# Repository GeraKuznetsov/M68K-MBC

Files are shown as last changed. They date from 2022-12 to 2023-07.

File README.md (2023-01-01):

A M68k Multi-Board Computer design. The design basics is as follows:
1) A backplane PCB contains the majority of the bus, such as the address and data lines.
2) Cards slot into the backplane. Cards other then the CPU card should have bus buffers to lower the bus load. (I might give the CPU card buffers too).
3) The 68k's 16MB memory map is split into 16 1MB regions. This is because the two memory chips used, the sst39f040 flash and AS6C4008 ram are both 0.5MB. (So when you put two of them together to get 16 bits, you end up with 1MB per bank).
4) Address decoding is done by a pair of decoders on the CPU card. The CS lines from a header on the side of the CPU card to headers on the sides of the other cards, ideally with a twisted ground for each CS line. In the future these lines could be moved into the backplane. 
5) If the card is less then 10x10 cm, I make it 4-layer. 4-layer boards bigger then 10x10cm are too expensive. 
6) the connectors are DIN41612
7) Line the 16 CS lines, the 7 interrupt lines are also jumpers you plug into the side of the board. There are also 8 interrupt enable jumpers that need to go from the IO card to the CPU card if you want to use one of the parallel output ports as an interrupt enable status port. 

IO and CPU cards are currently completely untested, and the memory card is missing a chip to enable the card's data transmitters. 

/Schematic/:
The actual MBC schematics
Note: LS components are sometimes used when the library has no corresponding HC part. All parts are meant to be HC, with the exception of LVC in 5v->3v translation (output to SD card) and HCT in 3v->5v translation (input from SD card). You can use ACT (or AC if you are feeling brave) but at <16Mhz there should not be a need for fast ACT/AC buffers/gluelogic, especially due to the 68k's slow bus cycles (in comparison to say a 6502 or a z80).

Schematics/BP - design for the backplane (TESTED)
Schematics/CPU - design for CPU card. (NOT TESTED)
Schematics/IO - design for IO card with SD card, PIO, PS2, RTC. (NOT TESTED)
Schematics/MEMv2 - second version of the memory card, doesn't even have the layout done. (NOT FINISHED)
Schematics/MEMv1 - first version of the memory card, missing 74HC20 and gate to enable the card bus buffers (TESTED)
Schematics/Footpp - various footprints
Schematics/Lib - various symbols

/Code/
WIP code, just testing stuff, will eventually be OS

/sst39f040_inBB/:
Allows you to connect an arduino mega to the backplane and program the flash chips on the memory card in-circuit. 
TODO: document this better
sst39f040_inBB/avr - the arduino mega code
sst39f040_inBB/send.py - script file to send the data, requires serial lib

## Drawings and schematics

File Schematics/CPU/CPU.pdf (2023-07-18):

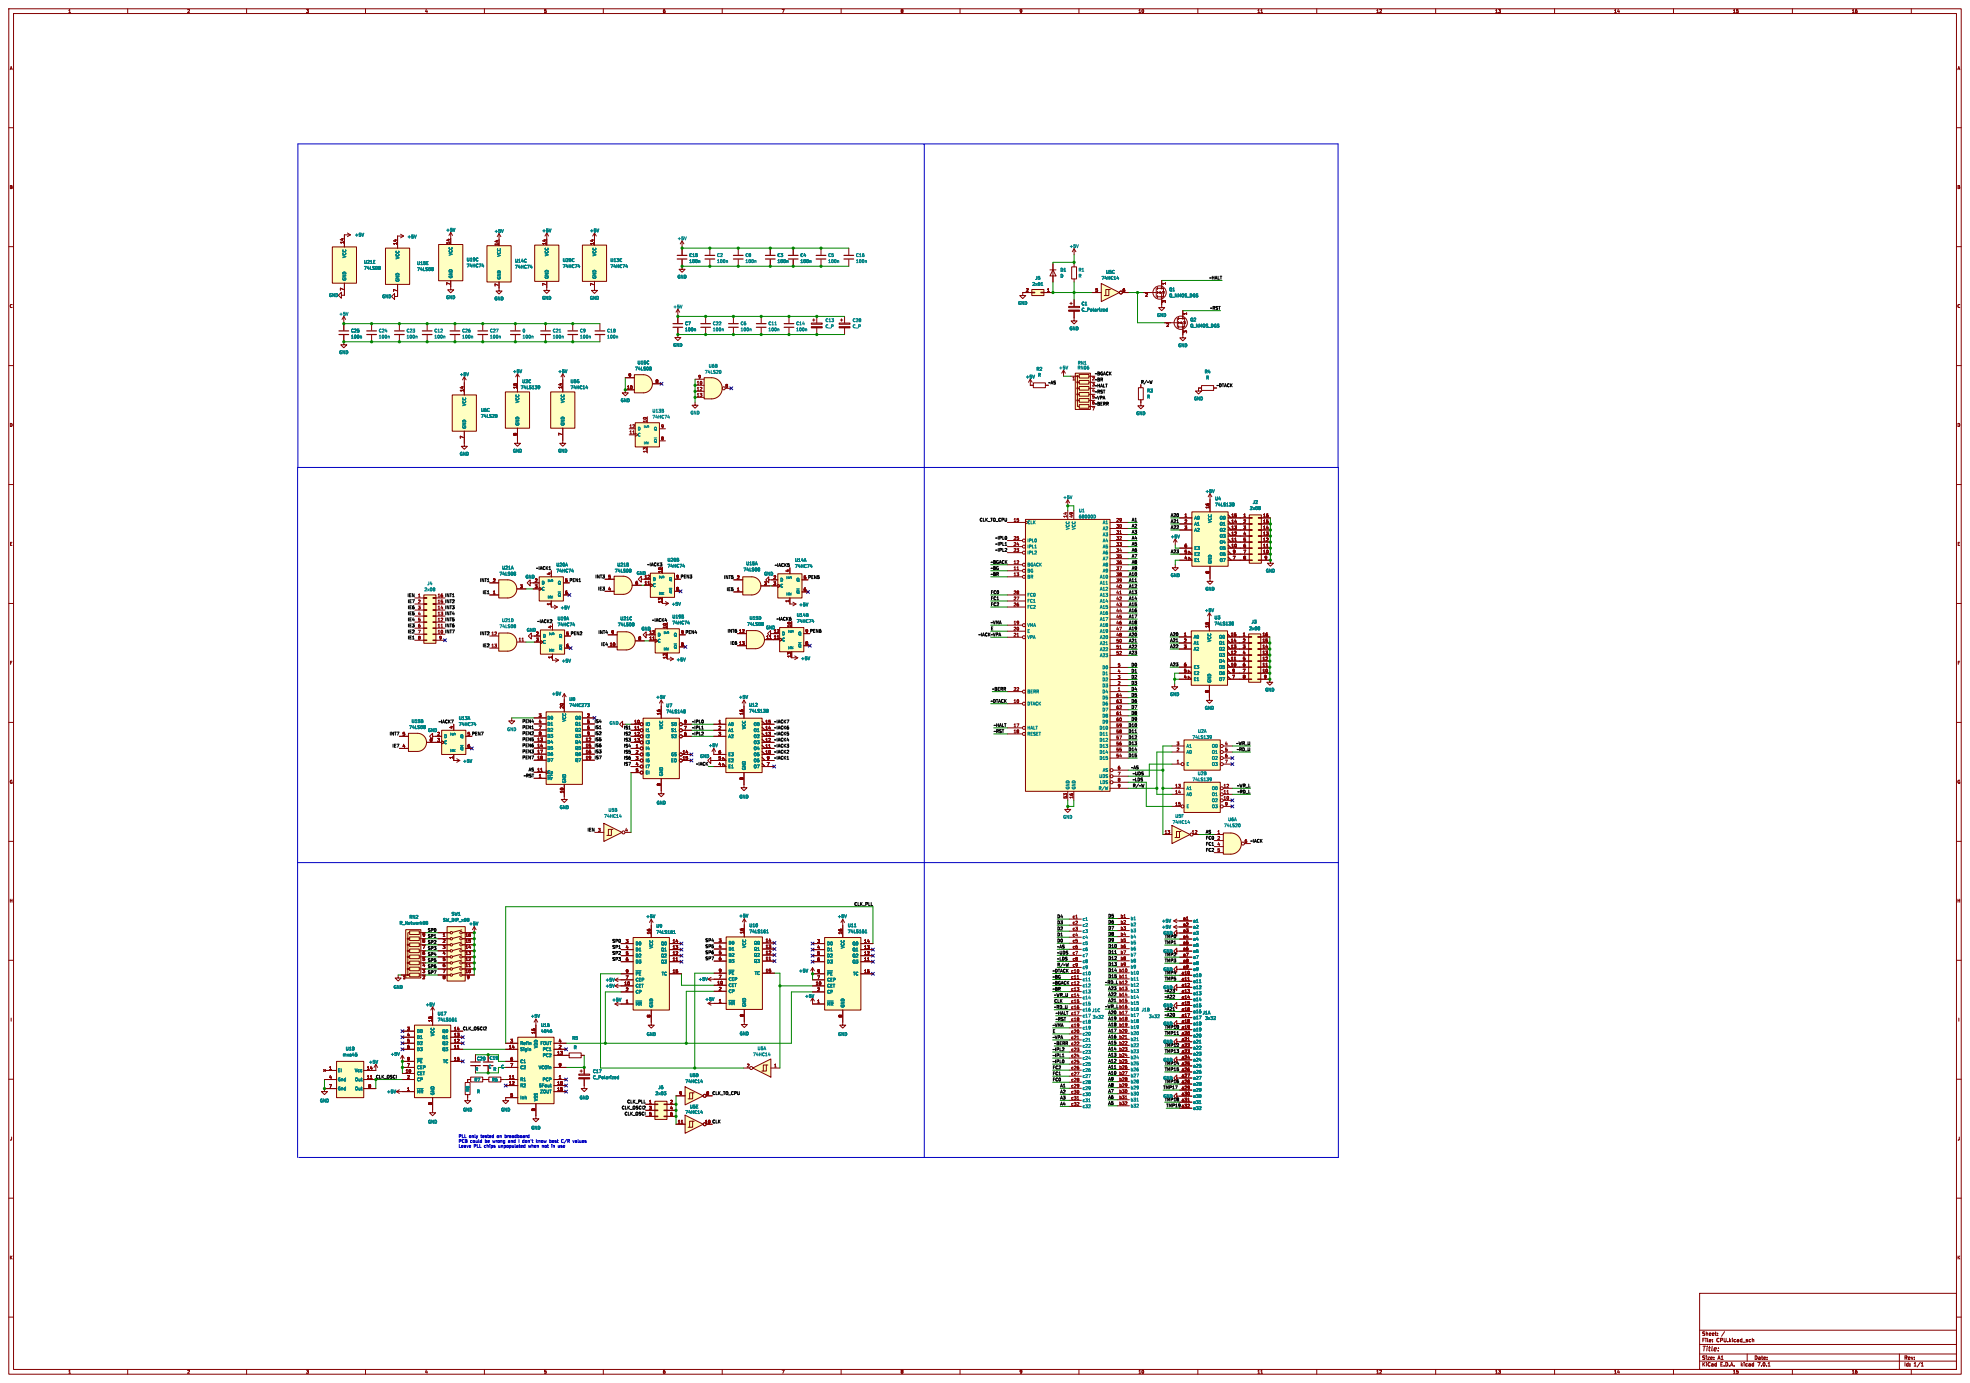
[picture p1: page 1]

Id: 1/1 Title: File: CPU.kicad_sch Sheet: /

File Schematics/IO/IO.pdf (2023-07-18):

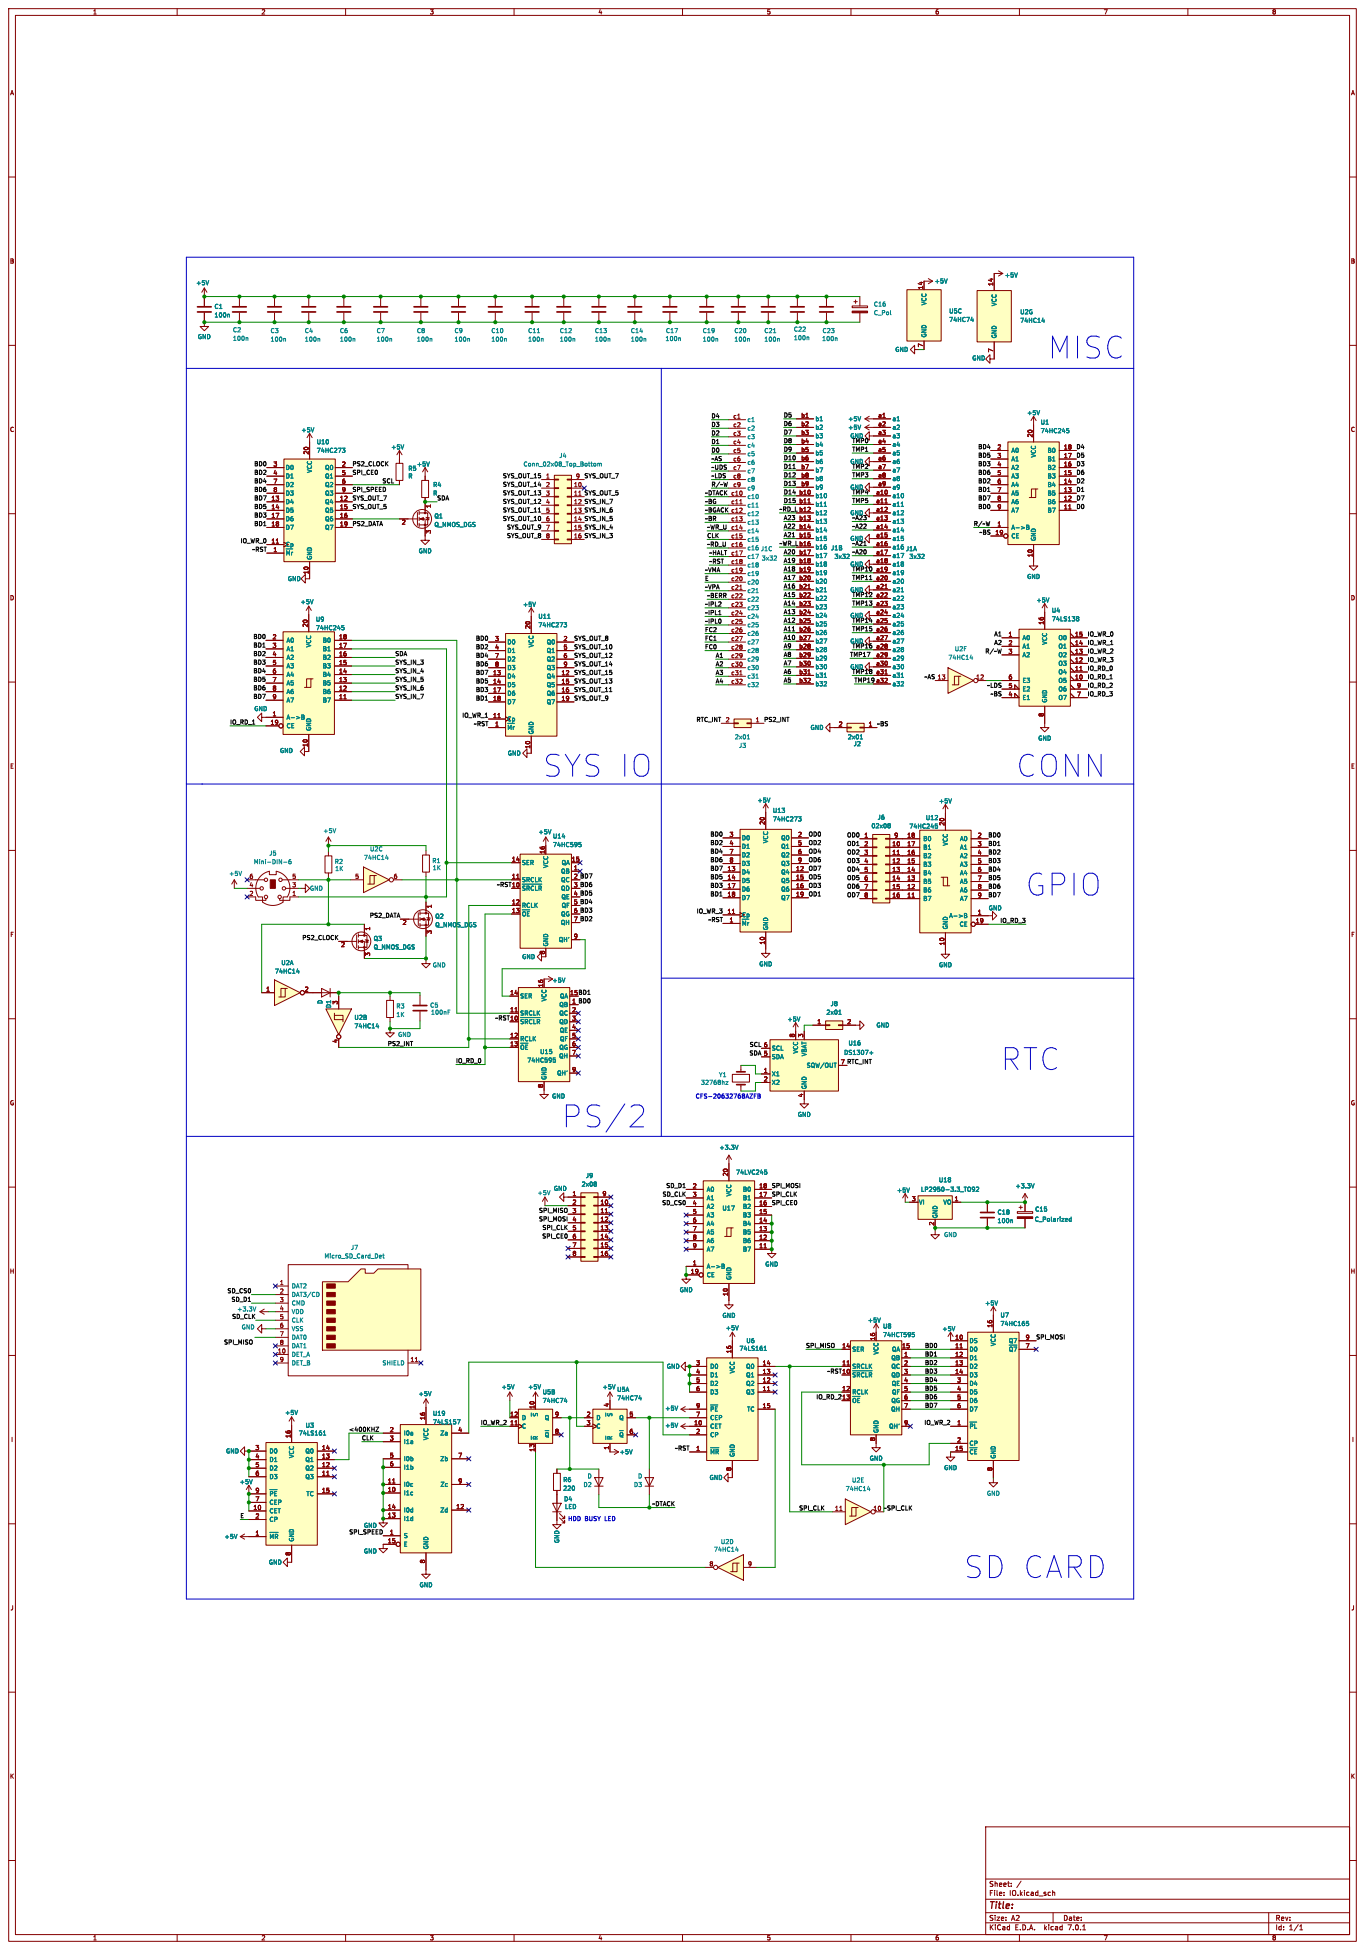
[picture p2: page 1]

7 +5V GND GND GND GND GND GND GND GND GND

HDD BUSY LED SYS IO
+5V GND

4 SDA 5 SCL 6 SQW/OUT 7 VCC

8 ~{PE} 9 +5V GND GND GND

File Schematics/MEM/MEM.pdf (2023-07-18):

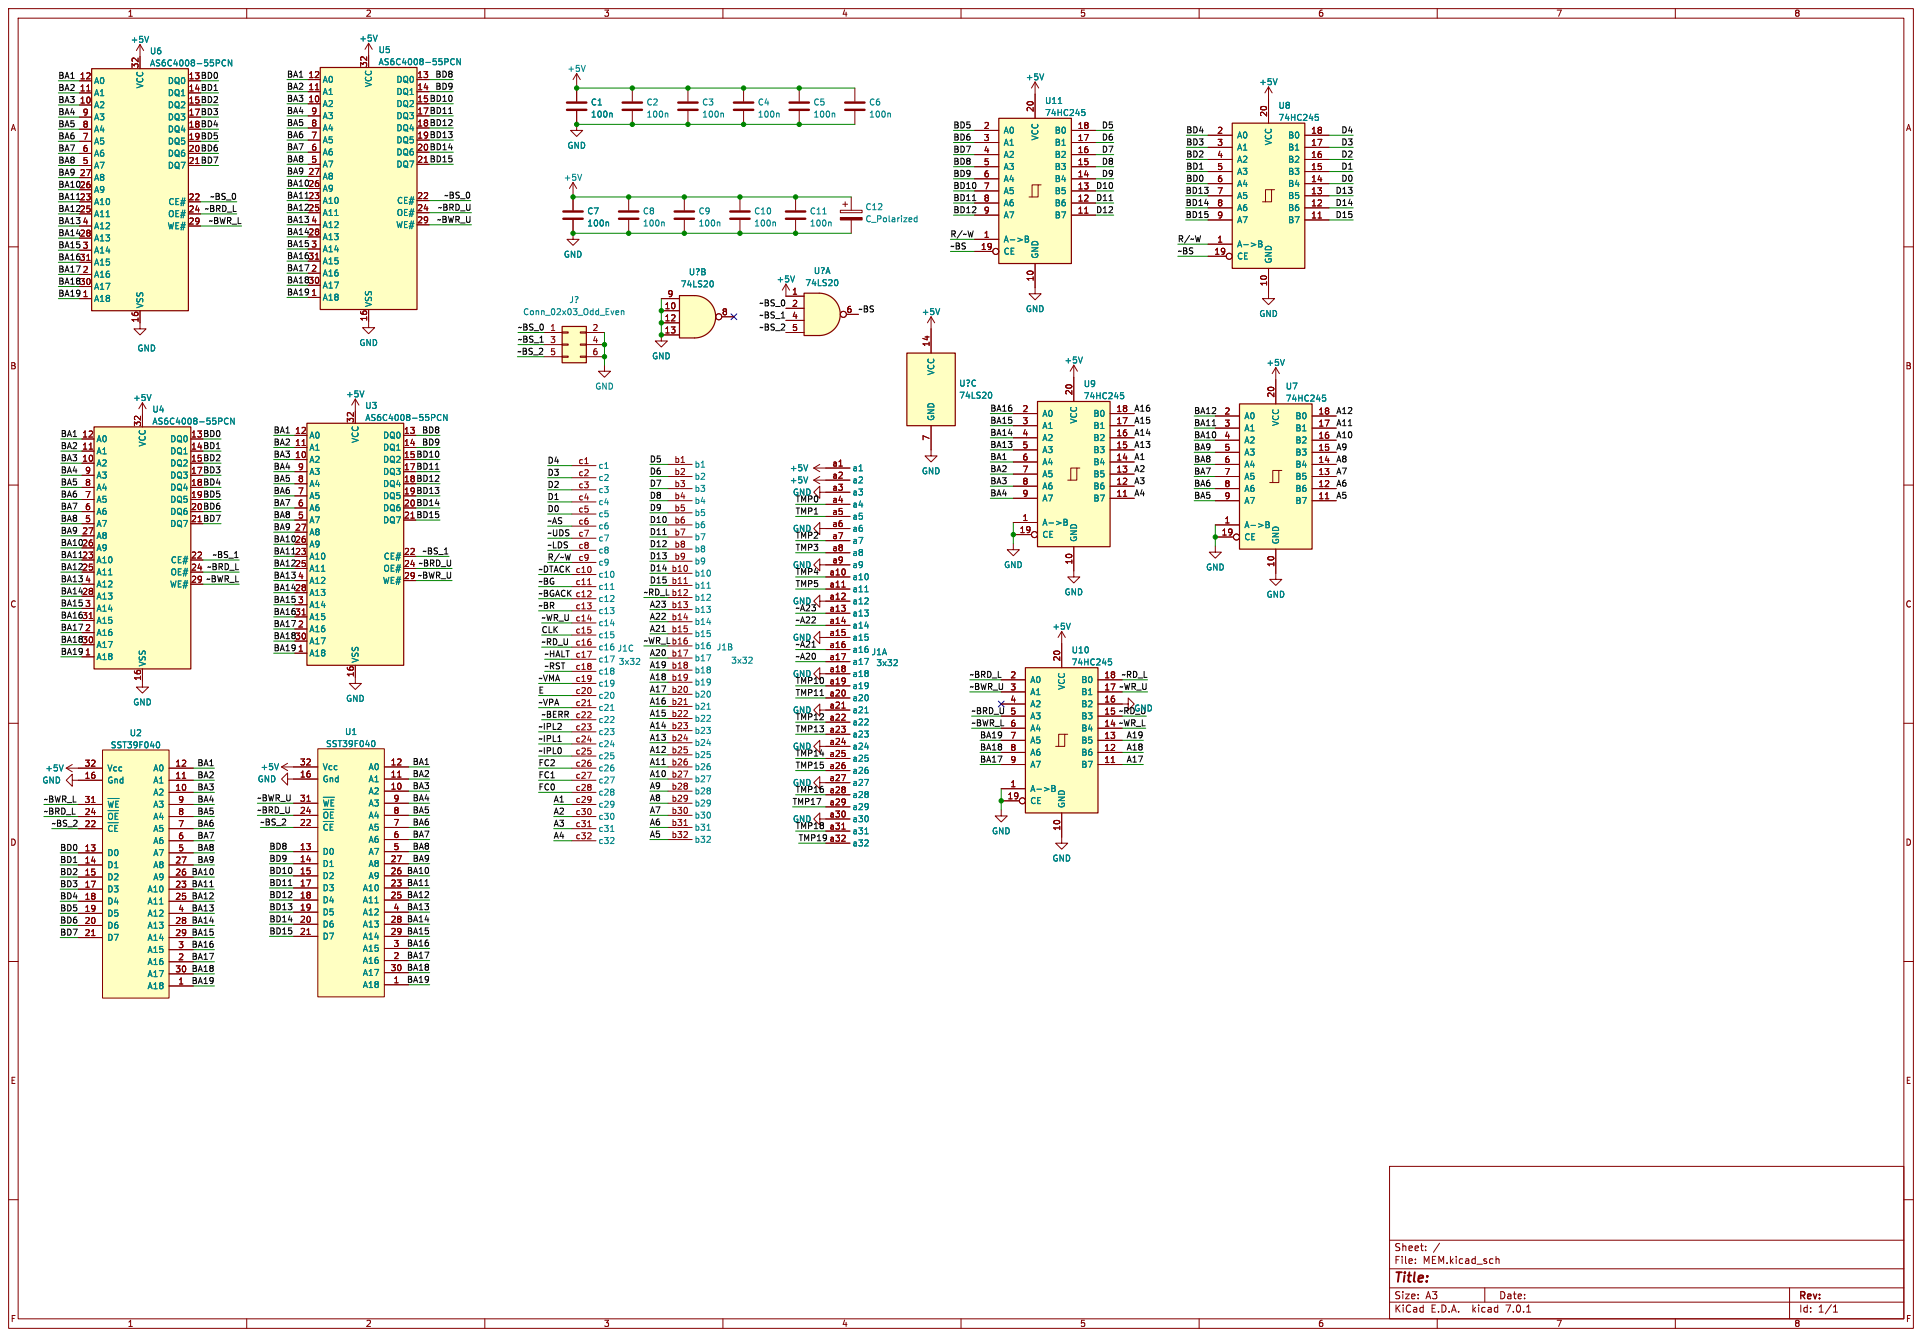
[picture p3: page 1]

+5V GND GND GND GND GND GND

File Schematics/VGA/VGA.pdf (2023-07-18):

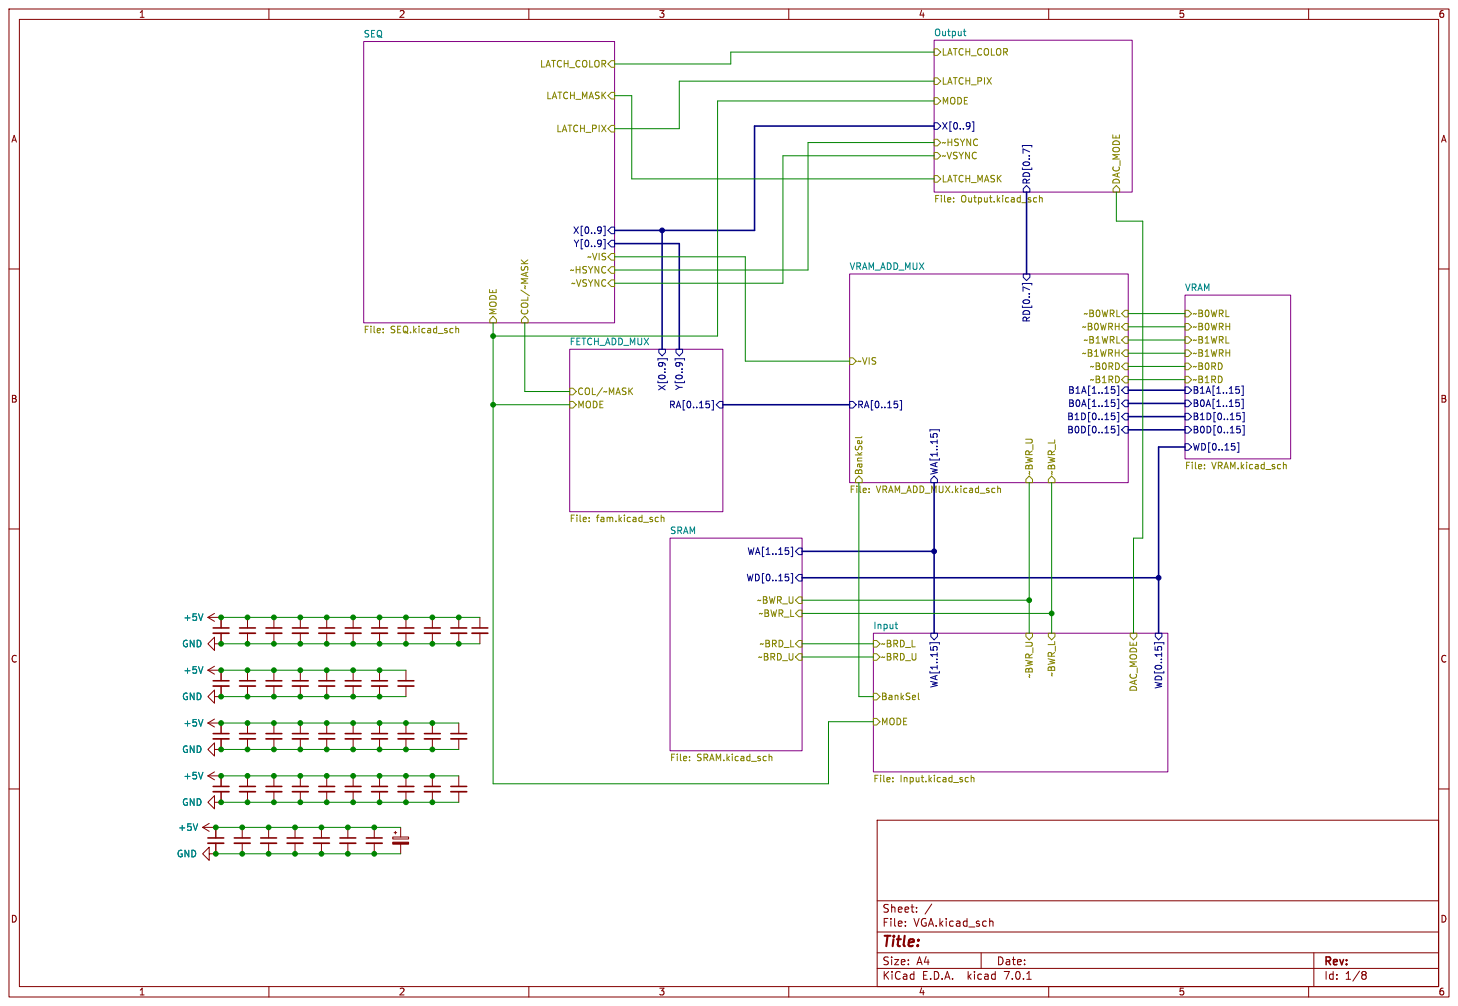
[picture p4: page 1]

Output File: Output.kicad_sch +5V GND GND
LATCH_COLOR MODE
LATCH_PIX COL/~MASK
File: fam.kicad_sch X[0..9]
Y[0..9] ~VIS

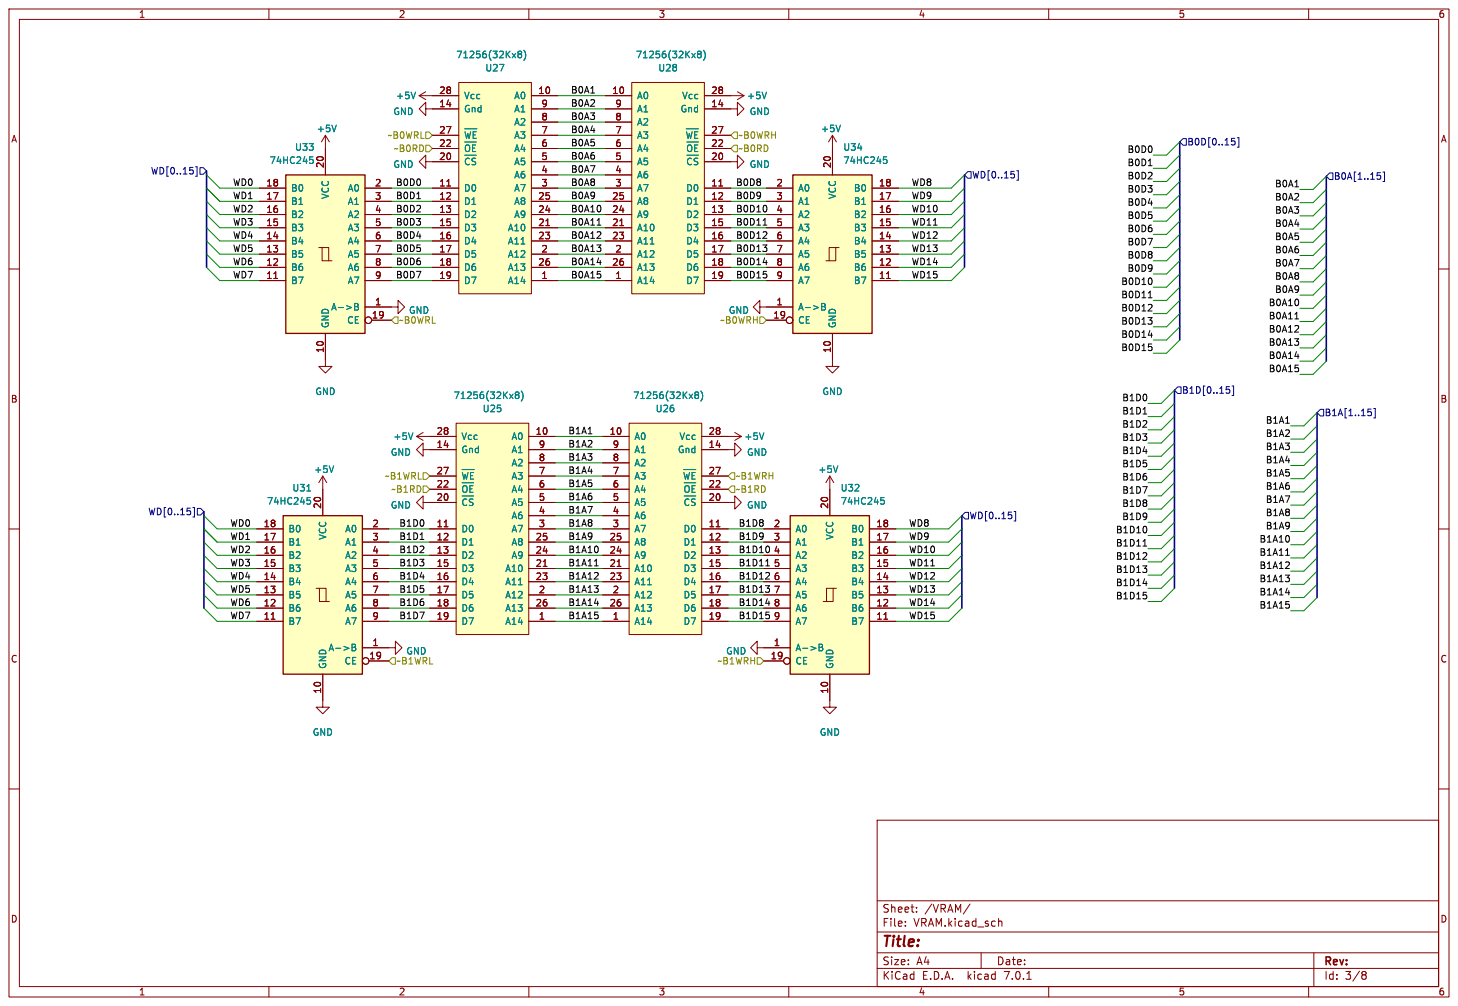
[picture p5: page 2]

Id: 3/8 Title: File: VRAM.kicad_sch Sheet: /VRAM/ GNDGND

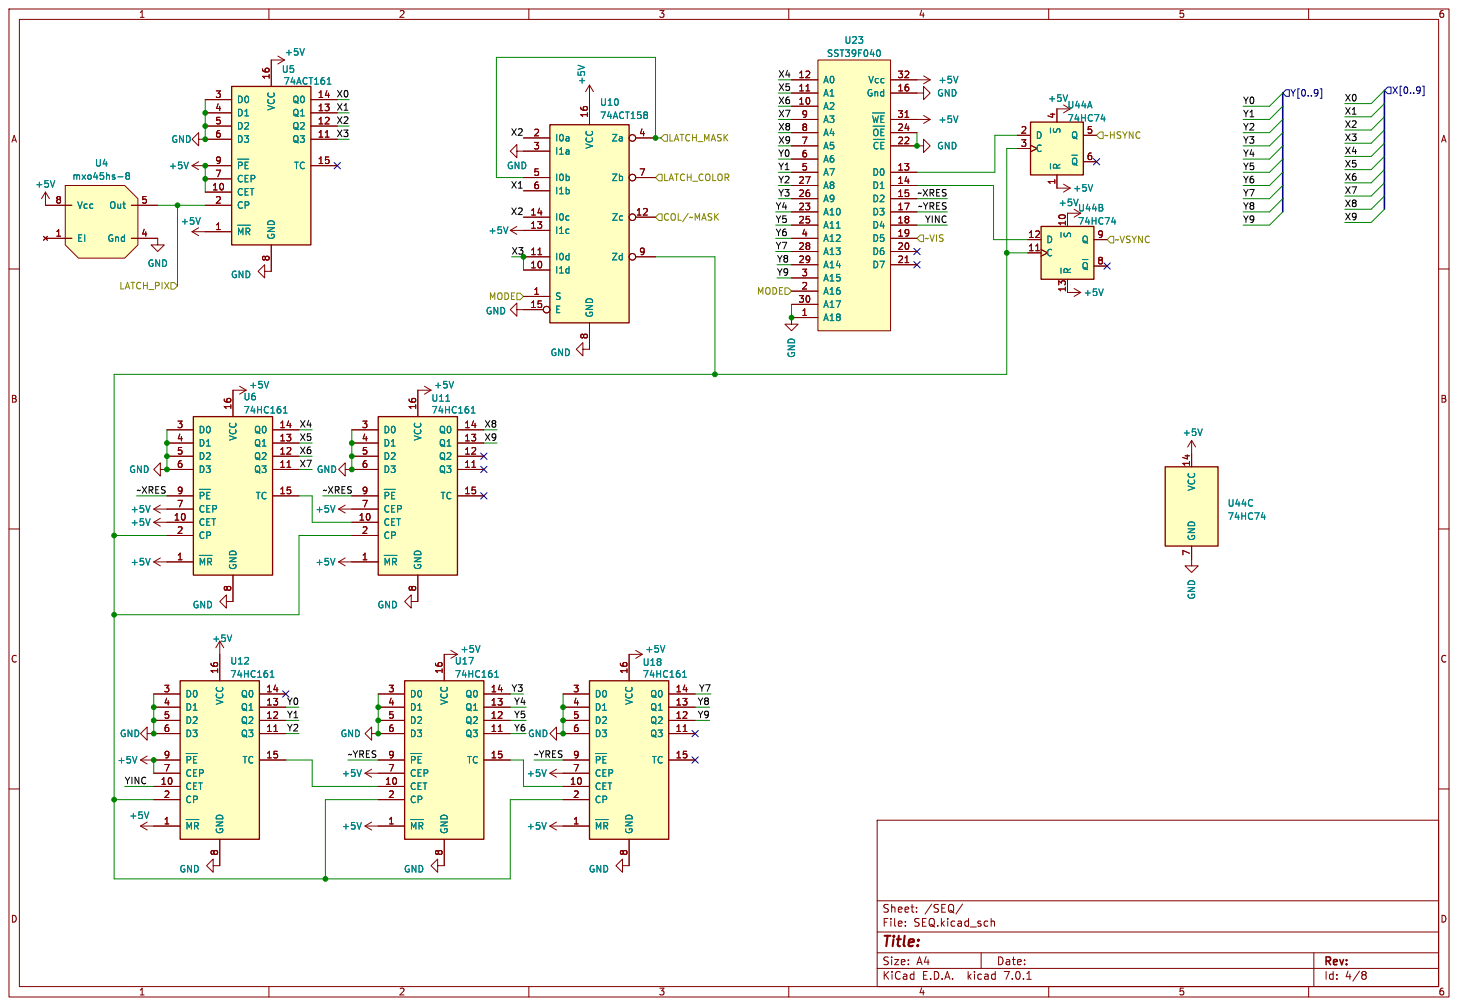
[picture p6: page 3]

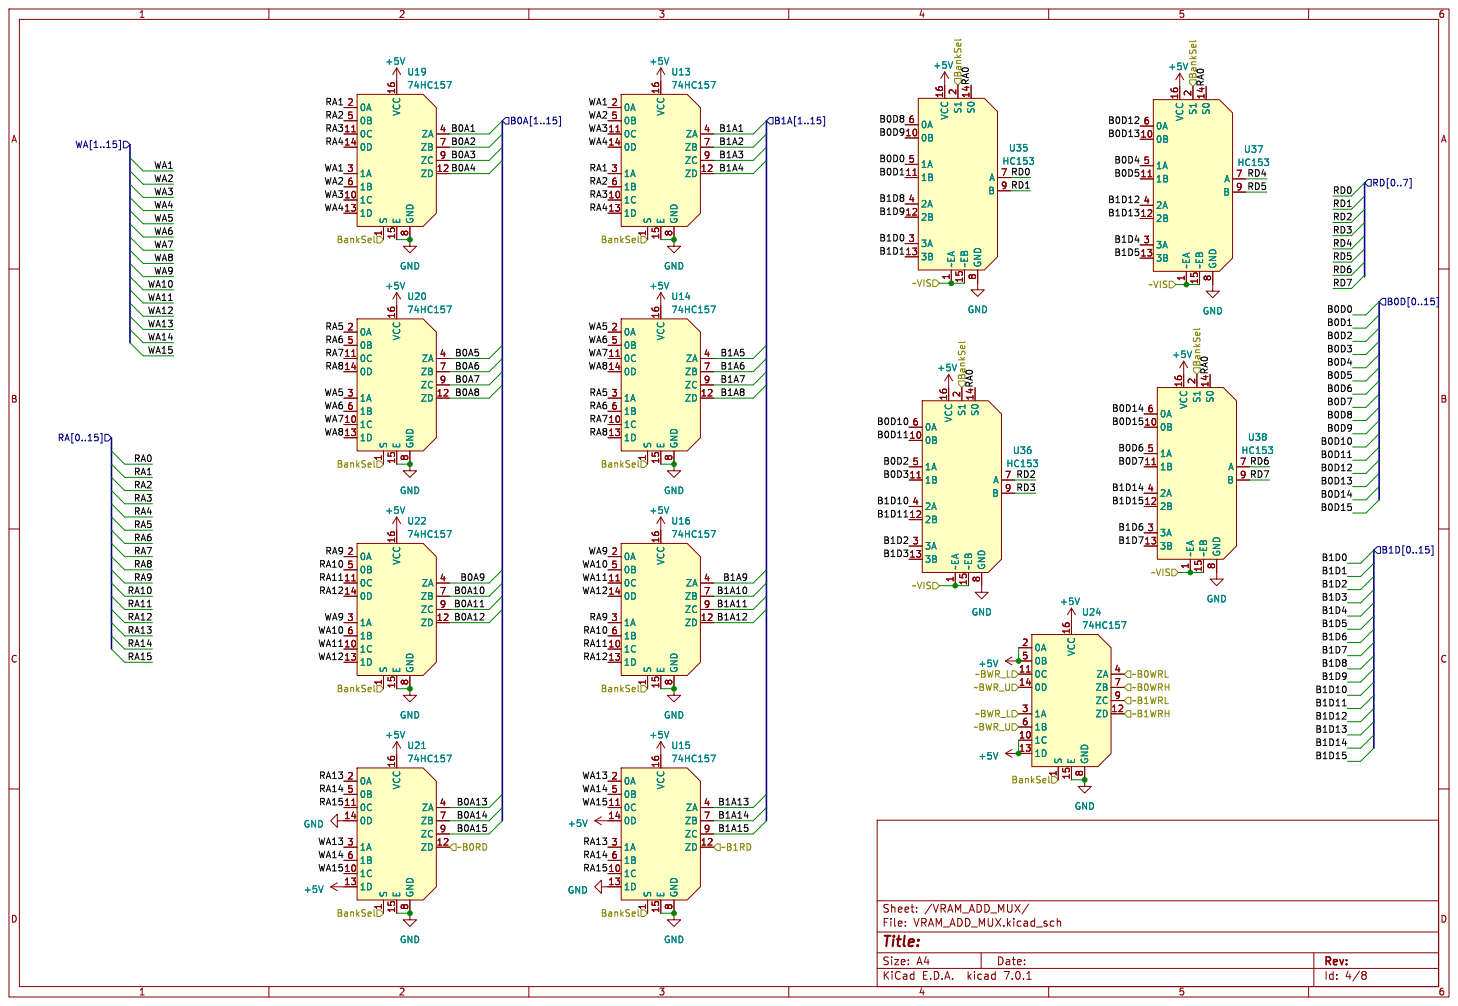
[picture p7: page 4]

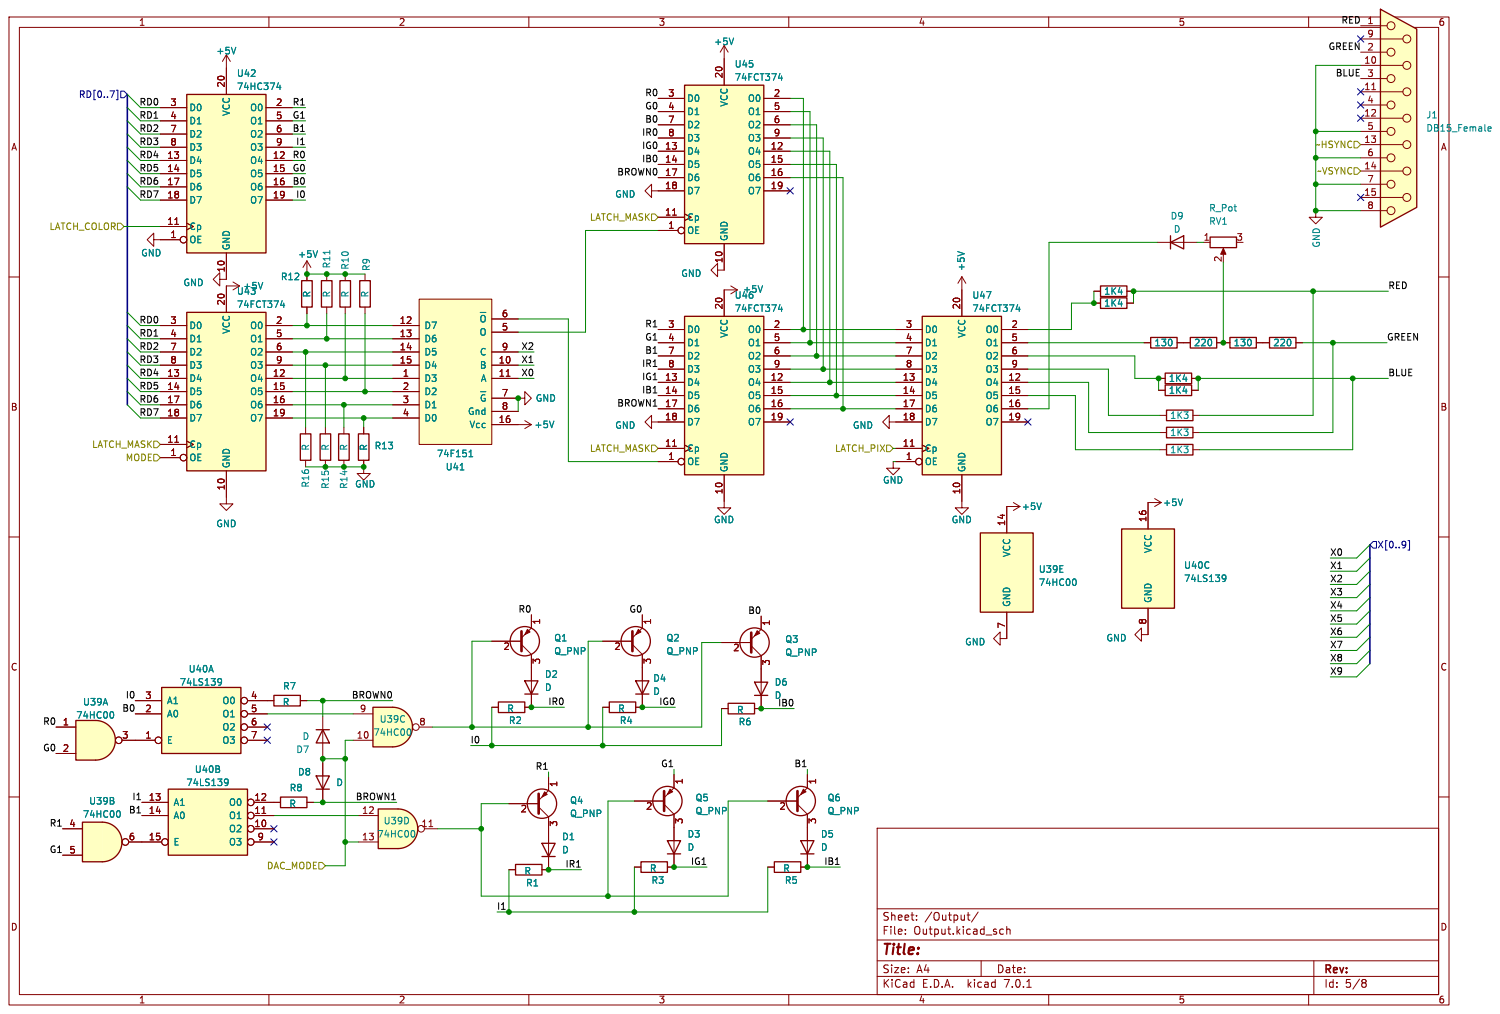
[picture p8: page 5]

Id: 5/8 Title: File: Output.kicad_sch Sheet: /Output/ 1
D3 DQ5 Q_PNP

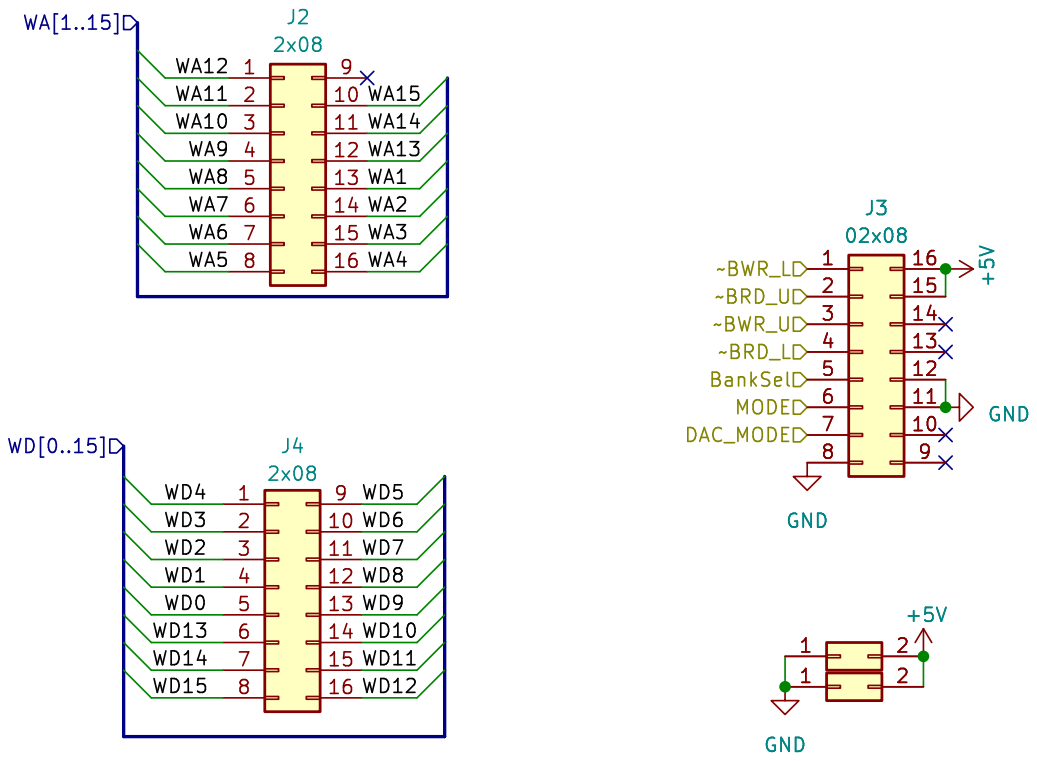
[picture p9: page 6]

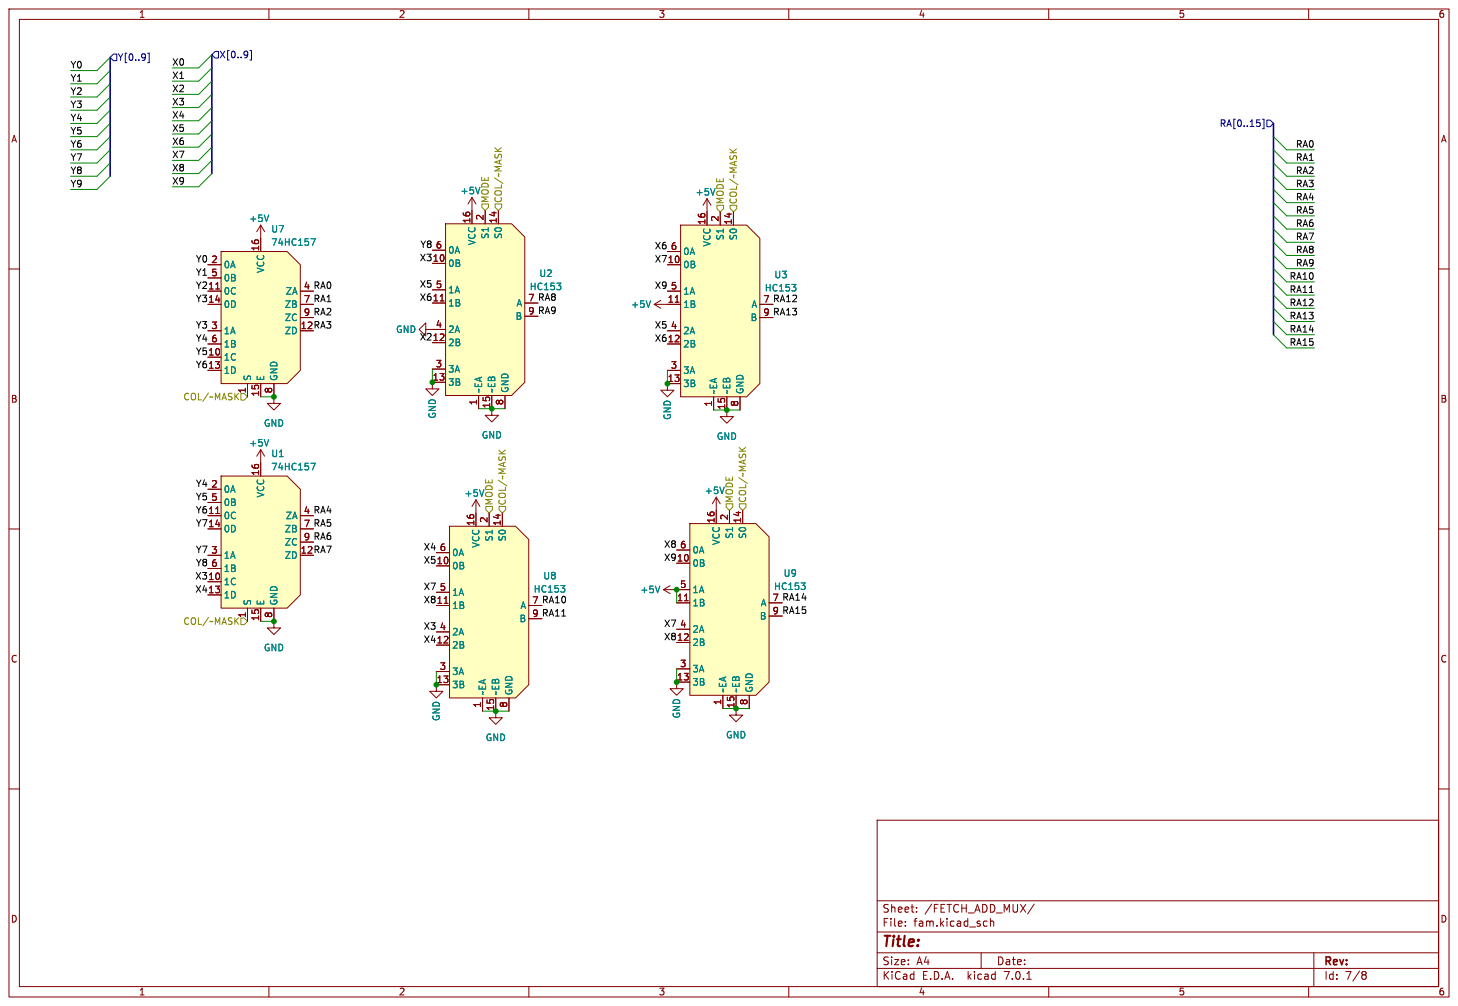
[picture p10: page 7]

Id: 7/8 Title: File: fam.kicad_sch Sheet: /FETCH_ADD_MUX/

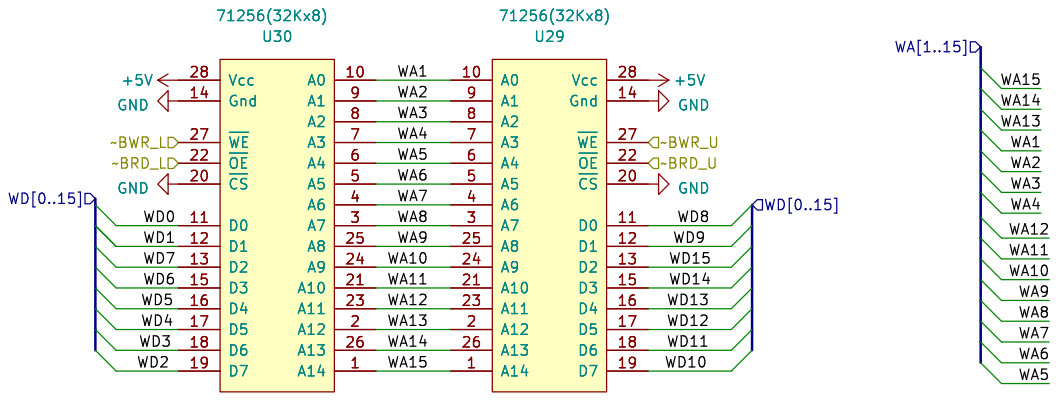
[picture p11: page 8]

Id: 8/8 Title: File: SRAM.kicad_sch Sheet: /SRAM/

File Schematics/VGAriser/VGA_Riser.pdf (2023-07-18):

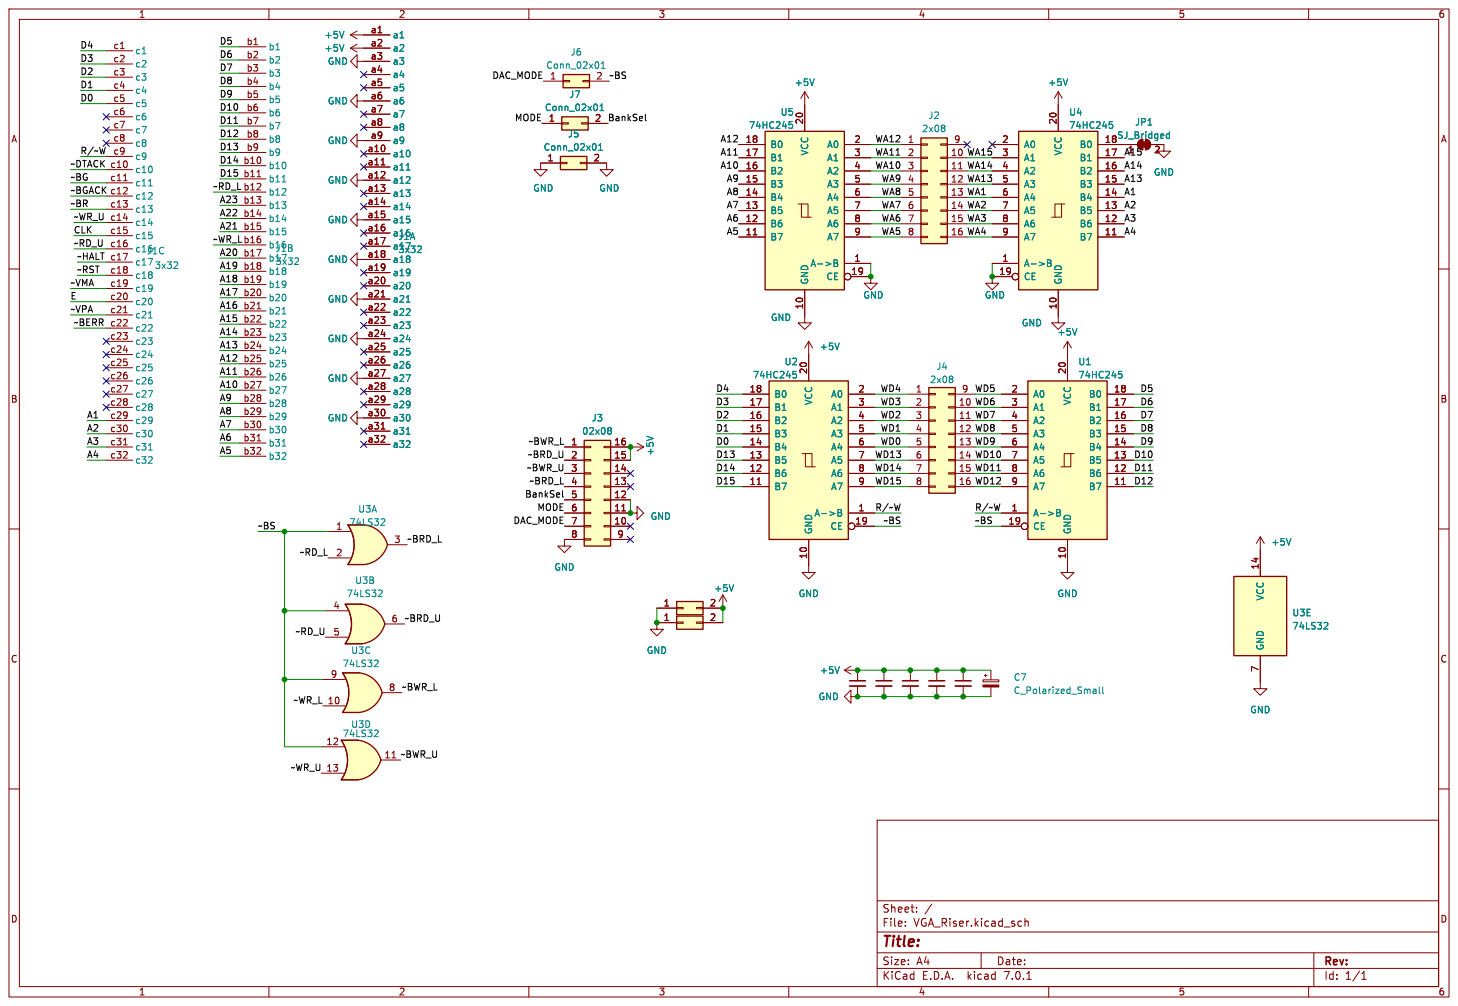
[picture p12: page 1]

Id: 1/1 Title: File: VGA_Riser.kicad_sch Sheet: /


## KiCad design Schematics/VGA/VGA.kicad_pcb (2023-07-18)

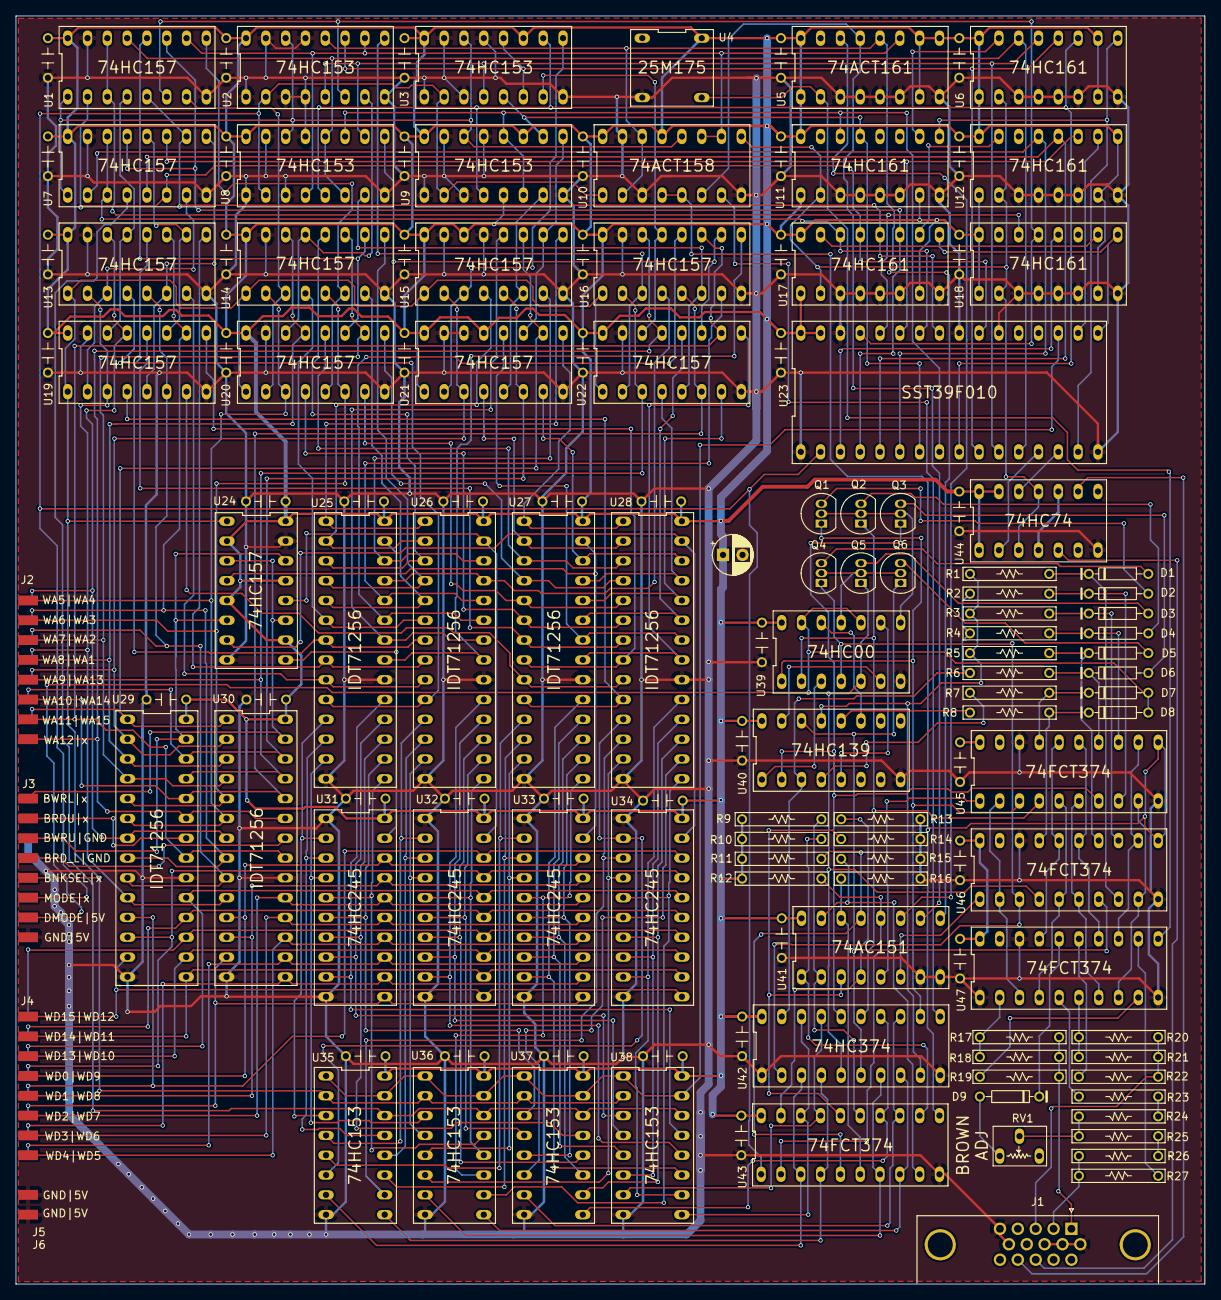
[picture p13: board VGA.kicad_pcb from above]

Board: 2 copper layers, 152.4 x 162.6 mm, 143 parts (0 on the bottom side), 229 nets.

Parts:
C1, C2, C3, C4, C5, C6, C7, C8, C9, C10, C11, C12, C13, C14, C15, C16, C17, C18, C19, C20, C21, C22, C23, C24, C25, C26, C27, C28, C29, C30, C31, C32, C33, C34, C35, C36, C37, C38, C39, C40, C41, C42, C43, C44, C45, C46: 100nF; DIP-2_200_ELL
C48: C_Polarized_Small; CP_Radial_D5.0mm_P2.50mm
D1, D2, D3, D4, D5, D6, D7, D8, D9: D
J1: DB15_Female; DSUB-15-HD_Female_Horizontal_P2.29x1.98mm_EdgePinOffset3.03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
J2, J4: 2x08; 2x08 finger
J3: 02x08; 2x08 finger
J5, J6: Conn_02x01; 2x01 finger
Q1, Q2, Q3, Q4, Q5, Q6: Q_PNP; TO-92_Inline
R1, R2, R3, R4, R5, R6, R7, R8, R9, R10, R11, R12, R13, R14, R15, R16: R; res
R17, R18, R20, R21: 1K4; res
R19, R22, R27: 1K3; res
R23, R25: 130; res
R24, R26: 220; res
RV1: R_Pot; POT
U1, U7, U13, U14, U15, U16, U19, U20, U21, U22, U24: 74HC157; DIP-16
U2, U3, U8, U9, U35, U36, U37, U38: HC153; DIP-16
U4: mxo45hs-8; DIP-2x2osci
U5: 74ACT161; DIP-16
U6, U11, U12, U17, U18: 74HC161; DIP-16
U10: 74ACT158; DIP-16
U23: SST39F040; DIP-32_600_ELL
U25, U26, U27, U28, U29, U30: 71256(32Kx8); DIP-28
U31, U32, U33, U34: 74HC245; DIP-20
U39: 74HC00; DIP-14
U40: 74LS139; DIP-16
U41: 74F151; DIP-16
U42: 74HC374; DIP-20
U43, U45, U46, U47: 74FCT374; DIP-20
U44: 74HC74; DIP-14

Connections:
+5V: C1.1, C2.1, C3.1, C4.1, C5.1, C6.1, C7.1, C8.1, C9.1, C10.1, C11.1, C12.1, C13.1, C14.1, C15.1, C16.1, C17.1, C18.1, C19.1, C20.1, C21.1, C22.1, C23.1, C24.1, C25.1, C26.1, C27.1, C28.1, C29.1, C30.1, C31.1, C32.1, C33.1, C34.1, C35.1, C36.1, C37.1, C38.1, C39.1, C40.1, C41.1, C42.1, C43.1, C44.1, C45.1, C46.1, C48.1, J3.15, J3.16, J5.2, J6.2, R9.2, R10.2, R11.2, R12.2, U1.16 (VCC), U2.16 (VCC), U3.11 (1B), U3.16 (VCC), U4.8 (Vcc), U5.1 (~MR), U5.7 (CEP), U5.9 (~PE), U5.10 (CET), U5.16 (VCC), U6.1 (~MR), U6.7 (CEP), U6.10 (CET), U6.16 (VCC), U7.16 (VCC), U8.16 (VCC), U9.5 (1A), U9.11 (1B), U9.16 (VCC), U10.13 (I1c), U10.16 (VCC), U11.1 (~MR), U11.7 (CEP), U11.16 (VCC), U12.1 (~MR), U12.7 (CEP), U12.9 (~PE), U12.16 (VCC), U13.16 (VCC), U14.16 (VCC), U15.14 (0D), U15.16 (VCC), U16.16 (VCC), U17.1 (~MR), U17.7 (CEP), U17.16 (VCC), U18.1 (~MR), U18.7 (CEP), U18.16 (VCC), U19.16 (VCC), U20.16 (VCC), U21.13 (1D), U21.16 (VCC), U22.16 (VCC), U23.31 (~WE), U23.32 (Vcc), U24.2 (0A), U24.5 (0B), U24.10 (1C), U24.13 (1D), U24.16 (VCC), U25.28 (Vcc), U26.28 (Vcc), U27.28 (Vcc), U28.28 (Vcc), U29.28 (Vcc), U30.28 (Vcc), U31.20 (VCC), U32.20 (VCC), U33.20 (VCC), U34.20 (VCC), U35.16 (VCC), U36.16 (VCC), U37.16 (VCC), U38.16 (VCC), U39.14 (VCC), U40.16 (VCC), U41.16 (Vcc), U42.20 (VCC), U43.20 (VCC), U44.1 (~R), U44.4 (~S), U44.10 (~S), U44.13 (~R), U44.14 (VCC), U45.20 (VCC), U46.20 (VCC), U47.20 (VCC)
/FETCH_ADD_MUX/COL/~MASK: U1.1 (S), U2.14 (S0), U3.14 (S0), U7.1 (S), U8.14 (S0), U9.14 (S0), U10.12 (Zc)
/FETCH_ADD_MUX/MODE: J3.6, U2.2 (S1), U3.2 (S1), U8.2 (S1), U9.2 (S1), U10.1 (S), U23.2 (A16), U43.1 (OE)
/FETCH_ADD_MUX/RA0: U7.4 (ZA), U35.14 (S0), U36.14 (S0), U37.14 (S0), U38.14 (S0)
/FETCH_ADD_MUX/RA1: U7.7 (ZB), U13.3 (1A), U19.2 (0A)
/FETCH_ADD_MUX/RA2: U7.9 (ZC), U13.6 (1B), U19.5 (0B)
/FETCH_ADD_MUX/RA3: U7.12 (ZD), U13.10 (1C), U19.11 (0C)
/FETCH_ADD_MUX/RA4: U1.4 (ZA), U13.13 (1D), U19.14 (0D)
/FETCH_ADD_MUX/RA5: U1.7 (ZB), U14.3 (1A), U20.2 (0A)
/FETCH_ADD_MUX/RA6: U1.9 (ZC), U14.6 (1B), U20.5 (0B)
/FETCH_ADD_MUX/RA7: U1.12 (ZD), U14.10 (1C), U20.11 (0C)
/FETCH_ADD_MUX/RA8: U2.7 (A), U14.13 (1D), U20.14 (0D)
/FETCH_ADD_MUX/RA9: U2.9 (B), U16.3 (1A), U22.2 (0A)
/FETCH_ADD_MUX/RA10: U8.7 (A), U16.6 (1B), U22.5 (0B)
/FETCH_ADD_MUX/RA11: U8.9 (B), U16.10 (1C), U22.11 (0C)
/FETCH_ADD_MUX/RA12: U3.7 (A), U16.13 (1D), U22.14 (0D)
/FETCH_ADD_MUX/RA13: U3.9 (B), U15.3 (1A), U21.2 (0A)
/FETCH_ADD_MUX/RA14: U9.7 (A), U15.6 (1B), U21.5 (0B)
/FETCH_ADD_MUX/RA15: U9.9 (B), U15.10 (1C), U21.11 (0C)
/FETCH_ADD_MUX/X0: U5.14 (Q0), U41.11 (A)
/FETCH_ADD_MUX/X1: U5.13 (Q1), U10.6 (I1b), U41.10 (B)
/FETCH_ADD_MUX/X2: U2.12 (2B), U5.12 (Q2), U10.2 (I0a), U10.14 (I0c), U41.9 (C)
/FETCH_ADD_MUX/X3: U1.10 (1C), U2.10 (0B), U5.11 (Q3), U8.4 (2A), U10.10 (I1d), U10.11 (I0d)
/FETCH_ADD_MUX/X4: U1.13 (1D), U6.14 (Q0), U8.6 (0A), U8.12 (2B), U23.12 (A0)
/FETCH_ADD_MUX/X5: U2.5 (1A), U3.4 (2A), U6.13 (Q1), U8.10 (0B), U23.11 (A1)
/FETCH_ADD_MUX/X6: U2.11 (1B), U3.6 (0A), U3.12 (2B), U6.12 (Q2), U23.10 (A2)
/FETCH_ADD_MUX/X7: U3.10 (0B), U6.11 (Q3), U8.5 (1A), U9.4 (2A), U23.9 (A3)
/FETCH_ADD_MUX/X8: U8.11 (1B), U9.6 (0A), U9.12 (2B), U11.14 (Q0), U23.8 (A4)
/FETCH_ADD_MUX/X9: U3.5 (1A), U9.10 (0B), U11.13 (Q1), U23.7 (A5)
/FETCH_ADD_MUX/Y0: U7.2 (0A), U12.13 (Q1), U23.6 (A6)
/FETCH_ADD_MUX/Y1: U7.5 (0B), U12.12 (Q2), U23.5 (A7)
/FETCH_ADD_MUX/Y2: U7.11 (0C), U12.11 (Q3), U23.27 (A8)
/FETCH_ADD_MUX/Y3: U7.3 (1A), U7.14 (0D), U17.14 (Q0), U23.26 (A9)
/FETCH_ADD_MUX/Y4: U1.2 (0A), U7.6 (1B), U17.13 (Q1), U23.23 (A10)
/FETCH_ADD_MUX/Y5: U1.5 (0B), U7.10 (1C), U17.12 (Q2), U23.25 (A11)
/FETCH_ADD_MUX/Y6: U1.11 (0C), U7.13 (1D), U17.11 (Q3), U23.4 (A12)
/FETCH_ADD_MUX/Y7: U1.3 (1A), U1.14 (0D), U18.14 (Q0), U23.28 (A13)
/FETCH_ADD_MUX/Y8: U1.6 (1B), U2.6 (0A), U18.13 (Q1), U23.29 (A14)
/FETCH_ADD_MUX/Y9: U18.12 (Q2), U23.3 (A15)
/Input/BankSel: J3.5, U13.1 (S), U14.1 (S), U15.1 (S), U16.1 (S), U19.1 (S), U20.1 (S), U21.1 (S), U22.1 (S), U24.1 (S), U35.2 (S1), U36.2 (S1), U37.2 (S1), U38.2 (S1)
/Input/DAC_MODE: D7.2 (A), D8.2 (A), J3.7, U39.10, U39.13
/Input/WA1: J2.13, U13.2 (0A), U19.3 (1A), U29.10 (A0), U30.10 (A0)
/Input/WA2: J2.14, U13.5 (0B), U19.6 (1B), U29.9 (A1), U30.9 (A1)
/Input/WA3: J2.15, U13.11 (0C), U19.10 (1C), U29.8 (A2), U30.8 (A2)
/Input/WA4: J2.16, U13.14 (0D), U19.13 (1D), U29.7 (A3), U30.7 (A3)
/Input/WA5: J2.8, U14.2 (0A), U20.3 (1A), U29.6 (A4), U30.6 (A4)
/Input/WA6: J2.7, U14.5 (0B), U20.6 (1B), U29.5 (A5), U30.5 (A5)
/Input/WA7: J2.6, U14.11 (0C), U20.10 (1C), U29.4 (A6), U30.4 (A6)
/Input/WA8: J2.5, U14.14 (0D), U20.13 (1D), U29.3 (A7), U30.3 (A7)
/Input/WA9: J2.4, U16.2 (0A), U22.3 (1A), U29.25 (A8), U30.25 (A8)
/Input/WA10: J2.3, U16.5 (0B), U22.6 (1B), U29.24 (A9), U30.24 (A9)
/Input/WA11: J2.2, U16.11 (0C), U22.10 (1C), U29.21 (A10), U30.21 (A10)
/Input/WA12: J2.1, U16.14 (0D), U22.13 (1D), U29.23 (A11), U30.23 (A11)
/Input/WA13: J2.12, U15.2 (0A), U21.3 (1A), U29.2 (A12), U30.2 (A12)
/Input/WA14: J2.11, U15.5 (0B), U21.6 (1B), U29.26 (A13), U30.26 (A13)
/Input/WA15: J2.10, U15.11 (0C), U21.10 (1C), U29.1 (A14), U30.1 (A14)
/Input/WD0: J4.5, U30.11 (D0), U31.18 (B0), U33.18 (B0)
/Input/WD1: J4.4, U30.12 (D1), U31.17 (B1), U33.17 (B1)
/Input/WD2: J4.3, U30.19 (D7), U31.16 (B2), U33.16 (B2)
/Input/WD3: J4.2, U30.18 (D6), U31.15 (B3), U33.15 (B3)
/Input/WD4: J4.1, U30.17 (D5), U31.14 (B4), U33.14 (B4)
/Input/WD5: J4.9, U30.16 (D4), U31.13 (B5), U33.13 (B5)
/Input/WD6: J4.10, U30.15 (D3), U31.12 (B6), U33.12 (B6)
/Input/WD7: J4.11, U30.13 (D2), U31.11 (B7), U33.11 (B7)
/Input/WD8: J4.12, U29.11 (D0), U32.18 (B0), U34.18 (B0)
/Input/WD9: J4.13, U29.12 (D1), U32.17 (B1), U34.17 (B1)
/Input/WD10: J4.14, U29.19 (D7), U32.16 (B2), U34.16 (B2)
/Input/WD11: J4.15, U29.18 (D6), U32.15 (B3), U34.15 (B3)
/Input/WD12: J4.16, U29.17 (D5), U32.14 (B4), U34.14 (B4)
/Input/WD13: J4.6, U29.16 (D4), U32.13 (B5), U34.13 (B5)
/Input/WD14: J4.7, U29.15 (D3), U32.12 (B6), U34.12 (B6)
/Input/WD15: J4.8, U29.13 (D2), U32.11 (B7), U34.11 (B7)
/Input/~BRD_L: J3.4, U30.22 (~OE)
/Input/~BRD_U: J3.2, U29.22 (~OE)
/Input/~BWR_L: J3.1, U24.3 (1A), U24.11 (0C), U30.27 (~WE)
/Input/~BWR_U: J3.3, U24.6 (1B), U24.14 (0D), U29.27 (~WE)
/Output/B0: Q3.1 (E), U40.2 (A0), U42.16 (O6), U45.7 (D2)
/Output/B1: Q6.1 (E), U40.14 (A0), U42.6 (O2), U46.7 (D2)
/Output/BLUE: J1.3, R20.2, R21.2, R22.2
/Output/BROWN0: D7.1 (K), R7.1, U45.17 (D6)
/Output/BROWN1: D8.1 (K), R8.1, U46.17 (D6)
/Output/G0: Q2.1 (E), U39.2, U42.15 (O5), U45.4 (D1)
/Output/G1: Q5.1 (E), U39.5, U42.5 (O1), U46.4 (D1)
/Output/GREEN: J1.2, R26.1, R27.2
/Output/I0: R2.2, R4.2, R6.2, U40.3 (A1), U42.19 (O7)
/Output/I1: R1.2, R3.2, R5.2, U40.13 (A1), U42.9 (O3)
/Output/IB0: D6.1 (K), R6.1, U45.14 (D5)
/Output/IB1: D5.1 (K), R5.1, U46.14 (D5)
/Output/IG0: D4.1 (K), R4.1, U45.13 (D4)
/Output/IG1: D3.1 (K), R3.1, U46.13 (D4)
/Output/IR0: D2.1 (K), R2.1, U45.8 (D3)
/Output/IR1: D1.1 (K), R1.1, U46.8 (D3)
/Output/LATCH_COLOR: U10.7 (Zb), U42.11 (Cp)
/Output/LATCH_MASK: U10.4 (Za), U10.5 (I0b), U43.11 (Cp), U45.11 (Cp), U46.11 (Cp)
/Output/LATCH_PIX: U4.5 (Out), U5.2 (CP), U47.11 (Cp)
/Output/R0: Q1.1 (E), U39.1, U42.12 (O4), U45.3 (D0)
/Output/R1: Q4.1 (E), U39.4, U42.2 (O0), U46.3 (D0)
/Output/RD0: U35.7 (A), U42.3 (D0), U43.3 (D0)
/Output/RD1: U35.9 (B), U42.4 (D1), U43.4 (D1)
/Output/RD2: U36.7 (A), U42.7 (D2), U43.7 (D2)
/Output/RD3: U36.9 (B), U42.8 (D3), U43.8 (D3)
/Output/RD4: U37.7 (A), U42.13 (D4), U43.13 (D4)
/Output/RD5: U37.9 (B), U42.14 (D5), U43.14 (D5)
/Output/RD6: U38.7 (A), U42.17 (D6), U43.17 (D6)
/Output/RD7: U38.9 (B), U42.18 (D7), U43.18 (D7)
/Output/RED: J1.1, R17.2, R18.2, R19.2
/Output/~HSYNC: J1.13, U44.5 (Q)
/Output/~VSYNC: J1.14, U44.9 (Q)
/SEQ/YINC: U12.10 (CET), U23.18 (D4)
/SEQ/~VIS: U23.19 (D5), U35.1 (~EA), U35.15 (~EB), U36.1 (~EA), U36.15 (~EB), U37.1 (~EA), U37.15 (~EB), U38.1 (~EA), U38.15 (~EB)
/SEQ/~XRES: U6.9 (~PE), U11.9 (~PE), U23.15 (D2)
/SEQ/~YRES: U17.9 (~PE), U18.9 (~PE), U23.17 (D3)
/VRAM/B0A1: U19.4 (ZA), U27.10 (A0), U28.10 (A0)
/VRAM/B0A2: U19.7 (ZB), U27.9 (A1), U28.9 (A1)
/VRAM/B0A3: U19.9 (ZC), U27.8 (A2), U28.8 (A2)
/VRAM/B0A4: U19.12 (ZD), U27.7 (A3), U28.7 (A3)
/VRAM/B0A5: U20.4 (ZA), U27.6 (A4), U28.6 (A4)
/VRAM/B0A6: U20.7 (ZB), U27.5 (A5), U28.5 (A5)
/VRAM/B0A7: U20.9 (ZC), U27.4 (A6), U28.4 (A6)
/VRAM/B0A8: U20.12 (ZD), U27.3 (A7), U28.3 (A7)
/VRAM/B0A9: U22.4 (ZA), U27.25 (A8), U28.25 (A8)
/VRAM/B0A10: U22.7 (ZB), U27.24 (A9), U28.24 (A9)
/VRAM/B0A11: U22.9 (ZC), U27.21 (A10), U28.21 (A10)
/VRAM/B0A12: U22.12 (ZD), U27.23 (A11), U28.23 (A11)
/VRAM/B0A13: U21.4 (ZA), U27.2 (A12), U28.2 (A12)
/VRAM/B0A14: U21.7 (ZB), U27.26 (A13), U28.26 (A13)
/VRAM/B0A15: U21.9 (ZC), U27.1 (A14), U28.1 (A14)
/VRAM/B0D0: U27.11 (D0), U33.2 (A0), U35.5 (1A)
/VRAM/B0D1: U27.12 (D1), U33.3 (A1), U35.11 (1B)
/VRAM/B0D2: U27.13 (D2), U33.4 (A2), U36.5 (1A)
/VRAM/B0D3: U27.15 (D3), U33.5 (A3), U36.11 (1B)
/VRAM/B0D4: U27.16 (D4), U33.6 (A4), U37.5 (1A)
/VRAM/B0D5: U27.17 (D5), U33.7 (A5), U37.11 (1B)
/VRAM/B0D6: U27.18 (D6), U33.8 (A6), U38.5 (1A)
/VRAM/B0D7: U27.19 (D7), U33.9 (A7), U38.11 (1B)
/VRAM/B0D8: U28.11 (D0), U34.2 (A0), U35.6 (0A)
/VRAM/B0D9: U28.12 (D1), U34.3 (A1), U35.10 (0B)
/VRAM/B0D10: U28.13 (D2), U34.4 (A2), U36.6 (0A)
/VRAM/B0D11: U28.15 (D3), U34.5 (A3), U36.10 (0B)
/VRAM/B0D12: U28.16 (D4), U34.6 (A4), U37.6 (0A)
/VRAM/B0D13: U28.17 (D5), U34.7 (A5), U37.10 (0B)
/VRAM/B0D14: U28.18 (D6), U34.8 (A6), U38.6 (0A)
/VRAM/B0D15: U28.19 (D7), U34.9 (A7), U38.10 (0B)
/VRAM/B1A1: U13.4 (ZA), U25.10 (A0), U26.10 (A0)
/VRAM/B1A2: U13.7 (ZB), U25.9 (A1), U26.9 (A1)
/VRAM/B1A3: U13.9 (ZC), U25.8 (A2), U26.8 (A2)
/VRAM/B1A4: U13.12 (ZD), U25.7 (A3), U26.7 (A3)
/VRAM/B1A5: U14.4 (ZA), U25.6 (A4), U26.6 (A4)
/VRAM/B1A6: U14.7 (ZB), U25.5 (A5), U26.5 (A5)
/VRAM/B1A7: U14.9 (ZC), U25.4 (A6), U26.4 (A6)
/VRAM/B1A8: U14.12 (ZD), U25.3 (A7), U26.3 (A7)
/VRAM/B1A9: U16.4 (ZA), U25.25 (A8), U26.25 (A8)
/VRAM/B1A10: U16.7 (ZB), U25.24 (A9), U26.24 (A9)
/VRAM/B1A11: U16.9 (ZC), U25.21 (A10), U26.21 (A10)
/VRAM/B1A12: U16.12 (ZD), U25.23 (A11), U26.23 (A11)
/VRAM/B1A13: U15.4 (ZA), U25.2 (A12), U26.2 (A12)
/VRAM/B1A14: U15.7 (ZB), U25.26 (A13), U26.26 (A13)
/VRAM/B1A15: U15.9 (ZC), U25.1 (A14), U26.1 (A14)
/VRAM/B1D0: U25.11 (D0), U31.2 (A0), U35.3 (3A)
/VRAM/B1D1: U25.12 (D1), U31.3 (A1), U35.13 (3B)
/VRAM/B1D2: U25.13 (D2), U31.4 (A2), U36.3 (3A)
/VRAM/B1D3: U25.15 (D3), U31.5 (A3), U36.13 (3B)
/VRAM/B1D4: U25.16 (D4), U31.6 (A4), U37.3 (3A)
/VRAM/B1D5: U25.17 (D5), U31.7 (A5), U37.13 (3B)
/VRAM/B1D6: U25.18 (D6), U31.8 (A6), U38.3 (3A)
/VRAM/B1D7: U25.19 (D7), U31.9 (A7), U38.13 (3B)
/VRAM/B1D8: U26.11 (D0), U32.2 (A0), U35.4 (2A)
/VRAM/B1D9: U26.12 (D1), U32.3 (A1), U35.12 (2B)
/VRAM/B1D10: U26.13 (D2), U32.4 (A2), U36.4 (2A)
/VRAM/B1D11: U26.15 (D3), U32.5 (A3), U36.12 (2B)
/VRAM/B1D12: U26.16 (D4), U32.6 (A4), U37.4 (2A)
/VRAM/B1D13: U26.17 (D5), U32.7 (A5), U37.12 (2B)
/VRAM/B1D14: U26.18 (D6), U32.8 (A6), U38.4 (2A)
/VRAM/B1D15: U26.19 (D7), U32.9 (A7), U38.12 (2B)
/VRAM/~B0RD: U21.12 (ZD), U27.22 (~OE), U28.22 (~OE)
/VRAM/~B0WRH: U24.7 (ZB), U28.27 (~WE), U34.19 (CE)
/VRAM/~B0WRL: U24.4 (ZA), U27.27 (~WE), U33.19 (CE)
/VRAM/~B1RD: U15.12 (ZD), U25.22 (~OE), U26.22 (~OE)
/VRAM/~B1WRH: U24.12 (ZD), U26.27 (~WE), U32.19 (CE)
/VRAM/~B1WRL: U24.9 (ZC), U25.27 (~WE), U31.19 (CE)
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

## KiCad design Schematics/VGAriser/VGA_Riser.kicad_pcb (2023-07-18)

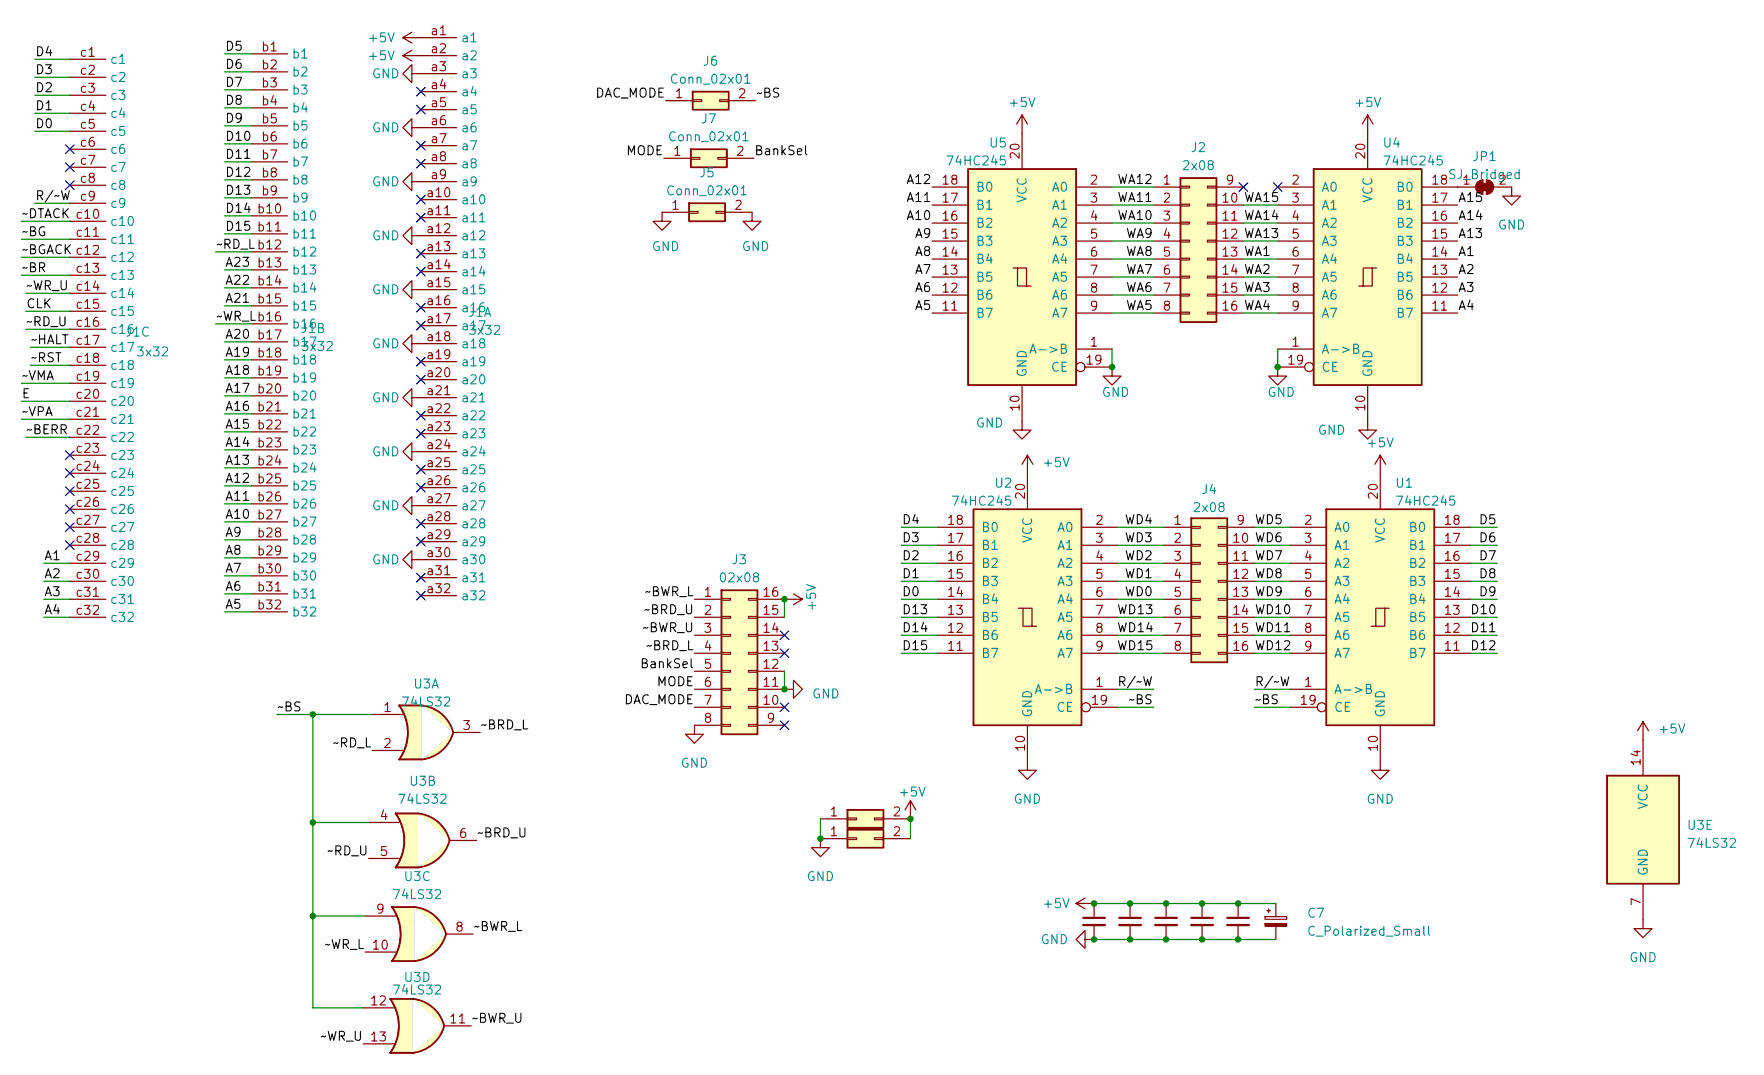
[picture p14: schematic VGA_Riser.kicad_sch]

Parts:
C1, C2, C3, C4, C5: 100nF; DIP-2_200_ELL
C7: C_Polarized_Small; CP_Radial_D5.0mm_P2.50mm
J1: 3x32; DIN41612_R_3x32_Male_Horizontal_THT
J2, J4: 2x08; 2x08 finger
J3: 02x08; 2x08 finger
J5, J6, J7: Conn_02x01; 2x01 finger
JP1: SJ_Bridged; SolderJumper-2_P1.3mm_Bridged_Pad1.0x1.5mm
U1, U2, U4, U5: 74HC245; DIP-20
U3: 74LS32; DIP-14

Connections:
/A1: J1.c29, U4.14 (B4)
/A2: J1.c30, U4.13 (B5)
/A3: J1.c31, U4.12 (B6)
/A4: J1.c32, U4.11 (B7)
/A5: J1.b32, U5.11 (B7)
/A6: J1.b31, U5.12 (B6)
/A7: J1.b30, U5.13 (B5)
/A8: J1.b29, U5.14 (B4)
/A9: J1.b28, U5.15 (B3)
/A10: J1.b27, U5.16 (B2)
/A11: J1.b26, U5.17 (B1)
/A12: J1.b25, U5.18 (B0)
/A13: J1.b24, U4.15 (B3)
/A14: J1.b23, U4.16 (B2)
/A15: J1.b22, U4.17 (B1)
/A16: J1.b21
/A17: J1.b20
/A18: J1.b19
/A19: J1.b18
/A20: J1.b17
/A21: J1.b15
/A22: J1.b14
/A23: J1.b13
/BankSel: J3.5, J7.2
/CLK: J1.c15
/D0: J1.c5, U2.14 (B4)
/D1: J1.c4, U2.15 (B3)
/D2: J1.c3, U2.16 (B2)
/D3: J1.c2, U2.17 (B1)
/D4: J1.c1, U2.18 (B0)
/D5: J1.b1, U1.18 (B0)
/D6: J1.b2, U1.17 (B1)
/D7: J1.b3, U1.16 (B2)
/D8: J1.b4, U1.15 (B3)
/D9: J1.b5, U1.14 (B4)
/D10: J1.b6, U1.13 (B5)
/D11: J1.b7, U1.12 (B6)
/D12: J1.b8, U1.11 (B7)
/D13: J1.b9, U2.13 (B5)
/D14: J1.b10, U2.12 (B6)
/D15: J1.b11, U2.11 (B7)
/E: J1.c20
/MODE: J3.6, J7.1
/R/~W: J1.c9, U1.1 (A->B), U2.1 (A->B)
/WA1: J2.13, U4.6 (A4)
/WA2: J2.14, U4.7 (A5)
/WA3: J2.15, U4.8 (A6)
/WA4: J2.16, U4.9 (A7)
/WA5: J2.8, U5.9 (A7)
/WA6: J2.7, U5.8 (A6)
/WA7: J2.6, U5.7 (A5)
/WA8: J2.5, U5.6 (A4)
/WA9: J2.4, U5.5 (A3)
/WA10: J2.3, U5.4 (A2)
/WA11: J2.2, U5.3 (A1)
/WA12: J2.1, U5.2 (A0)
/WA13: J2.12, U4.5 (A3)
/WA14: J2.11, U4.4 (A2)
/WA15: J2.10, U4.3 (A1)
/WD0: J4.5, U2.6 (A4)
/WD1: J4.4, U2.5 (A3)
/WD2: J4.3, U2.4 (A2)
/WD3: J4.2, U2.3 (A1)
/WD4: J4.1, U2.2 (A0)
/WD5: J4.9, U1.2 (A0)
/WD6: J4.10, U1.3 (A1)
/WD7: J4.11, U1.4 (A2)
/WD8: J4.12, U1.5 (A3)
/WD9: J4.13, U1.6 (A4)
/WD10: J4.14, U1.7 (A5)
/WD11: J4.15, U1.8 (A6)
/WD12: J4.16, U1.9 (A7)
/WD13: J4.6, U2.7 (A5)
/WD14: J4.7, U2.8 (A6)
/WD15: J4.8, U2.9 (A7)
/~BERR: J1.c22
/~BG: J1.c11
/~BGACK: J1.c12
/~BR: J1.c13
/~BRD_L: J3.4, U3.3
/~BRD_U: J3.2, U3.6
/~BWR_L: J3.1, U3.8
/~BWR_U: J3.3, U3.11
/~DTACK: J1.c10
/~HALT: J1.c17
/~RD_L: J1.b12, U3.2
/~RD_U: J1.c16, U3.5
/~RST: J1.c18
/~VMA: J1.c19
/~VPA: J1.c21
/~WR_L: J1.b16, U3.10
/~WR_U: J1.c14, U3.13
unnamed: JP1.1 (A), U4.18 (B0)

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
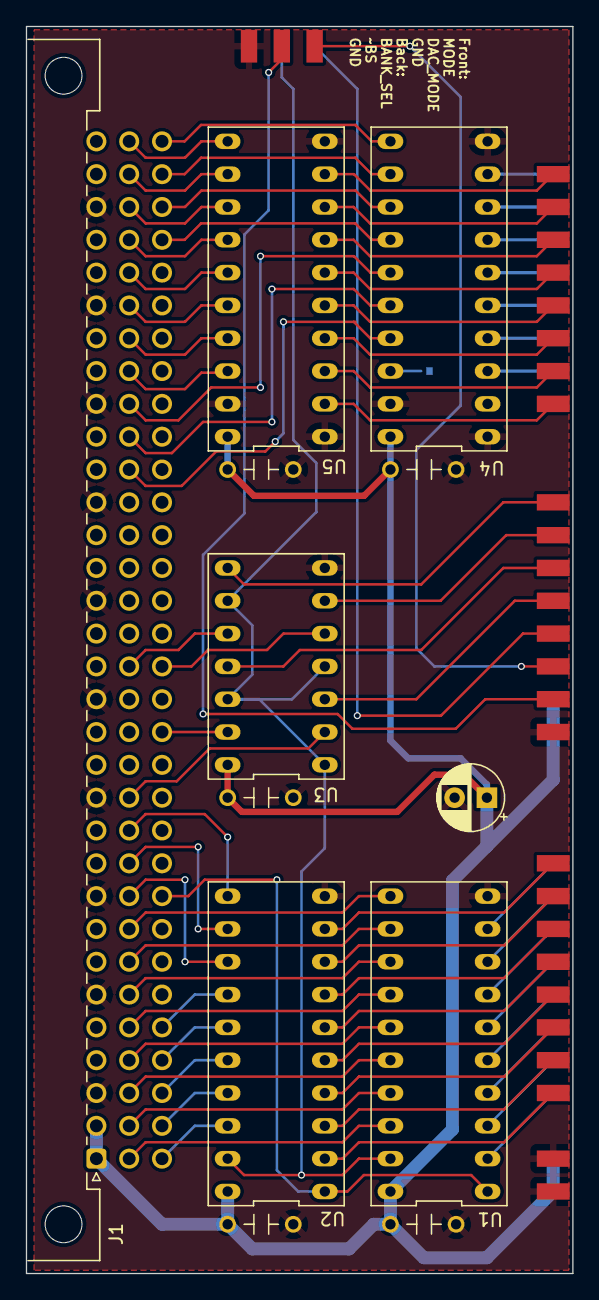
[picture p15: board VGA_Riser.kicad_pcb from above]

Board: 2 copper layers, 42.3 x 96.5 mm, 21 parts (1 on the bottom side), 78 nets.

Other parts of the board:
J8, J9: Conn_02x01; 2x01 finger

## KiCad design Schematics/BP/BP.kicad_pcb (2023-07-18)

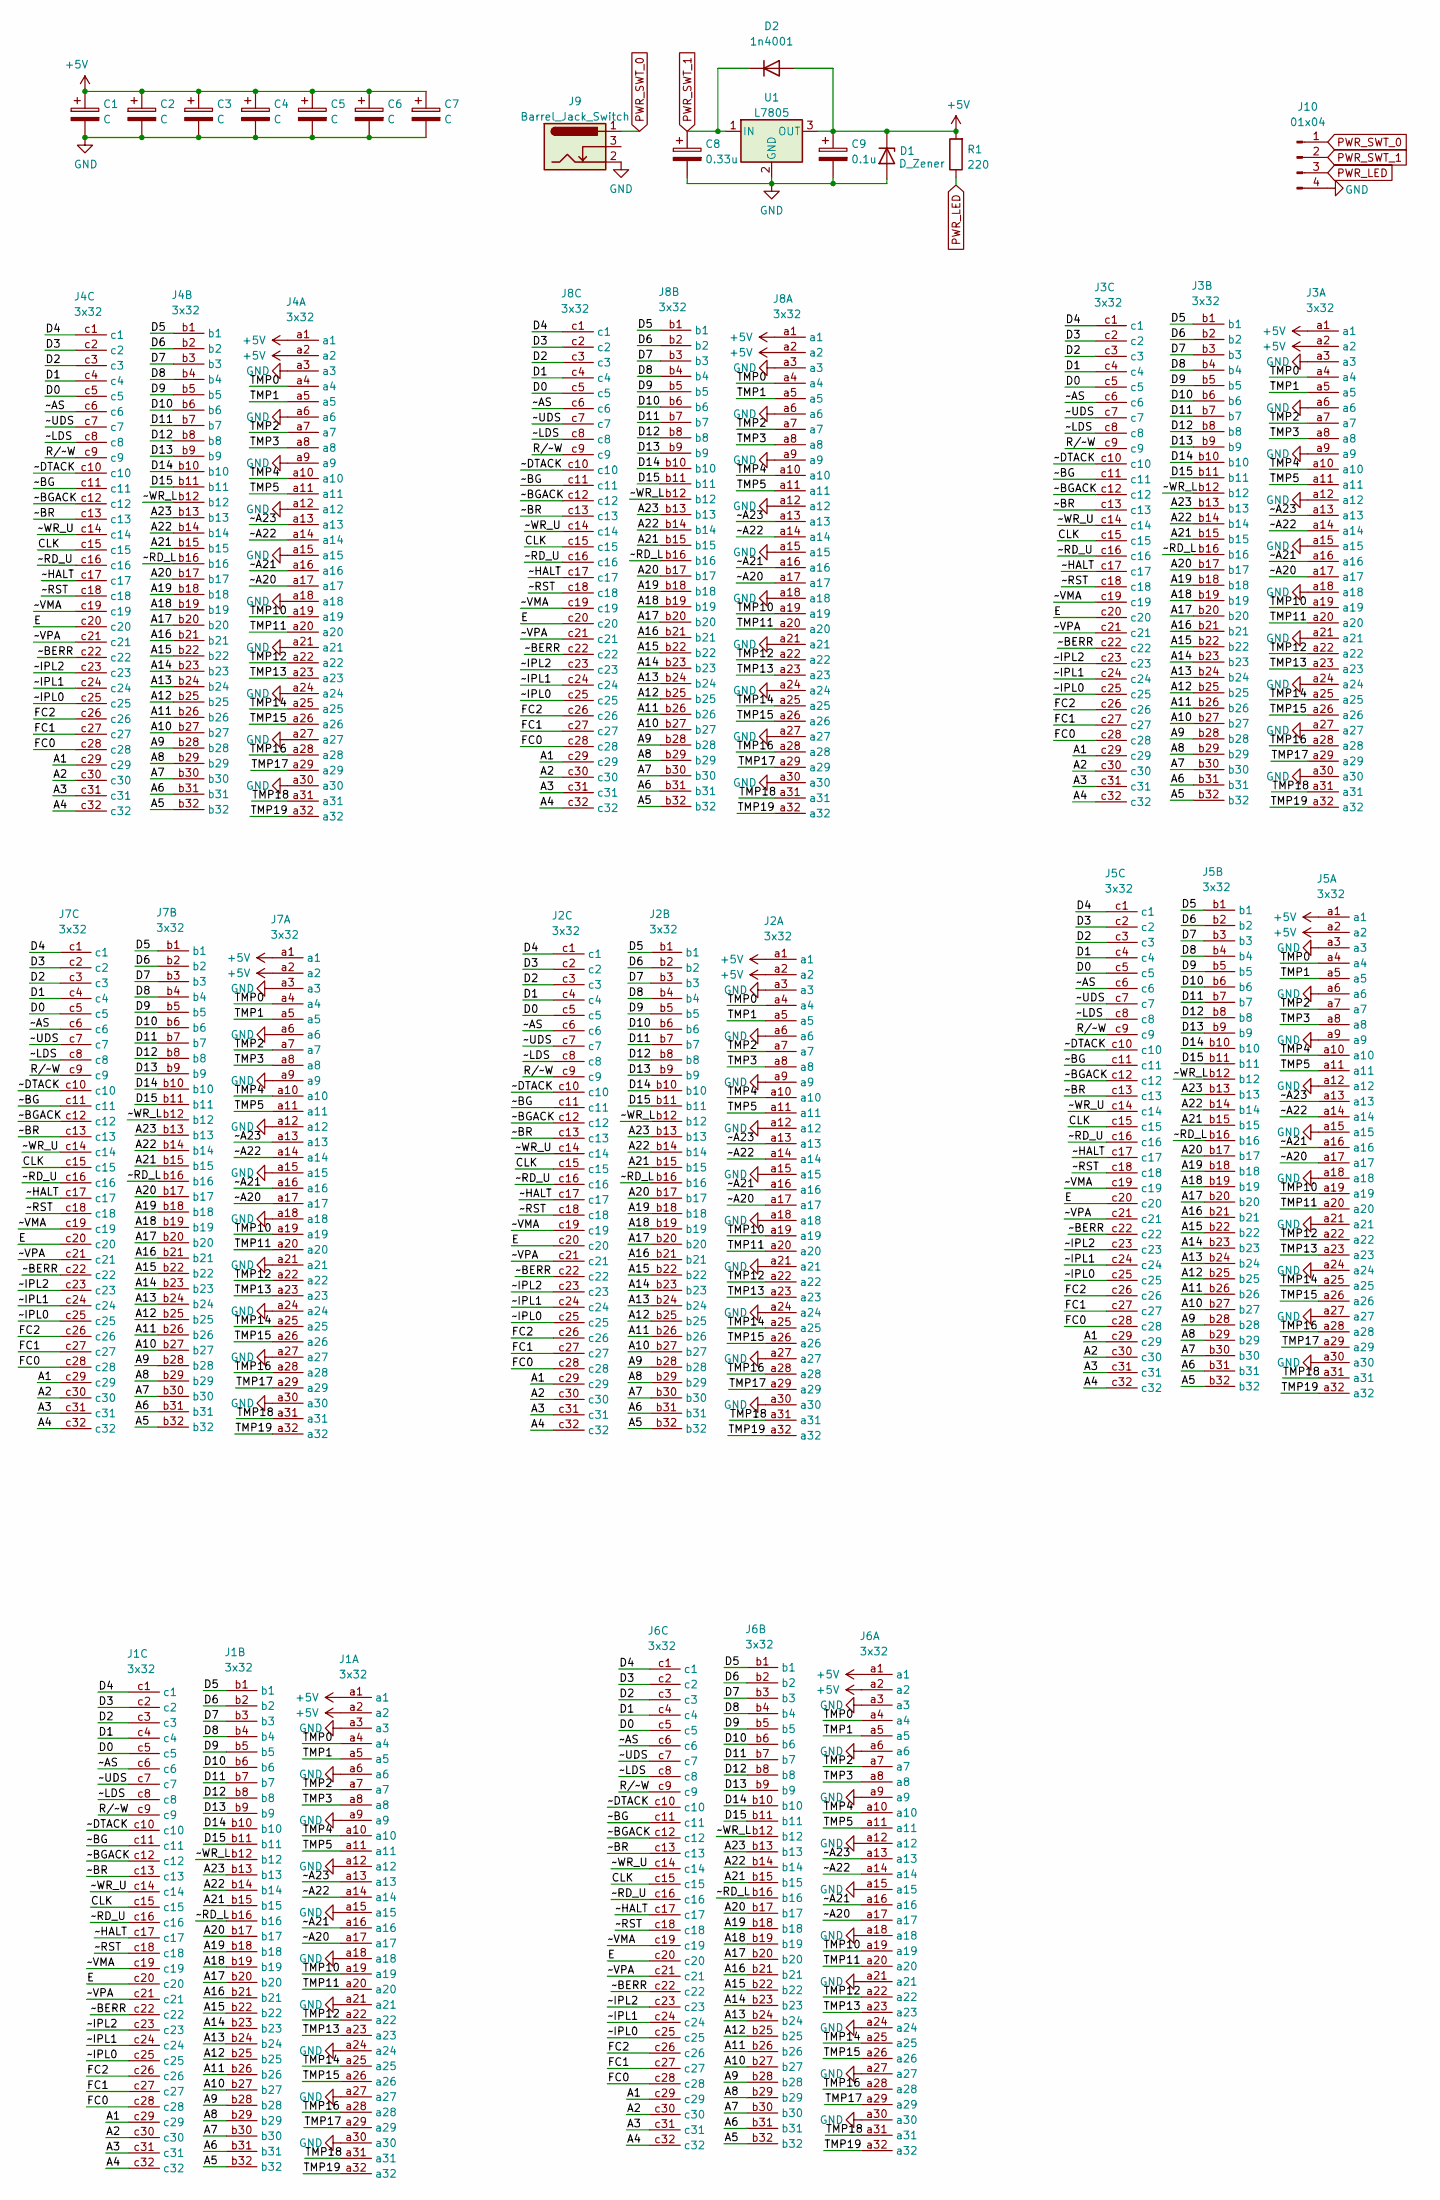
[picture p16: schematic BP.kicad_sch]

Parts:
C1, C2, C3, C4, C5, C6, C7: C; CP_Radial_D5.0mm_P2.50mm
C8: 0.33u; CP_Radial_D5.0mm_P2.50mm
C9: 0.1u; CP_Radial_D5.0mm_P2.50mm
D1: D_Zener; D_T-1_P5.08mm_Horizontal
D2: 1n4001; D_T-1_P5.08mm_Horizontal
J1, J2, J3, J4, J5, J6, J7, J8: 3x32; DIN41612_C_3x32_Female_Vertical_THT
J9: Barrel_Jack_Switch; BarrelJack_Horizontal
J10: 01x04
R1: 220; R_Axial_DIN0411_L9.9mm_D3.6mm_P5.08mm_Vertical
U1: L7805; TO-220-3_Horizontal_TabDown

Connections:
+5V: C1.1, C2.1, C3.1, C4.1, C5.1, C6.1, C7.1, C9.1, D1.1 (K), D2.2 (A), J1.a1, J1.a2, J2.a1, J2.a2, J3.a1, J3.a2, J4.a1, J4.a2, J5.a1, J5.a2, J6.a1, J6.a2, J7.a1, J7.a2, J8.a1, J8.a2, R1.2, U1.3 (OUT)
/A1: J1.c29, J2.c29, J3.c29, J4.c29, J5.c29, J6.c29, J7.c29, J8.c29
/A2: J1.c30, J2.c30, J3.c30, J4.c30, J5.c30, J6.c30, J7.c30, J8.c30
/A3: J1.c31, J2.c31, J3.c31, J4.c31, J5.c31, J6.c31, J7.c31, J8.c31
/A4: J1.c32, J2.c32, J3.c32, J4.c32, J5.c32, J6.c32, J7.c32, J8.c32
/A5: J1.b32, J2.b32, J3.b32, J4.b32, J5.b32, J6.b32, J7.b32, J8.b32
/A6: J1.b31, J2.b31, J3.b31, J4.b31, J5.b31, J6.b31, J7.b31, J8.b31
/A7: J1.b30, J2.b30, J3.b30, J4.b30, J5.b30, J6.b30, J7.b30, J8.b30
/A8: J1.b29, J2.b29, J3.b29, J4.b29, J5.b29, J6.b29, J7.b29, J8.b29
/A9: J1.b28, J2.b28, J3.b28, J4.b28, J5.b28, J6.b28, J7.b28, J8.b28
/A10: J1.b27, J2.b27, J3.b27, J4.b27, J5.b27, J6.b27, J7.b27, J8.b27
/A11: J1.b26, J2.b26, J3.b26, J4.b26, J5.b26, J6.b26, J7.b26, J8.b26
/A12: J1.b25, J2.b25, J3.b25, J4.b25, J5.b25, J6.b25, J7.b25, J8.b25
/A13: J1.b24, J2.b24, J3.b24, J4.b24, J5.b24, J6.b24, J7.b24, J8.b24
/A14: J1.b23, J2.b23, J3.b23, J4.b23, J5.b23, J6.b23, J7.b23, J8.b23
/A15: J1.b22, J2.b22, J3.b22, J4.b22, J5.b22, J6.b22, J7.b22, J8.b22
/A16: J1.b21, J2.b21, J3.b21, J4.b21, J5.b21, J6.b21, J7.b21, J8.b21
/A17: J1.b20, J2.b20, J3.b20, J4.b20, J5.b20, J6.b20, J7.b20, J8.b20
/A18: J1.b19, J2.b19, J3.b19, J4.b19, J5.b19, J6.b19, J7.b19, J8.b19
/A19: J1.b18, J2.b18, J3.b18, J4.b18, J5.b18, J6.b18, J7.b18, J8.b18
/A20: J1.b17, J2.b17, J3.b17, J4.b17, J5.b17, J6.b17, J7.b17, J8.b17
/A21: J1.b15, J2.b15, J3.b15, J4.b15, J5.b15, J6.b15, J7.b15, J8.b15
/A22: J1.b14, J2.b14, J3.b14, J4.b14, J5.b14, J6.b14, J7.b14, J8.b14
/A23: J1.b13, J2.b13, J3.b13, J4.b13, J5.b13, J6.b13, J7.b13, J8.b13
/CLK: J1.c15, J2.c15, J3.c15, J4.c15, J5.c15, J6.c15, J7.c15, J8.c15
/D0: J1.c5, J2.c5, J3.c5, J4.c5, J5.c5, J6.c5, J7.c5, J8.c5
/D1: J1.c4, J2.c4, J3.c4, J4.c4, J5.c4, J6.c4, J7.c4, J8.c4
/D2: J1.c3, J2.c3, J3.c3, J4.c3, J5.c3, J6.c3, J7.c3, J8.c3
/D3: J1.c2, J2.c2, J3.c2, J4.c2, J5.c2, J6.c2, J7.c2, J8.c2
/D4: J1.c1, J2.c1, J3.c1, J4.c1, J5.c1, J6.c1, J7.c1, J8.c1
/D5: J1.b1, J2.b1, J3.b1, J4.b1, J5.b1, J6.b1, J7.b1, J8.b1
/D6: J1.b2, J2.b2, J3.b2, J4.b2, J5.b2, J6.b2, J7.b2, J8.b2
/D7: J1.b3, J2.b3, J3.b3, J4.b3, J5.b3, J6.b3, J7.b3, J8.b3
/D8: J1.b4, J2.b4, J3.b4, J4.b4, J5.b4, J6.b4, J7.b4, J8.b4
/D9: J1.b5, J2.b5, J3.b5, J4.b5, J5.b5, J6.b5, J7.b5, J8.b5
/D10: J1.b6, J2.b6, J3.b6, J4.b6, J5.b6, J6.b6, J7.b6, J8.b6
/D11: J1.b7, J2.b7, J3.b7, J4.b7, J5.b7, J6.b7, J7.b7, J8.b7
/D12: J1.b8, J2.b8, J3.b8, J4.b8, J5.b8, J6.b8, J7.b8, J8.b8
/D13: J1.b9, J2.b9, J3.b9, J4.b9, J5.b9, J6.b9, J7.b9, J8.b9
/D14: J1.b10, J2.b10, J3.b10, J4.b10, J5.b10, J6.b10, J7.b10, J8.b10
/D15: J1.b11, J2.b11, J3.b11, J4.b11, J5.b11, J6.b11, J7.b11, J8.b11
/E: J1.c20, J2.c20, J3.c20, J4.c20, J5.c20, J6.c20, J7.c20, J8.c20
/FC0: J1.c28, J2.c28, J3.c28, J4.c28, J5.c28, J6.c28, J7.c28, J8.c28
/FC1: J1.c27, J2.c27, J3.c27, J4.c27, J5.c27, J6.c27, J7.c27, J8.c27
/FC2: J1.c26, J2.c26, J3.c26, J4.c26, J5.c26, J6.c26, J7.c26, J8.c26
/R/~W: J1.c9, J2.c9, J3.c9, J4.c9, J5.c9, J6.c9, J7.c9, J8.c9
/TMP0: J1.a4, J2.a4, J3.a4, J4.a4, J5.a4, J6.a4, J7.a4, J8.a4
/TMP1: J1.a5, J2.a5, J3.a5, J4.a5, J5.a5, J6.a5, J7.a5, J8.a5
/TMP2: J1.a7, J2.a7, J3.a7, J4.a7, J5.a7, J6.a7, J7.a7, J8.a7
/TMP3: J1.a8, J2.a8, J3.a8, J4.a8, J5.a8, J6.a8, J7.a8, J8.a8
/TMP4: J1.a10, J2.a10, J3.a10, J4.a10, J5.a10, J6.a10, J7.a10, J8.a10
/TMP5: J1.a11, J2.a11, J3.a11, J4.a11, J5.a11, J6.a11, J7.a11, J8.a11
/TMP10: J1.a19, J2.a19, J3.a19, J4.a19, J5.a19, J6.a19, J7.a19, J8.a19
/TMP11: J1.a20, J2.a20, J3.a20, J4.a20, J5.a20, J6.a20, J7.a20, J8.a20
/TMP12: J1.a22, J2.a22, J3.a22, J4.a22, J5.a22, J6.a22, J7.a22, J8.a22
/TMP13: J1.a23, J2.a23, J3.a23, J4.a23, J5.a23, J6.a23, J7.a23, J8.a23
/TMP14: J1.a25, J2.a25, J3.a25, J4.a25, J5.a25, J6.a25, J7.a25, J8.a25
/TMP15: J1.a26, J2.a26, J3.a26, J4.a26, J5.a26, J6.a26, J7.a26, J8.a26
/TMP16: J1.a28, J2.a28, J3.a28, J4.a28, J5.a28, J6.a28, J7.a28, J8.a28
/TMP17: J1.a29, J2.a29, J3.a29, J4.a29, J5.a29, J6.a29, J7.a29, J8.a29
/TMP18: J1.a31, J2.a31, J3.a31, J4.a31, J5.a31, J6.a31, J7.a31, J8.a31
/TMP19: J1.a32, J2.a32, J3.a32, J4.a32, J5.a32, J6.a32, J7.a32, J8.a32
/~A20: J1.a17, J2.a17, J3.a17, J4.a17, J5.a17, J6.a17, J7.a17, J8.a17
/~A21: J1.a16, J2.a16, J3.a16, J4.a16, J5.a16, J6.a16, J7.a16, J8.a16
/~A22: J1.a14, J2.a14, J3.a14, J4.a14, J5.a14, J6.a14, J7.a14, J8.a14
/~A23: J1.a13, J2.a13, J3.a13, J4.a13, J5.a13, J6.a13, J7.a13, J8.a13
/~AS: J1.c6, J2.c6, J3.c6, J4.c6, J5.c6, J6.c6, J7.c6, J8.c6
/~BERR: J1.c22, J2.c22, J3.c22, J4.c22, J5.c22, J6.c22, J7.c22, J8.c22
/~BG: J1.c11, J2.c11, J3.c11, J4.c11, J5.c11, J6.c11, J7.c11, J8.c11
/~BGACK: J1.c12, J2.c12, J3.c12, J4.c12, J5.c12, J6.c12, J7.c12, J8.c12
/~BR: J1.c13, J2.c13, J3.c13, J4.c13, J5.c13, J6.c13, J7.c13, J8.c13
/~DTACK: J1.c10, J2.c10, J3.c10, J4.c10, J5.c10, J6.c10, J7.c10, J8.c10
/~HALT: J1.c17, J2.c17, J3.c17, J4.c17, J5.c17, J6.c17, J7.c17, J8.c17
/~IPL0: J1.c25, J2.c25, J3.c25, J4.c25, J5.c25, J6.c25, J7.c25, J8.c25
/~IPL1: J1.c24, J2.c24, J3.c24, J4.c24, J5.c24, J6.c24, J7.c24, J8.c24
/~IPL2: J1.c23, J2.c23, J3.c23, J4.c23, J5.c23, J6.c23, J7.c23, J8.c23
/~LDS: J1.c8, J2.c8, J3.c8, J4.c8, J5.c8, J6.c8, J7.c8, J8.c8
/~RD_L: J1.b16, J2.b16, J3.b16, J4.b16, J5.b16, J6.b16, J7.b16, J8.b16
/~RD_U: J1.c16, J2.c16, J3.c16, J4.c16, J5.c16, J6.c16, J7.c16, J8.c16
/~RST: J1.c18, J2.c18, J3.c18, J4.c18, J5.c18, J6.c18, J7.c18, J8.c18, J10.5
/~UDS: J1.c7, J2.c7, J3.c7, J4.c7, J5.c7, J6.c7, J7.c7, J8.c7
/~VMA: J1.c19, J2.c19, J3.c19, J4.c19, J5.c19, J6.c19, J7.c19, J8.c19
/~VPA: J1.c21, J2.c21, J3.c21, J4.c21, J5.c21, J6.c21, J7.c21, J8.c21
/~WR_L: J1.b12, J2.b12, J3.b12, J4.b12, J5.b12, J6.b12, J7.b12, J8.b12
/~WR_U: J1.c14, J2.c14, J3.c14, J4.c14, J5.c14, J6.c14, J7.c14, J8.c14
GND: C1.2, C2.2, C3.2, C4.2, C5.2, C6.2, C7.2, C8.2, C9.2, D1.2 (A), J1.a3, J1.a6, J1.a9, J1.a12, J1.a15, J1.a18, J1.a21, J1.a24, J1.a27, J1.a30, J2.a3, J2.a6, J2.a9, J2.a12, J2.a15, J2.a18, J2.a21, J2.a24, J2.a27, J2.a30, J3.a3, J3.a6, J3.a9, J3.a12, J3.a15, J3.a18, J3.a21, J3.a24, J3.a27, J3.a30, J4.a3, J4.a6, J4.a9, J4.a12, J4.a15, J4.a18, J4.a21, J4.a24, J4.a27, J4.a30, J5.a3, J5.a6, J5.a9, J5.a12, J5.a15, J5.a18, J5.a21, J5.a24, J5.a27, J5.a30, J6.a3, J6.a6, J6.a9, J6.a12, J6.a15, J6.a18, J6.a21, J6.a24, J6.a27, J6.a30, J7.a3, J7.a6, J7.a9, J7.a12, J7.a15, J7.a18, J7.a21, J7.a24, J7.a27, J7.a30, J8.a3, J8.a6, J8.a9, J8.a12, J8.a15, J8.a18, J8.a21, J8.a24, J8.a27, J8.a30, J9.2, J10.4, U1.2 (GND)
PWR_LED: J10.3, R1.1
PWR_SWT_0: J9.1, J10.1
PWR_SWT_1: C8.1, D2.1 (K), J10.2, U1.1 (IN)

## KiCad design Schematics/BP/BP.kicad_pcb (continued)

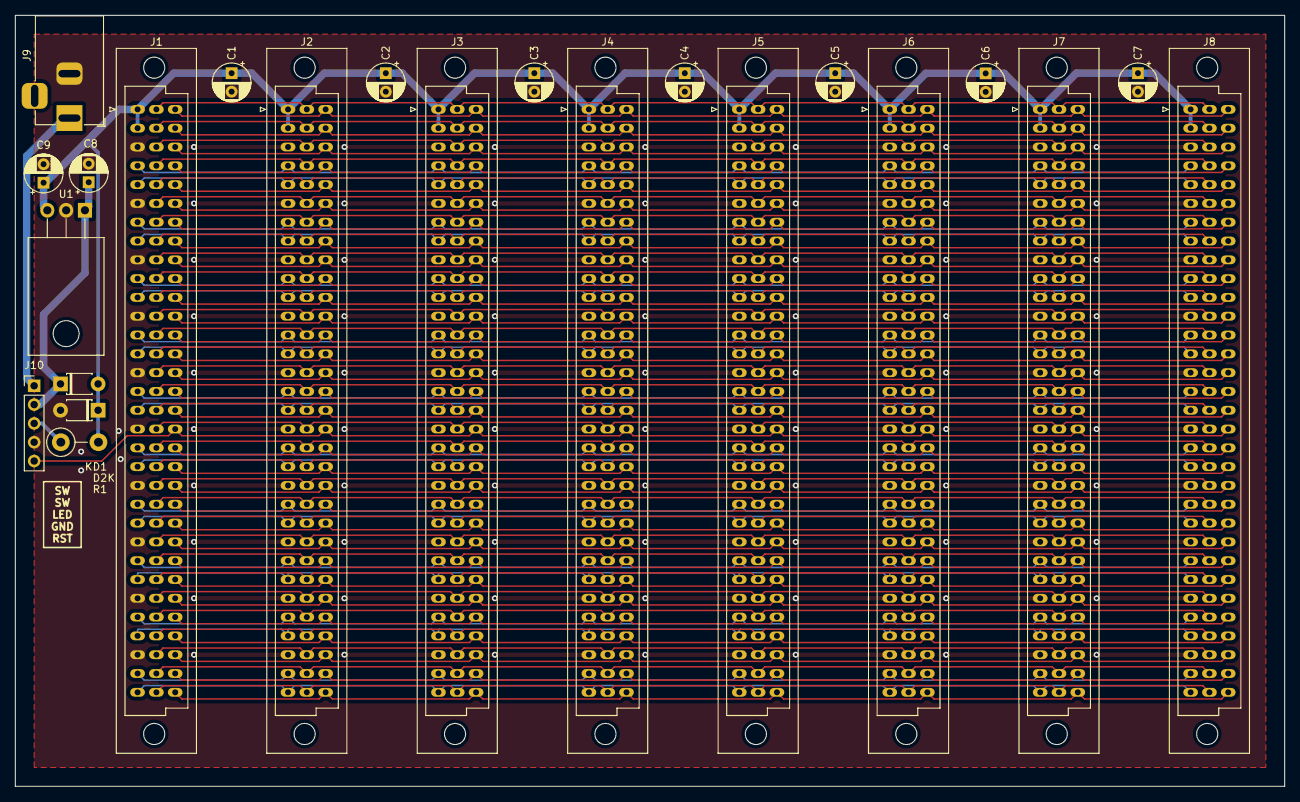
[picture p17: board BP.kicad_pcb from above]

Board: 2 copper layers, 171.4 x 104.1 mm, 23 parts (0 on the bottom side), 89 nets.

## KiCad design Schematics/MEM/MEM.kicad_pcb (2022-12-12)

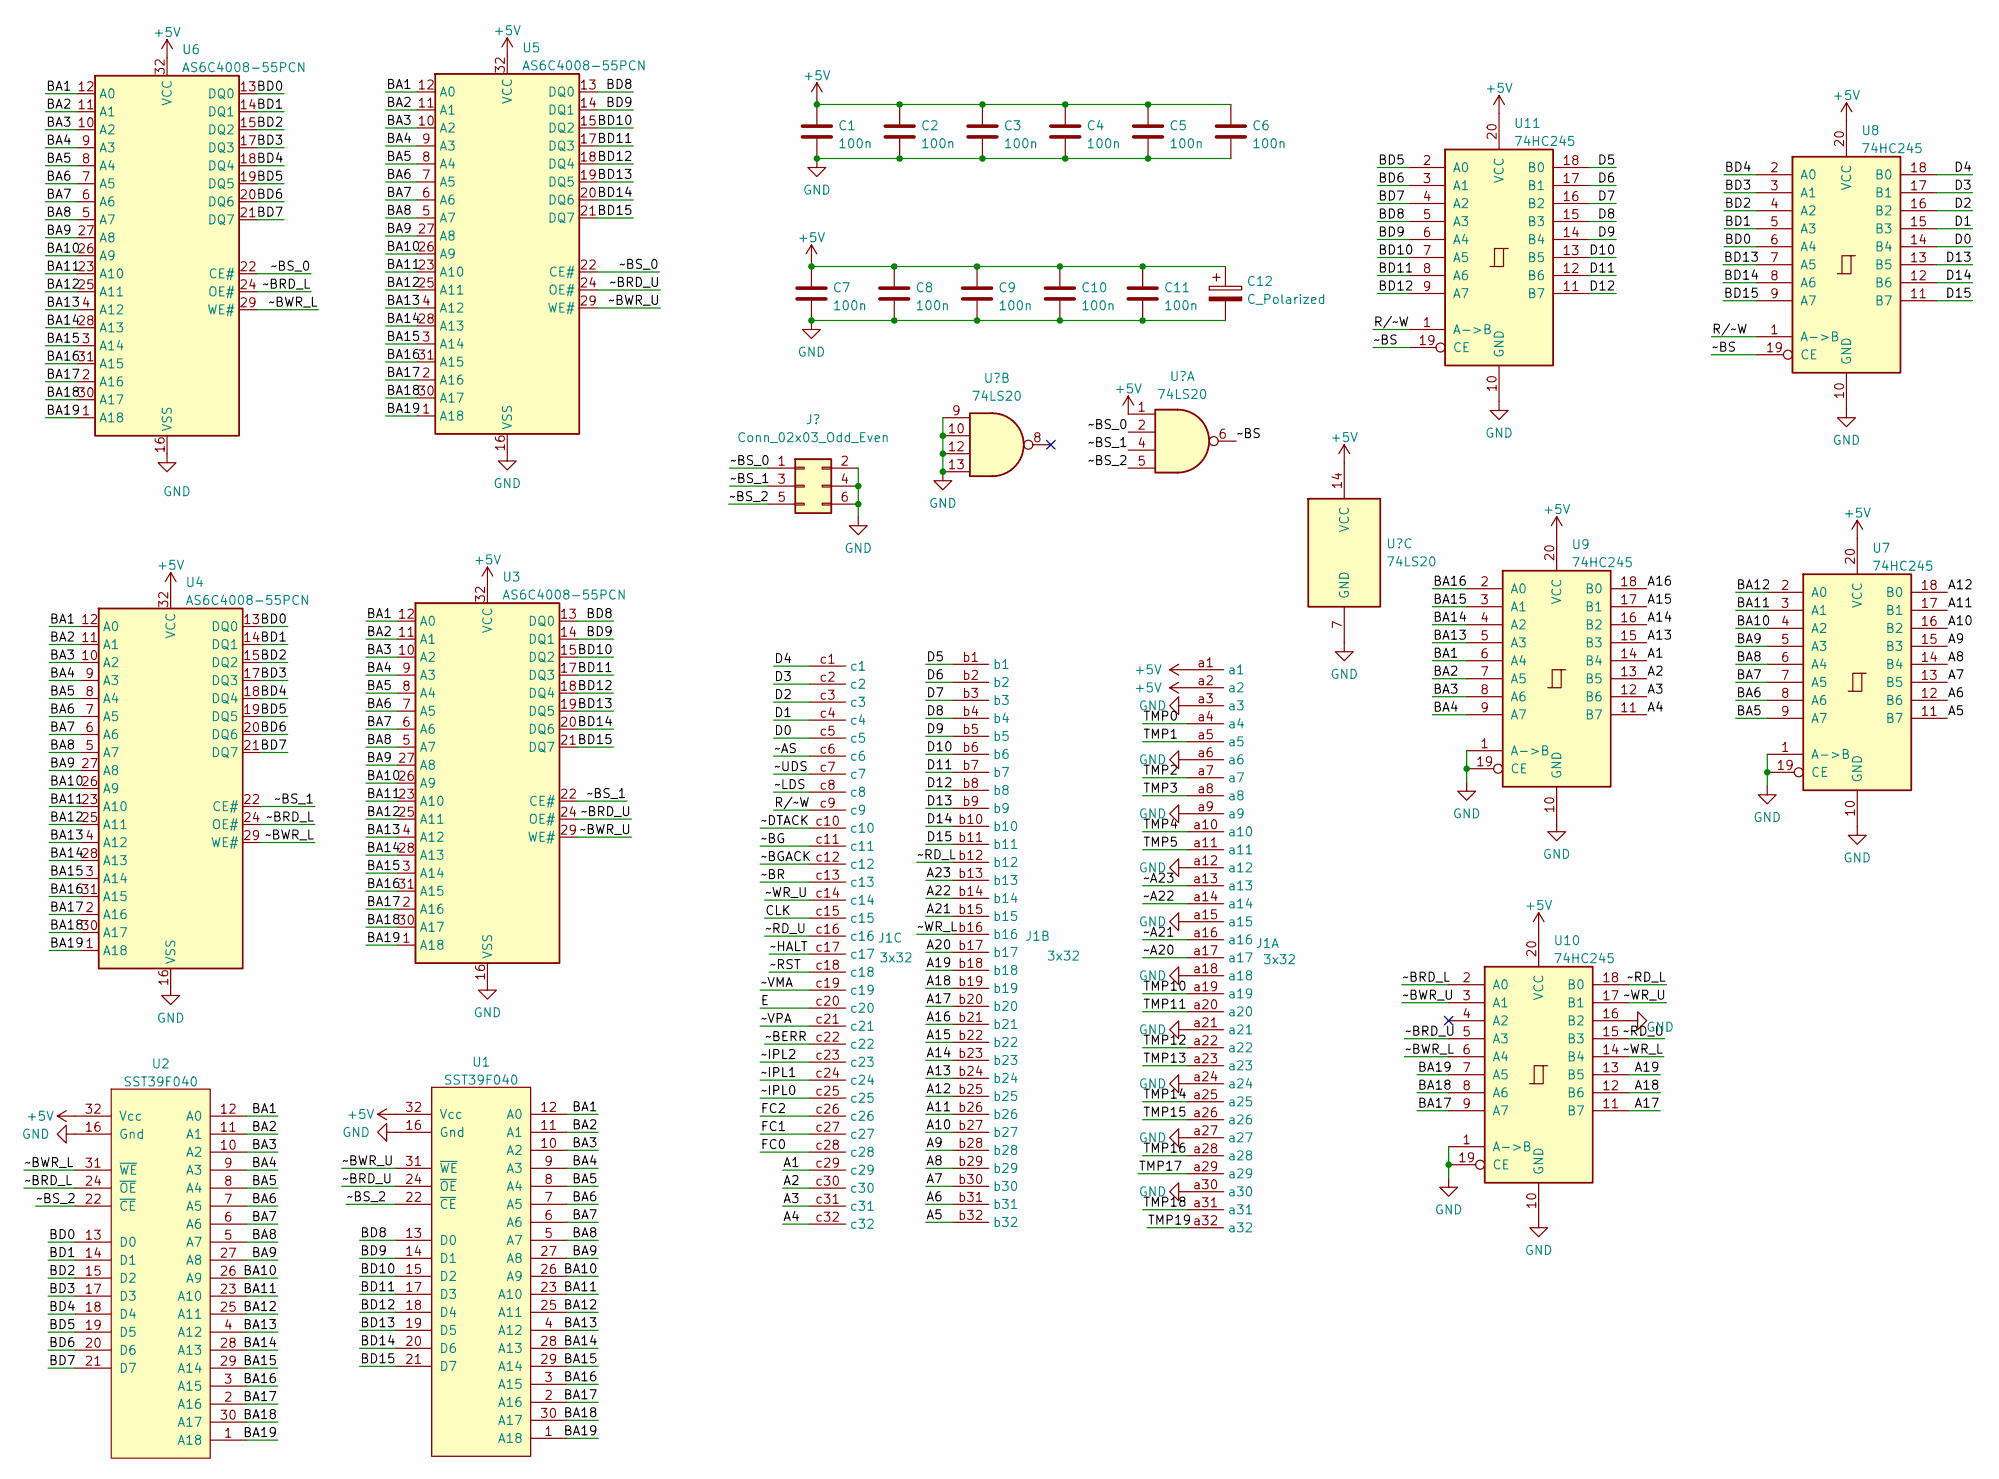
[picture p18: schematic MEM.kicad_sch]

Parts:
C1, C2, C3, C4, C5, C6, C7, C8, C9, C10, C11: 100n; DIP-2_200_ELL
C12: C_Polarized; CP_Radial_D4.0mm_P1.50mm
J1: 3x32; DIN41612_R_3x32_Male_Horizontal_THT
U1, U2: SST39F040; DIP-32_600_ELL
U3, U4, U5, U6: AS6C4008-55PCN; DIP-32_600_ELL
U7, U8, U9, U10, U11: 74HC245; DIP-20

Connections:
+5V: C1.1, C2.1, C3.1, C4.1, C5.1, C6.1, C7.1, C8.1, C9.1, C10.1, C11.1, C12.1, J1.a1, J1.a2, U1.32 (Vcc), U2.32 (Vcc), U3.32 (VCC), U4.32 (VCC), U5.32 (VCC), U6.32 (VCC), U7.20 (VCC), U8.20 (VCC), U9.20 (VCC), U10.20 (VCC), U11.20 (VCC)
/A1: J1.c29, U9.14 (B4)
/A2: J1.c30, U9.13 (B5)
/A3: J1.c31, U9.12 (B6)
/A4: J1.c32, U9.11 (B7)
/A5: J1.b32, U7.11 (B7)
/A6: J1.b31, U7.12 (B6)
/A7: J1.b30, U7.13 (B5)
/A8: J1.b29, U7.14 (B4)
/A9: J1.b28, U7.15 (B3)
/A10: J1.b27, U7.16 (B2)
/A11: J1.b26, U7.17 (B1)
/A12: J1.b25, U7.18 (B0)
/A13: J1.b24, U9.15 (B3)
/A14: J1.b23, U9.16 (B2)
/A15: J1.b22, U9.17 (B1)
/A16: J1.b21, U9.18 (B0)
/A17: J1.b20, U10.11 (B7)
/A18: J1.b19, U10.12 (B6)
/A19: J1.b18, U10.13 (B5)
/A20: J1.b17
/A21: J1.b15
/A22: J1.b14
/A23: J1.b13
/BA1: U1.12 (A0), U2.12 (A0), U3.12 (A0), U4.12 (A0), U5.12 (A0), U6.12 (A0), U9.6 (A4)
/BA2: U1.11 (A1), U2.11 (A1), U3.11 (A1), U4.11 (A1), U5.11 (A1), U6.11 (A1), U9.7 (A5)
/BA3: U1.10 (A2), U2.10 (A2), U3.10 (A2), U4.10 (A2), U5.10 (A2), U6.10 (A2), U9.8 (A6)
/BA4: U1.9 (A3), U2.9 (A3), U3.9 (A3), U4.9 (A3), U5.9 (A3), U6.9 (A3), U9.9 (A7)
/BA5: U1.8 (A4), U2.8 (A4), U3.8 (A4), U4.8 (A4), U5.8 (A4), U6.8 (A4), U7.9 (A7)
/BA6: U1.7 (A5), U2.7 (A5), U3.7 (A5), U4.7 (A5), U5.7 (A5), U6.7 (A5), U7.8 (A6)
/BA7: U1.6 (A6), U2.6 (A6), U3.6 (A6), U4.6 (A6), U5.6 (A6), U6.6 (A6), U7.7 (A5)
/BA8: U1.5 (A7), U2.5 (A7), U3.5 (A7), U4.5 (A7), U5.5 (A7), U6.5 (A7), U7.6 (A4)
/BA9: U1.27 (A8), U2.27 (A8), U3.27 (A8), U4.27 (A8), U5.27 (A8), U6.27 (A8), U7.5 (A3)
/BA10: U1.26 (A9), U2.26 (A9), U3.26 (A9), U4.26 (A9), U5.26 (A9), U6.26 (A9), U7.4 (A2)
/BA11: U1.23 (A10), U2.23 (A10), U3.23 (A10), U4.23 (A10), U5.23 (A10), U6.23 (A10), U7.3 (A1)
/BA12: U1.25 (A11), U2.25 (A11), U3.25 (A11), U4.25 (A11), U5.25 (A11), U6.25 (A11), U7.2 (A0)
/BA13: U1.4 (A12), U2.4 (A12), U3.4 (A12), U4.4 (A12), U5.4 (A12), U6.4 (A12), U9.5 (A3)
/BA14: U1.28 (A13), U2.28 (A13), U3.28 (A13), U4.28 (A13), U5.28 (A13), U6.28 (A13), U9.4 (A2)
/BA15: U1.29 (A14), U2.29 (A14), U3.3 (A14), U4.3 (A14), U5.3 (A14), U6.3 (A14), U9.3 (A1)
/BA16: U1.3 (A15), U2.3 (A15), U3.31 (A15), U4.31 (A15), U5.31 (A15), U6.31 (A15), U9.2 (A0)
/BA17: U1.2 (A16), U2.2 (A16), U3.2 (A16), U4.2 (A16), U5.2 (A16), U6.2 (A16), U10.9 (A7)
/BA18: U1.30 (A17), U2.30 (A17), U3.30 (A17), U4.30 (A17), U5.30 (A17), U6.30 (A17), U10.8 (A6)
/BA19: U1.1 (A18), U2.1 (A18), U3.1 (A18), U4.1 (A18), U5.1 (A18), U6.1 (A18), U10.7 (A5)
/BD0: U2.13 (D0), U4.13 (DQ0), U6.13 (DQ0), U8.6 (A4)
/BD1: U2.14 (D1), U4.14 (DQ1), U6.14 (DQ1), U8.5 (A3)
/BD2: U2.15 (D2), U4.15 (DQ2), U6.15 (DQ2), U8.4 (A2)
/BD3: U2.17 (D3), U4.17 (DQ3), U6.17 (DQ3), U8.3 (A1)
/BD4: U2.18 (D4), U4.18 (DQ4), U6.18 (DQ4), U8.2 (A0)
/BD5: U2.19 (D5), U4.19 (DQ5), U6.19 (DQ5), U11.2 (A0)
/BD6: U2.20 (D6), U4.20 (DQ6), U6.20 (DQ6), U11.3 (A1)
/BD7: U2.21 (D7), U4.21 (DQ7), U6.21 (DQ7), U11.4 (A2)
/BD8: U1.13 (D0), U3.13 (DQ0), U5.13 (DQ0), U11.5 (A3)
/BD9: U1.14 (D1), U3.14 (DQ1), U5.14 (DQ1), U11.6 (A4)
/BD10: U1.15 (D2), U3.15 (DQ2), U5.15 (DQ2), U11.7 (A5)
/BD11: U1.17 (D3), U3.17 (DQ3), U5.17 (DQ3), U11.8 (A6)
/BD12: U1.18 (D4), U3.18 (DQ4), U5.18 (DQ4), U11.9 (A7)
/BD13: U1.19 (D5), U3.19 (DQ5), U5.19 (DQ5), U8.7 (A5)
/BD14: U1.20 (D6), U3.20 (DQ6), U5.20 (DQ6), U8.8 (A6)
/BD15: U1.21 (D7), U3.21 (DQ7), U5.21 (DQ7), U8.9 (A7)
/CLK: J1.c15
/D0: J1.c5, U8.14 (B4)
/D1: J1.c4, U8.15 (B3)
/D2: J1.c3, U8.16 (B2)
/D3: J1.c2, U8.17 (B1)
/D4: J1.c1, U8.18 (B0)
/D5: J1.b1, U11.18 (B0)
/D6: J1.b2, U11.17 (B1)
/D7: J1.b3, U11.16 (B2)
/D8: J1.b4, U11.15 (B3)
/D9: J1.b5, U11.14 (B4)
/D10: J1.b6, U11.13 (B5)
/D11: J1.b7, U11.12 (B6)
/D12: J1.b8, U11.11 (B7)
/D13: J1.b9, U8.13 (B5)
/D14: J1.b10, U8.12 (B6)
/D15: J1.b11, U8.11 (B7)
/E: J1.c20
/FC0: J1.c28
/FC1: J1.c27
/FC2: J1.c26
/R/~W: J1.c9, U8.1 (A->B), U11.1 (A->B)
/TMP0: J1.a4
/TMP1: J1.a5
/TMP2: J1.a7
/TMP3: J1.a8
/TMP4: J1.a10
/TMP5: J1.a11
/TMP10: J1.a19
/TMP11: J1.a20
/TMP12: J1.a22
/TMP13: J1.a23
/TMP14: J1.a25
/TMP15: J1.a26
/TMP16: J1.a28
/TMP17: J1.a29
/TMP18: J1.a31
/TMP19: J1.a32
/~A20: J1.a17
/~A21: J1.a16
/~A22: J1.a14
/~A23: J1.a13
/~AS: J1.c6
/~BERR: J1.c22
/~BG: J1.c11
/~BGACK: J1.c12
/~BR: J1.c13
/~BRD_L: U2.24 (~OE), U4.24 (OE#), U6.24 (OE#), U10.2 (A0)
/~BRD_U: U1.24 (~OE), U3.24 (OE#), U5.24 (OE#), U10.5 (A3)
/~BS: U8.19 (CE), U11.19 (CE)
/~BS_0: U5.22 (CE#), U6.22 (CE#)
/~BS_1: U3.22 (CE#), U4.22 (CE#)
/~BS_2: U1.22 (~CE), U2.22 (~CE)
/~BWR_L: U2.31 (~WE), U4.29 (WE#), U6.29 (WE#), U10.6 (A4)
/~BWR_U: U1.31 (~WE), U3.29 (WE#), U5.29 (WE#), U10.3 (A1)
/~DTACK: J1.c10
/~HALT: J1.c17
/~IPL0: J1.c25
/~IPL1: J1.c24
/~IPL2: J1.c23
/~LDS: J1.c8
/~RD_L: J1.b12, U10.18 (B0)
/~RD_U: J1.c16, U10.15 (B3)
/~RST: J1.c18
/~UDS: J1.c7
/~VMA: J1.c19
/~VPA: J1.c21
/~WR_L: J1.b16, U10.14 (B4)
/~WR_U: J1.c14, U10.17 (B1)
GND: C1.2, C2.2, C3.2, C4.2, C5.2, C6.2, C7.2, C8.2, C9.2, C10.2, C11.2, C12.2, J1.a3, J1.a6, J1.a9, J1.a12, J1.a15, J1.a18, J1.a21, J1.a24, J1.a27, J1.a30, U1.16 (Gnd), U2.16 (Gnd), U3.16 (VSS), U4.16 (VSS), U5.16 (VSS), U6.16 (VSS), U7.1 (A->B), U7.10 (GND), U7.19 (CE), U8.10 (GND), U9.1 (A->B), U9.10 (GND), U9.19 (CE), U10.1 (A->B), U10.10 (GND), U10.16 (B2), U10.19 (CE), U11.10 (GND)

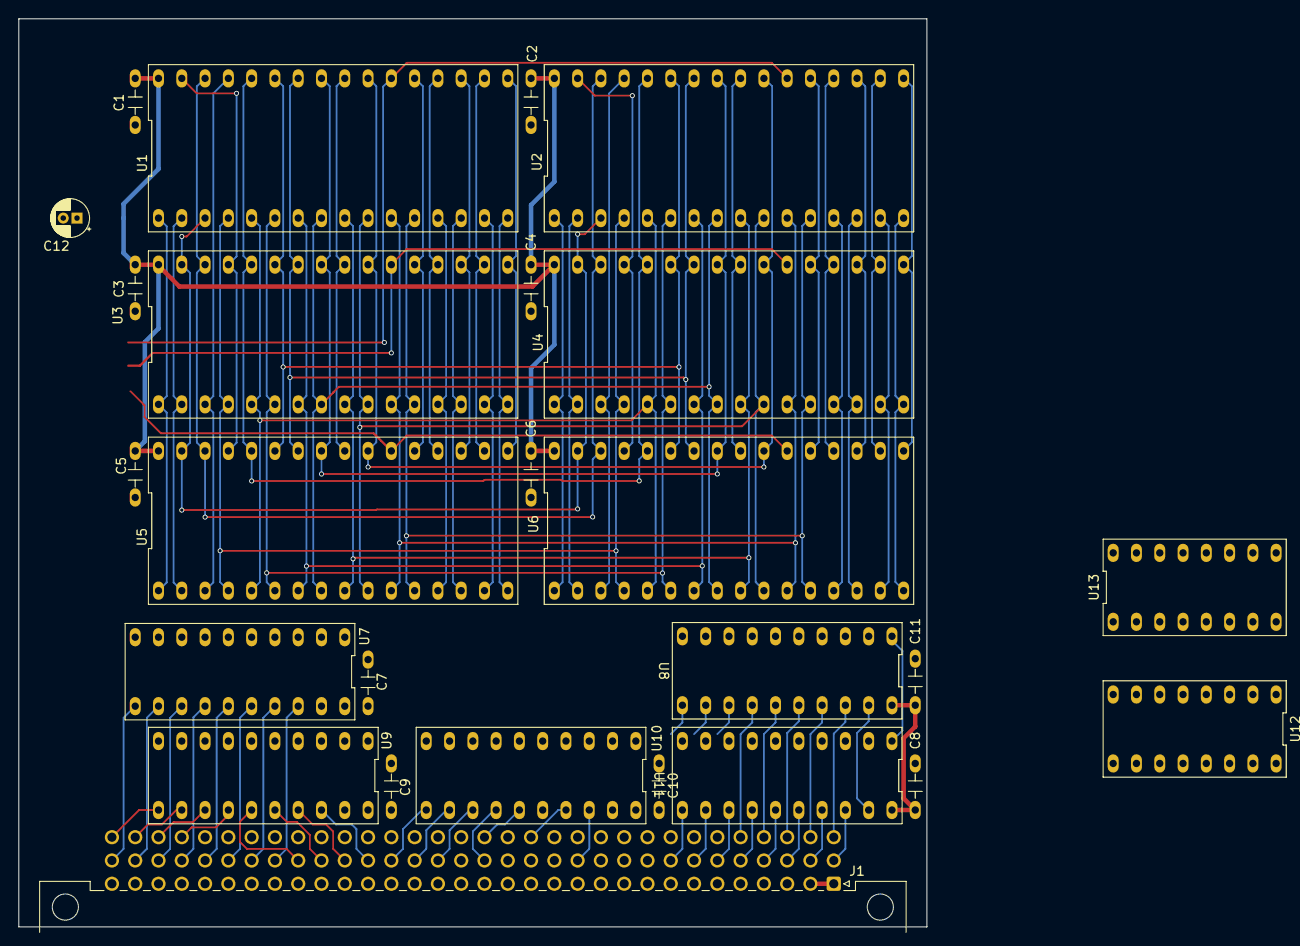
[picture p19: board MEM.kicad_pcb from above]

Board: 4 copper layers, 99.1 x 99.1 mm, 26 parts (0 on the bottom side), 85 nets.

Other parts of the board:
U12: 74LS85; DIP-16
U13: 74LS138; DIP-16

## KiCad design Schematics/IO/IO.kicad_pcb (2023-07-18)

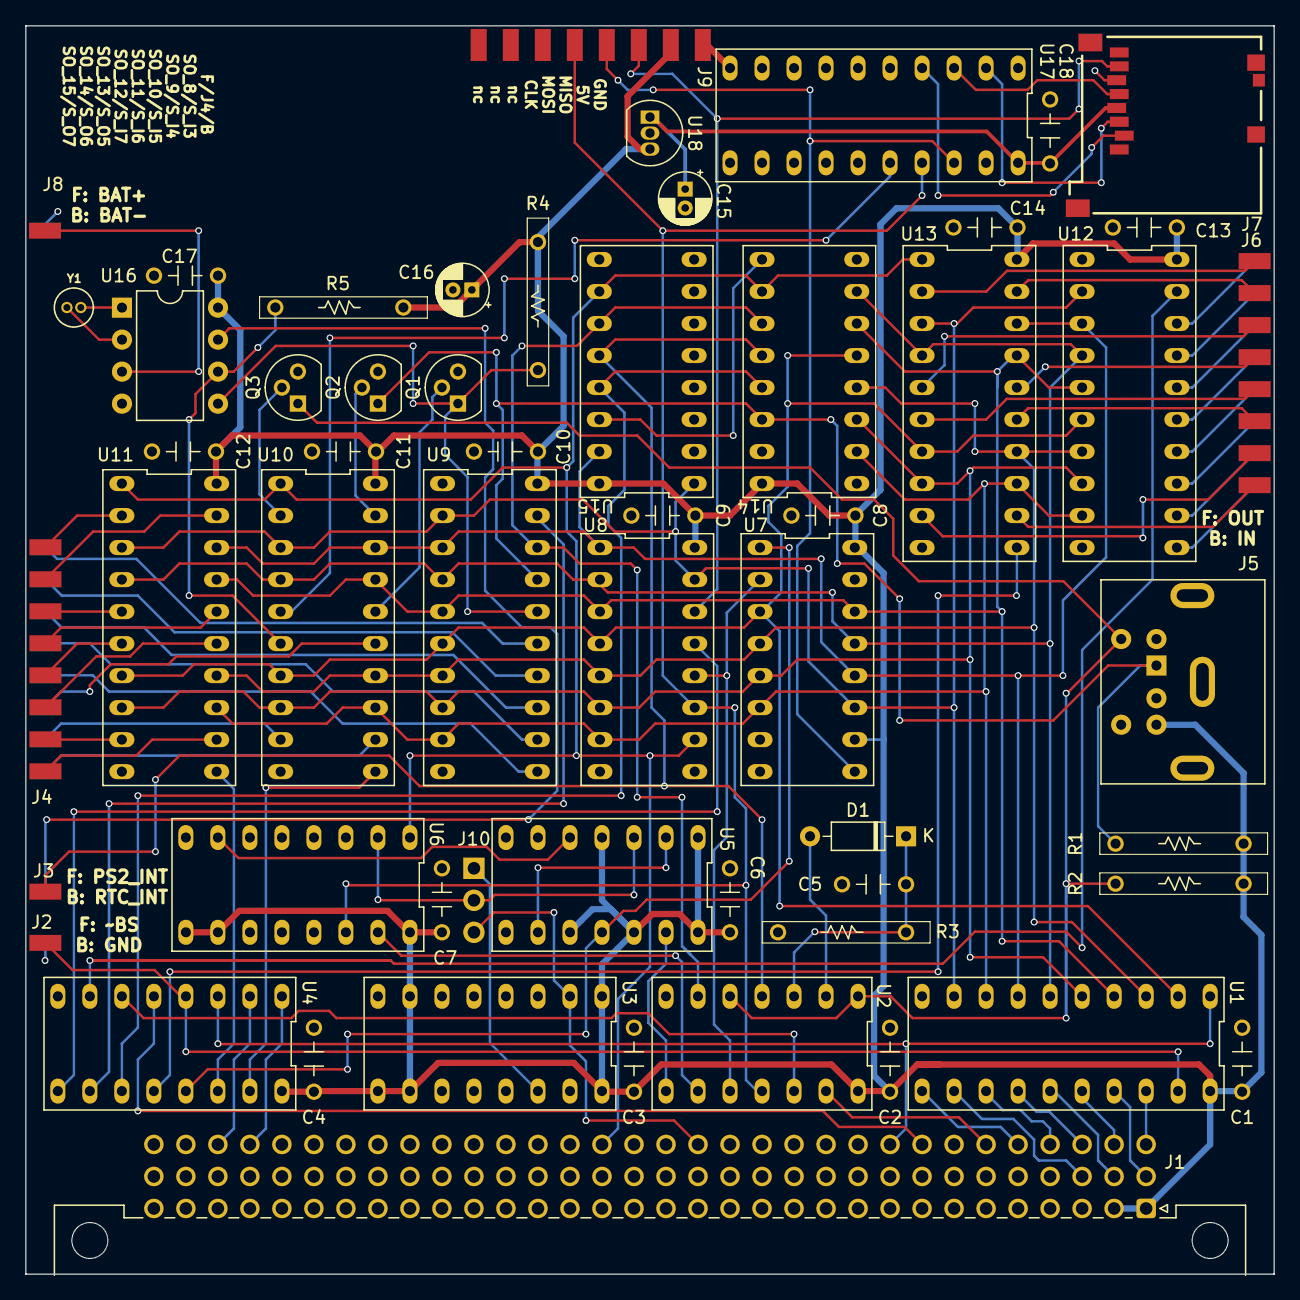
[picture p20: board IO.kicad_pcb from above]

Board: 4 copper layers, 99.1 x 99.1 mm, 56 parts (0 on the bottom side), 98 nets.

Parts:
C1, C2, C3, C4, C6, C7, C8, C9, C10, C11, C12, C13, C14, C17, C18: 100n; DIP-2_200_ELL
C5: 100nF; DIP-2_200_ELL
C15, C16: C_Polarized; CP_Radial_D4.0mm_P1.50mm
D1: D; D_DO-35_SOD27_P7.62mm_Horizontal
J1: 3x32; DIN41612_R_3x32_Male_Horizontal_THT
J2, J3, J8: 2x01; 2x01 finger
J4: Conn_02x08_Top_Bottom; 2x08 finger
J5: Mini-DIN-6; din
J6: 02x08; 2x08 finger
J7: Micro_SD_Card_Det; sd
J9: 2x08; 2x08 finger
J10: 1x03; PinHeader_1x03_P2.54mm_Vertical
Q1, Q2, Q3: Q_NMOS_DGS; TO-92
R1, R2, R3: 1K; res
R4, R5: R; res
U1, U9, U12: 74HC245; DIP-20
U2: 74HC14; DIP-14
U3, U6: 74LS161; DIP-16
U4: 74LS138; DIP-16
U5: 74HC74; DIP-14
U7: 74HC165; DIP-16
U8, U14, U15: 74HC595; DIP-16
U10, U11, U13: 74HC273; DIP-20
U16: DS1307+; DIP-8_W7.62mm
U17: 74LVC245; DIP-20
U18: LP2950-3.3_TO92; TO-92_Inline
Y1: 32768hz; XTAL_ECS-.327-12.5-8X-C

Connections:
+3V3: C15.1, C18.1, J7.4 (VDD), U17.20 (VCC), U18.1 (VO)
+5V: C1.1, C2.1, C3.1, C4.1, C6.1, C7.1, C8.1, C9.1, C10.1, C11.1, C12.1, C13.1, C14.1, C16.1, C17.1, J1.a1, J1.a2, J5.4, J9.2, R1.1, R2.1, R4.1, R5.1, U1.20 (VCC), U2.14 (VCC), U3.1 (~MR), U3.7 (CEP), U3.9 (~PE), U3.10 (CET), U3.16 (VCC), U4.16 (VCC), U5.1 (~R), U5.4 (~S), U5.10 (~S), U5.12 (D), U5.14 (VCC), U6.9 (~PE), U6.10 (CET), U6.16 (VCC), U7.10 (DS), U7.16 (VCC), U8.16 (VCC), U9.20 (VCC), U10.20 (VCC), U11.20 (VCC), U12.20 (VCC), U13.20 (VCC), U14.16 (VCC), U15.16 (VCC), U16.8 (VCC), U18.3 (VI)
/A1: J1.c29, U4.1 (A0)
/A2: J1.c30, U4.2 (A1)
/BD0: U1.9 (A7), U7.11 (D0), U8.15 (QA), U9.2 (A0), U10.3 (D0), U11.3 (D0), U12.2 (A0), U13.3 (D0), U15.1 (QB)
/BD1: U1.7 (A5), U7.12 (D1), U8.1 (QB), U9.3 (A1), U10.18 (D7), U11.18 (D7), U12.3 (A1), U13.18 (D7), U15.15 (QA)
/BD2: U1.6 (A4), U7.13 (D2), U8.2 (QC), U9.4 (A2), U10.4 (D1), U11.4 (D1), U12.4 (A2), U13.4 (D1), U14.7 (QH)
/BD3: U1.4 (A2), U7.14 (D3), U8.3 (QD), U9.5 (A3), U10.17 (D6), U11.17 (D6), U12.5 (A3), U13.17 (D6), U14.6 (QG)
/BD4: U1.2 (A0), U7.3 (D4), U8.4 (QE), U9.6 (A4), U10.7 (D2), U11.7 (D2), U12.6 (A4), U13.7 (D2), U14.5 (QF)
/BD5: U1.3 (A1), U7.4 (D5), U8.5 (QF), U9.7 (A5), U10.14 (D5), U11.14 (D5), U12.7 (A5), U13.14 (D5), U14.4 (QE)
/BD6: U1.5 (A3), U7.5 (D6), U8.6 (QG), U9.8 (A6), U10.8 (D3), U11.8 (D3), U12.8 (A6), U13.8 (D3), U14.3 (QD)
/BD7: U1.8 (A6), U7.6 (D7), U8.7 (QH), U9.9 (A7), U10.13 (D4), U11.13 (D4), U12.9 (A7), U13.13 (D4), U14.2 (QC)
/CLK: J1.c15, J10.3, U3.2 (CP)
/CLK2: J10.1, U3.14 (Q0)
/D0: J1.c5, U1.11 (B7)
/D1: J1.c4, U1.13 (B5)
/D2: J1.c3, U1.14 (B4)
/D3: J1.c2, U1.16 (B2)
/D4: J1.c1, U1.18 (B0)
/D5: J1.b1, U1.17 (B1)
/D6: J1.b2, U1.15 (B3)
/D7: J1.b3, U1.12 (B6)
/IO_RD_0: U4.11 (O4), U14.13 (~OE), U15.13 (~OE)
/IO_RD_1: U4.10 (O5), U9.19 (CE)
/IO_RD_2: U4.9 (O6), U8.13 (~OE)
/IO_RD_3: U4.7 (O7), U12.19 (CE)
/IO_WR_0: U4.15 (O0), U10.11 (Cp)
/IO_WR_1: U4.14 (O1), U11.11 (Cp)
/IO_WR_2: U4.13 (O2), U5.11 (C), U7.1 (~PL)
/IO_WR_3: U4.12 (O3), U13.11 (Cp)
/OD0: J6.1, U13.2 (Q0)
/OD1: J6.2, U13.19 (Q7)
/OD2: J6.3, U13.5 (Q1)
/OD3: J6.4, U13.16 (Q6)
/OD4: J6.5, U13.6 (Q2)
/OD5: J6.6, U13.15 (Q5)
/OD6: J6.7, U13.9 (Q3)
/OD7: J6.8, U13.12 (Q4)
/PS2_CLOCK: Q3.2 (G), U10.2 (Q0)
/PS2_DATA: Q2.2 (G), U10.19 (Q7)
/PS2_INT: J3.1, U2.4, U14.12 (RCLK), U15.12 (RCLK)
/RTC_INT: J3.2, U16.7 (SQW/OUT)
/R/~W: J1.c9, U1.1 (A->B), U4.3 (A2)
/SCL: R5.2, U10.6 (Q2), U16.6 (SCL)
/SDA: Q1.1 (D), R4.2, U9.16 (B2), U16.5 (SDA)
/SD_CLK: J7.5 (CLK), U17.3 (A1)
/SD_CS0: J7.2 (DAT3/CD), U17.4 (A2)
/SD_D1: J7.3 (CMD), U17.2 (A0)
/SD_DO: J7.7 (DAT0), J9.3, U8.14 (SER)
/SPI_CE0: U10.5 (Q1), U17.16 (B2)
/SPI_CLK: J9.5, U2.11, U6.14 (Q0), U8.11 (SRCLK), U17.17 (B1)
/SPI_MOSI: J9.4, U7.9 (Q7), U17.18 (B0)
/SYS_IN_3: J4.16, U9.15 (B3)
/SYS_IN_4: J4.15, U9.14 (B4)
/SYS_IN_5: J4.14, U9.13 (B5)
/SYS_IN_6: J4.13, U9.12 (B6)
/SYS_IN_7: J4.12, U9.11 (B7)
/SYS_OUT_5: J4.11, U10.15 (Q5)
/SYS_OUT_6: J4.10, U10.9 (Q3)
/SYS_OUT_7: J4.9, U10.12 (Q4)
/SYS_OUT_8: J4.8, U11.2 (Q0)
/SYS_OUT_9: J4.7, U11.19 (Q7)
/SYS_OUT_10: J4.6, U11.5 (Q1)
/SYS_OUT_11: J4.5, U11.16 (Q6)
/SYS_OUT_12: J4.4, U11.6 (Q2)
/SYS_OUT_13: J4.3, U11.15 (Q5)
/SYS_OUT_14: J4.2, U11.9 (Q3)
/SYS_OUT_15: J4.1, U11.12 (Q4)
/~AS: J1.c6, U2.13
/~BS: J2.1, U1.19 (CE), U4.4 (E1)
/~LDS: J1.c8, U4.5 (E2)
/~RST: J1.c18, U6.1 (~MR), U8.10 (~SRCLR), U10.1 (~Mr), U11.1 (~Mr), U13.1 (~Mr), U14.10 (~SRCLR), U15.10 (~SRCLR)
/~SPI_CLK: U2.10, U7.2 (CP), U8.12 (RCLK)
GND: C1.2, C2.2, C3.2, C4.2, C5.2, C6.2, C7.2, C8.2, C9.2, C10.2, C11.2, C12.2, C13.2, C14.2, C15.2, C16.2, C17.2, C18.2, J1.a3, J1.a6, J1.a9, J1.a12, J1.a15, J1.a18, J1.a21, J1.a24, J1.a27, J1.a30, J2.2, J5.3, J7.6 (VSS), J8.2, J9.1, Q1.3 (S), Q2.3 (S), Q3.3 (S), R3.2, U1.10 (GND), U2.7 (GND), U3.3 (D0), U3.4 (D1), U3.5 (D2), U3.6 (D3), U3.8 (GND), U4.8 (GND), U5.7 (GND), U6.3 (D0), U6.4 (D1), U6.5 (D2), U6.6 (D3), U6.8 (GND), U7.8 (GND), U7.15 (~CE), U8.8 (GND), U9.1 (A->B), U9.10 (GND), U10.10 (GND), U11.10 (GND), U12.1 (A->B), U12.10 (GND), U13.10 (GND), U14.8 (GND), U15.8 (GND), U16.4 (GND), U17.1 (A->B), U17.10 (GND), U17.19 (CE), U18.2 (GND)
unnamed: C5.1, D1.1 (K), R3.1, U2.3
unnamed: D1.2 (A), U2.2
unnamed: J5.1, Q2.1 (D), R1.2, U9.17 (B1), U14.14 (SER)
unnamed: J5.5, Q3.1 (D), R2.2, U2.1, U2.5
unnamed: J6.9, U12.18 (B0)
unnamed: J6.10, U12.17 (B1)
unnamed: J6.11, U12.16 (B2)
unnamed: J6.12, U12.15 (B3)
unnamed: J6.13, U12.14 (B4)
unnamed: J6.14, U12.13 (B5)
unnamed: J6.15, U12.12 (B6)
unnamed: J6.16, U12.11 (B7)
unnamed: J8.1, U16.3 (VBAT)
unnamed: J10.2, U5.3 (C), U6.2 (CP)
unnamed: Q1.2 (G), U10.16 (Q6)
unnamed: U2.8, U5.13 (~R)
unnamed: U2.9, U6.15 (TC)
unnamed: U2.12, U4.6 (E3)
unnamed: U5.2 (D), U5.9 (Q)
unnamed: U5.5 (Q), U6.7 (CEP)
unnamed: U14.9 (QH'), U15.14 (SER)
unnamed: U2.6, U9.18 (B0), U14.11 (SRCLK), U15.11 (SRCLK)
unnamed: U16.1 (X1), Y1.2
unnamed: U16.2 (X2), Y1.1

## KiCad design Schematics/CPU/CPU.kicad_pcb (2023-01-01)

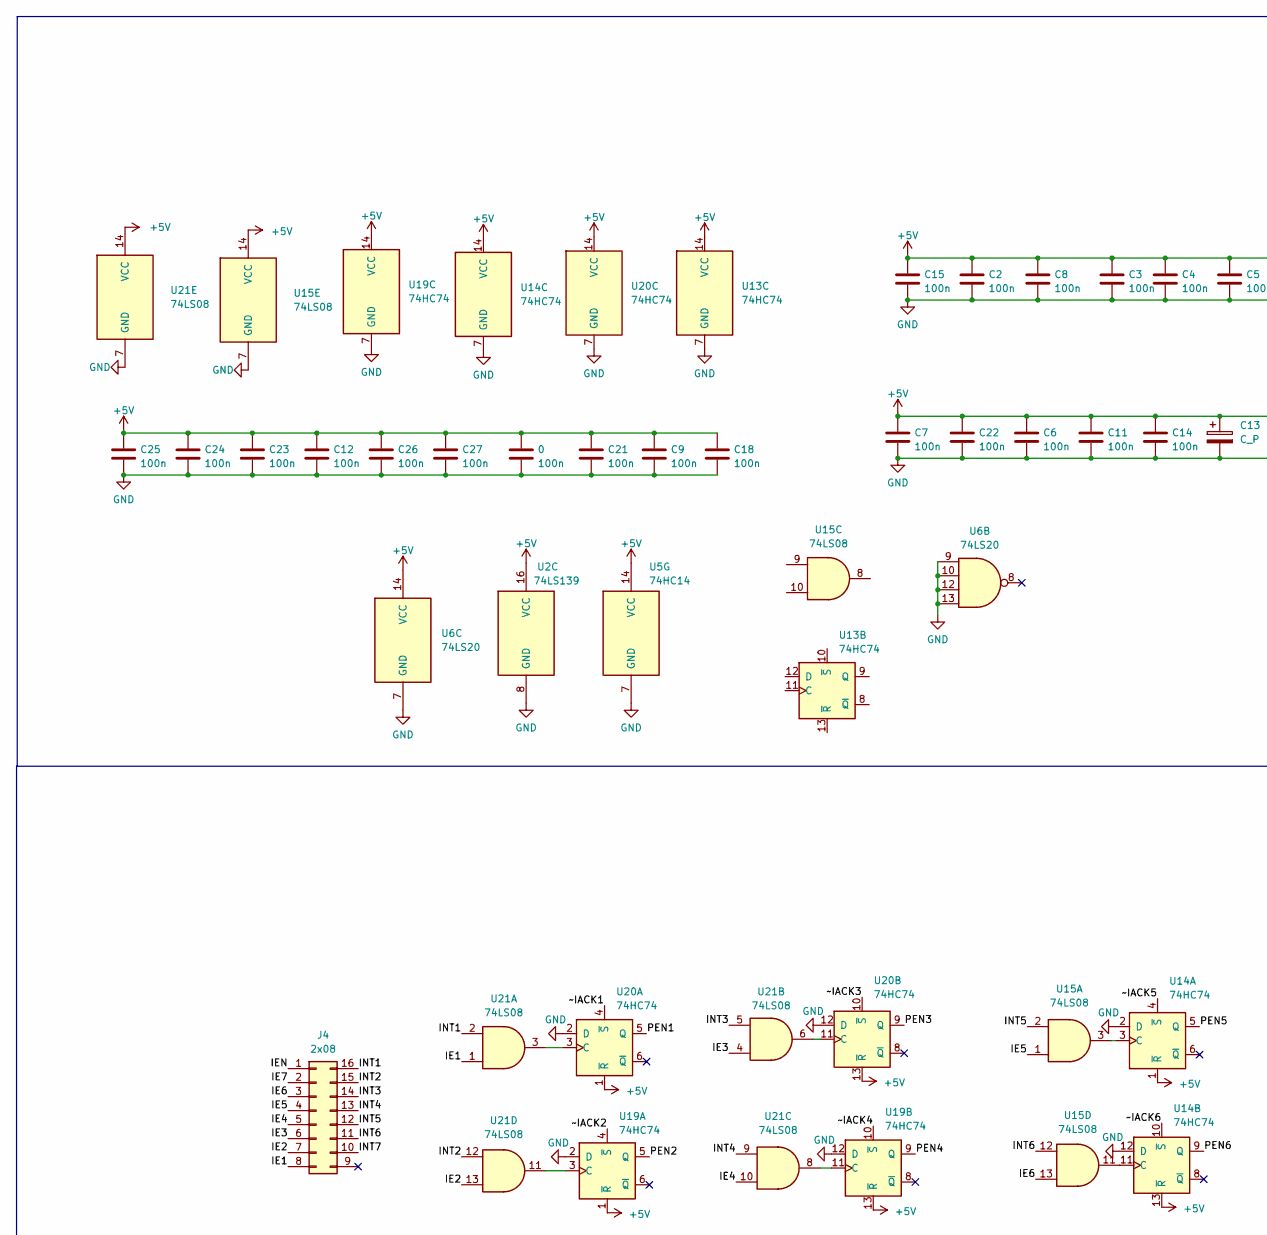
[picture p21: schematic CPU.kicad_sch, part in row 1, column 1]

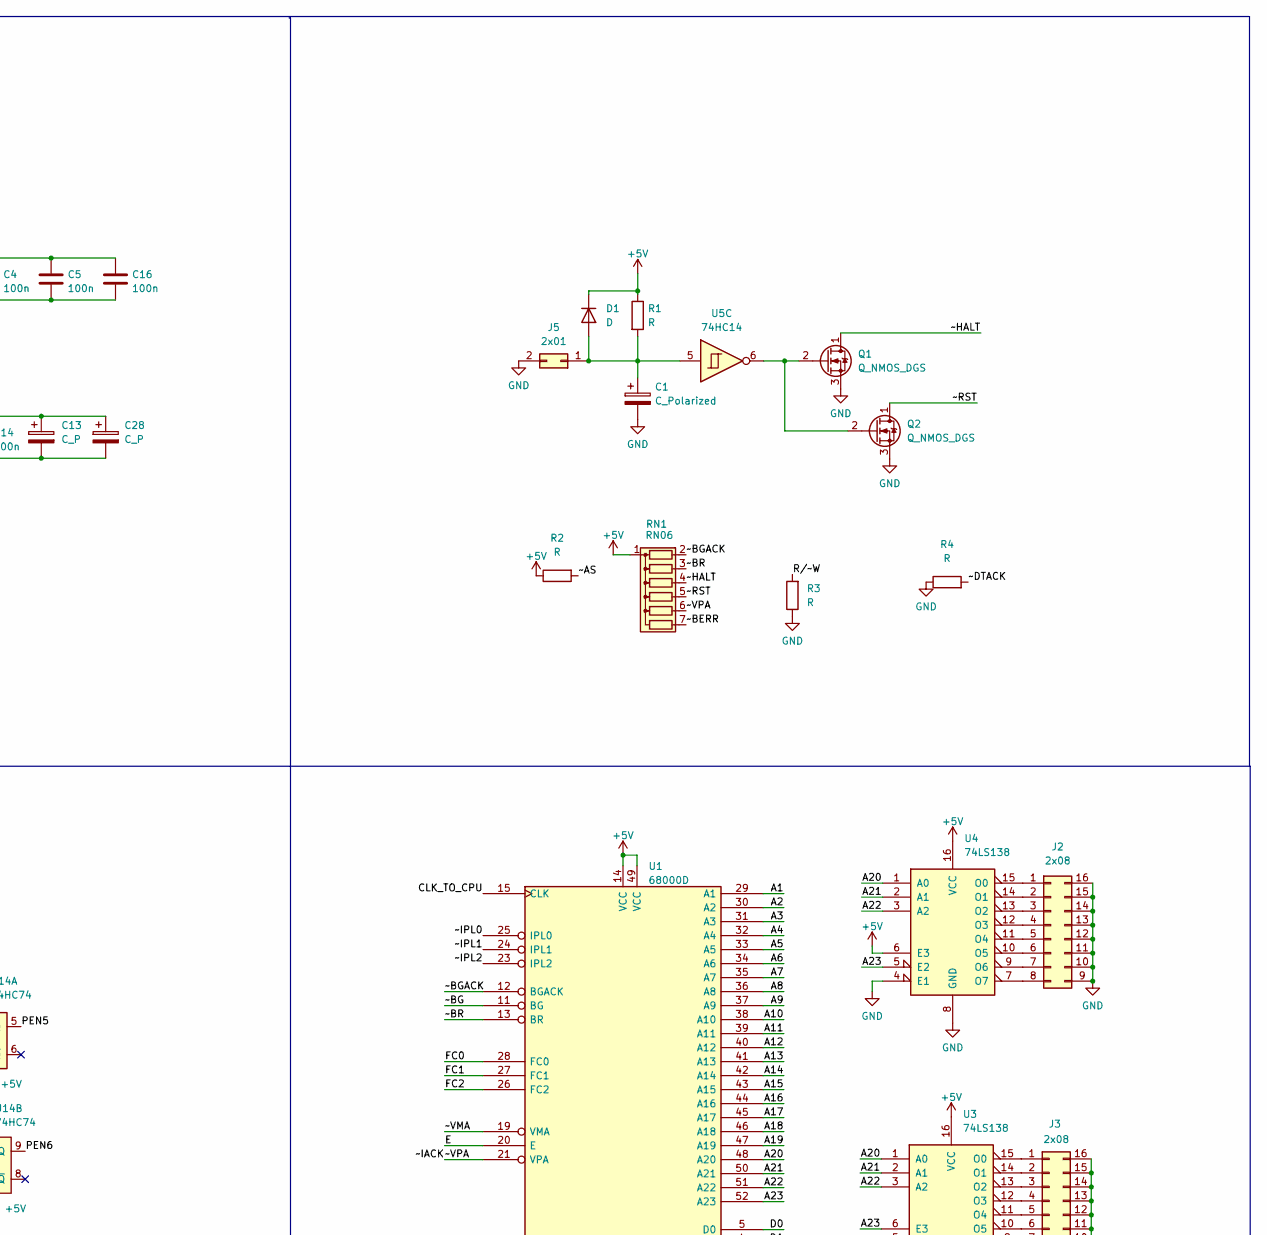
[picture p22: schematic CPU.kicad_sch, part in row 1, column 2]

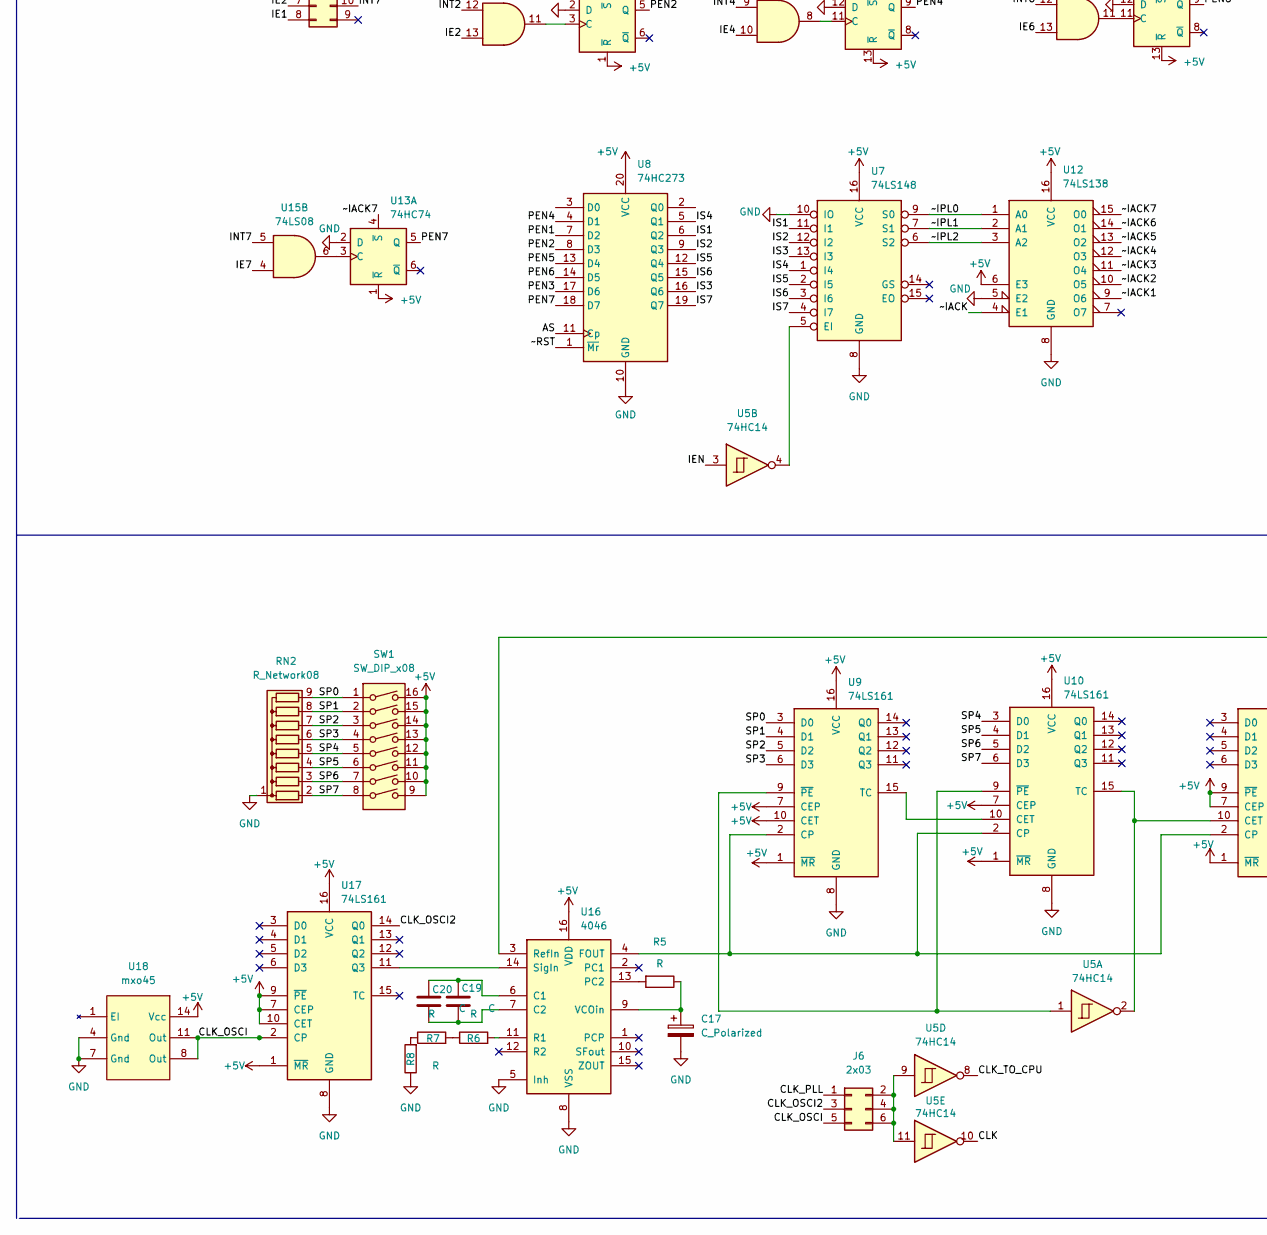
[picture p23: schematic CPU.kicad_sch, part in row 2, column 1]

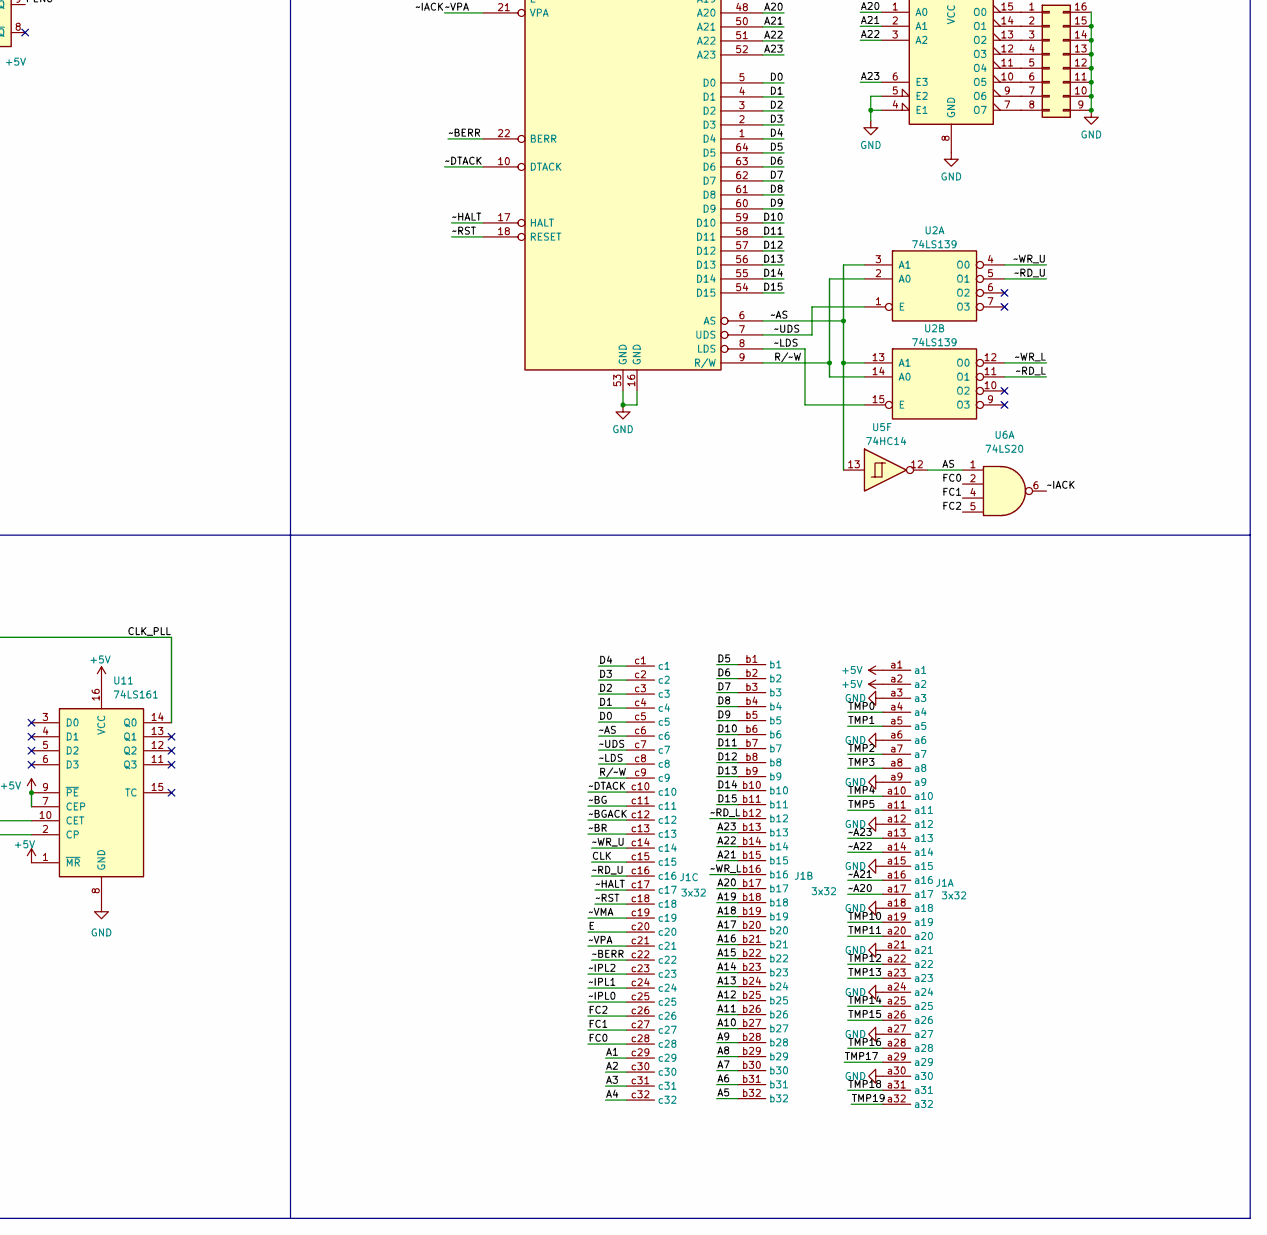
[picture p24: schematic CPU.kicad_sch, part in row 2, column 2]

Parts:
0: 100n; DIP-2_200_ELL
C1, C17: C_Polarized; CP_Radial_D4.0mm_P1.50mm
C2, C3, C4, C5, C6, C7, C8, C9, C11, C12, C14, C15, C16, C18, C21, C22, C23, C24, C25, C26, C27: 100n; DIP-2_200_ELL
C13, C28: C_P; CP_Radial_D4.0mm_P1.50mm
C19, C20: C; DIP-2_200_ELL
D1: D; D_DO-35_SOD27_P7.62mm_Horizontal
J1: 3x32; DIN41612_R_3x32_Male_Horizontal_THT
J2, J3, J4: 2x08; 2x08 finger
J5: 2x01; 2x01 finger
J6: 2x03; PinHeader_2x03_P2.54mm_Vertical
Q1, Q2: Q_NMOS_DGS; TO-92
R1, R2, R3, R4: R; res
R5, R6, R7, R8: R; R_Axial_DIN0411_L9.9mm_D3.6mm_P5.08mm_Vertical
RN1: RN06; R_Array_SIP7
RN2: R_Network08; R_Array_SIP9
SW1: SW_DIP_x08; DIP-16
U1: 68000D; DIP-64_875_ELL
U2: 74LS139; DIP-16
U3, U4, U12: 74LS138; DIP-16
U5: 74HC14; DIP-14
U6: 74LS20; DIP-14
U7: 74LS148; DIP-16
U8: 74HC273; DIP-20
U9, U10, U11, U17: 74LS161; DIP-16
U13, U14, U19, U20: 74HC74; DIP-14
U15, U21: 74LS08; DIP-14
U16: 4046; DIP-16
U18: mxo45

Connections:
+5V: 0.1, C2.1, C3.1, C4.1, C5.1, C6.1, C7.1, C8.1, C9.1, C11.1, C12.1, C13.1, C14.1, C15.1, C16.1, C18.1, C21.1, C22.1, C23.1, C24.1, C25.1, C26.1, C27.1, C28.1, D1.1 (K), J1.a1, J1.a2, R1.1, R2.1, RN1.1 (common), SW1.9, SW1.10, SW1.11, SW1.12, SW1.13, SW1.14, SW1.15, SW1.16, U1.14 (VCC), U1.49 (VCC), U2.16 (VCC), U3.16 (VCC), U4.6 (E3), U4.16 (VCC), U5.14 (VCC), U6.14 (VCC), U7.16 (VCC), U8.20 (VCC), U9.1 (~MR), U9.7 (CEP), U9.10 (CET), U9.16 (VCC), U10.1 (~MR), U10.7 (CEP), U10.16 (VCC), U11.1 (~MR), U11.7 (CEP), U11.9 (~PE), U11.16 (VCC), U12.6 (E3), U12.16 (VCC), U13.1 (~R), U13.14 (VCC), U14.1 (~R), U14.13 (~R), U14.14 (VCC), U15.14 (VCC), U16.16 (VDD), U17.1 (~MR), U17.7 (CEP), U17.9 (~PE), U17.10 (CET), U17.16 (VCC), U18.14 (Vcc), U19.1 (~R), U19.13 (~R), U19.14 (VCC), U20.1 (~R), U20.13 (~R), U20.14 (VCC), U21.14 (VCC)
/A1: J1.c29, U1.29 (A1)
/A2: J1.c30, U1.30 (A2)
/A3: J1.c31, U1.31 (A3)
/A4: J1.c32, U1.32 (A4)
/A5: J1.b32, U1.33 (A5)
/A6: J1.b31, U1.34 (A6)
/A7: J1.b30, U1.35 (A7)
/A8: J1.b29, U1.36 (A8)
/A9: J1.b28, U1.37 (A9)
/A10: J1.b27, U1.38 (A10)
/A11: J1.b26, U1.39 (A11)
/A12: J1.b25, U1.40 (A12)
/A13: J1.b24, U1.41 (A13)
/A14: J1.b23, U1.42 (A14)
/A15: J1.b22, U1.43 (A15)
/A16: J1.b21, U1.44 (A16)
/A17: J1.b20, U1.45 (A17)
/A18: J1.b19, U1.46 (A18)
/A19: J1.b18, U1.47 (A19)
/A20: J1.b17, U1.48 (A20), U3.1 (A0), U4.1 (A0)
/A21: J1.b15, U1.50 (A21), U3.2 (A1), U4.2 (A1)
/A22: J1.b14, U1.51 (A22), U3.3 (A2), U4.3 (A2)
/A23: J1.b13, U1.52 (A23), U3.6 (E3), U4.5 (E2)
/AS: U5.12, U6.1, U8.11 (Cp)
/CLK: J1.c15, U5.10
/CLK_OSCI: J6.5, U17.2 (CP), U18.8 (Out), U18.11 (Out)
/CLK_OSCI2: J6.3, U17.14 (Q0)
/CLK_PLL: J6.1, U11.14 (Q0), U16.3 (RefIn)
/CLK_TO_CPU: U1.15 (CLK), U5.8
/D0: J1.c5, U1.5 (D0)
/D1: J1.c4, U1.4 (D1)
/D2: J1.c3, U1.3 (D2)
/D3: J1.c2, U1.2 (D3)
/D4: J1.c1, U1.1 (D4)
/D5: J1.b1, U1.64 (D5)
/D6: J1.b2, U1.63 (D6)
/D7: J1.b3, U1.62 (D7)
/D8: J1.b4, U1.61 (D8)
/D9: J1.b5, U1.60 (D9)
/D10: J1.b6, U1.59 (D10)
/D11: J1.b7, U1.58 (D11)
/D12: J1.b8, U1.57 (D12)
/D13: J1.b9, U1.56 (D13)
/D14: J1.b10, U1.55 (D14)
/D15: J1.b11, U1.54 (D15)
/E: J1.c20, U1.20 (E)
/FC0: J1.c28, U1.28 (FC0), U6.2
/FC1: J1.c27, U1.27 (FC1), U6.4
/FC2: J1.c26, U1.26 (FC2), U6.5
/IE1: J4.8, U21.1
/IE2: J4.7, U21.13
/IE3: J4.6, U21.4
/IE4: J4.5, U21.10
/IE5: J4.4, U15.1
/IE6: J4.3, U15.13
/IE7: J4.2, U15.4
/IEN: J4.1, U5.3
/INT1: J4.16, U21.2
/INT2: J4.15, U21.12
/INT3: J4.14, U21.5
/INT4: J4.13, U21.9
/INT5: J4.12, U15.2
/INT6: J4.11, U15.12
/INT7: J4.10, U15.5
/IS1: U7.11 (I1), U8.6 (Q2)
/IS2: U7.12 (I2), U8.9 (Q3)
/IS3: U7.13 (I3), U8.16 (Q6)
/IS4: U7.1 (I4), U8.5 (Q1)
/IS5: U7.2 (I5), U8.12 (Q4)
/IS6: U7.3 (I6), U8.15 (Q5)
/IS7: U7.4 (I7), U8.19 (Q7)
/PEN1: U8.7 (D2), U20.5 (Q)
/PEN2: U8.8 (D3), U19.5 (Q)
/PEN3: U8.17 (D6), U20.9 (Q)
/PEN4: U8.4 (D1), U19.9 (Q)
/PEN5: U8.13 (D4), U14.5 (Q)
/PEN6: U8.14 (D5), U14.9 (Q)
/PEN7: U8.18 (D7), U13.5 (Q)
/R/~W: J1.c9, R3.2, U1.9 (R/W), U2.2 (A0), U2.14 (A0)
/SP0: RN2.9 (R8), SW1.1, U9.3 (D0)
/SP1: RN2.8 (R7), SW1.2, U9.4 (D1)
/SP2: RN2.7 (R6), SW1.3, U9.5 (D2)
/SP3: RN2.6 (R5), SW1.4, U9.6 (D3)
/SP4: RN2.5 (R4), SW1.5, U10.3 (D0)
/SP5: RN2.4 (R3), SW1.6, U10.4 (D1)
/SP6: RN2.3 (R2), SW1.7, U10.5 (D2)
/SP7: RN2.2 (R1), SW1.8, U10.6 (D3)
/TMP0: J1.a4
/TMP1: J1.a5
/TMP2: J1.a7
/TMP3: J1.a8
/TMP4: J1.a10
/TMP5: J1.a11
/TMP10: J1.a19
/TMP11: J1.a20
/TMP12: J1.a22
/TMP13: J1.a23
/TMP14: J1.a25
/TMP15: J1.a26
/TMP16: J1.a28
/TMP17: J1.a29
/TMP18: J1.a31
/TMP19: J1.a32
/~A20: J1.a17
/~A21: J1.a16
/~A22: J1.a14
/~A23: J1.a13
/~AS: J1.c6, R2.2, U1.6 (AS), U2.3 (A1), U2.13 (A1), U5.13
/~BERR: J1.c22, RN1.7 (R6), U1.22 (BERR)
/~BG: J1.c11, U1.11 (BG)
/~BGACK: J1.c12, RN1.2 (R1), U1.12 (BGACK)
/~BR: J1.c13, RN1.3 (R2), U1.13 (BR)
/~DTACK: J1.c10, R4.2, U1.10 (DTACK)
/~HALT: J1.c17, Q1.1 (D), RN1.4 (R3), U1.17 (HALT)
/~IACK: J1.c21, RN1.6 (R5), U1.21 (VPA), U6.6, U12.4 (E1)
/~IACK1: U12.9 (O6), U20.4 (~S)
/~IACK2: U12.10 (O5), U19.4 (~S)
/~IACK3: U12.11 (O4), U20.10 (~S)
/~IACK4: U12.12 (O3), U19.10 (~S)
/~IACK5: U12.13 (O2), U14.4 (~S)
/~IACK6: U12.14 (O1), U14.10 (~S)
/~IACK7: U12.15 (O0), U13.4 (~S)
/~IPL0: J1.c25, U1.25 (IPL0), U7.9 (S0), U12.1 (A0)
/~IPL1: J1.c24, U1.24 (IPL1), U7.7 (S1), U12.2 (A1)
/~IPL2: J1.c23, U1.23 (IPL2), U7.6 (S2), U12.3 (A2)
/~LDS: J1.c8, U1.8 (LDS), U2.15 (E)
/~RD_L: J1.b12, U2.11 (O1)
/~RD_U: J1.c16, U2.5 (O1)
/~RST: J1.c18, Q2.1 (D), RN1.5 (R4), U1.18 (RESET), U8.1 (~Mr)
/~UDS: J1.c7, U1.7 (UDS), U2.1 (E)
/~VMA: J1.c19, U1.19 (VMA)
/~WR_L: J1.b16, U2.12 (O0)
/~WR_U: J1.c14, U2.4 (O0)
GND: 0.2, C1.2, C2.2, C3.2, C4.2, C5.2, C6.2, C7.2, C8.2, C9.2, C11.2, C12.2, C13.2, C14.2, C15.2, C16.2, C17.2, C18.2, C21.2, C22.2, C23.2, C24.2, C25.2, C26.2, C27.2, C28.2, J1.a3, J1.a6, J1.a9, J1.a12, J1.a15, J1.a18, J1.a21, J1.a24, J1.a27, J1.a30, J2.9, J2.10, J2.11, J2.12, J2.13, J2.14, J2.15, J2.16, J3.9, J3.10, J3.11, J3.12, J3.13, J3.14, J3.15, J3.16, J5.2, Q1.3 (S), Q2.3 (S), R3.1, R4.1, R8.1, RN2.1 (common), U1.16 (GND), U1.53 (GND), U2.8 (GND), U3.4 (E1), U3.5 (E2), U3.8 (GND), U4.4 (E1), U4.8 (GND), U5.7 (GND), U6.7 (GND), U6.9, U6.10, U6.12, U6.13, U7.8 (GND), U7.10 (IO), U8.10 (GND), U9.8 (GND), U10.8 (GND), U11.8 (GND), U12.5 (E2), U12.8 (GND), U13.2 (D), U13.7 (GND), U14.2 (D), U14.7 (GND), U14.12 (D), U15.7 (GND), U16.5 (Inh), U16.8 (VSS), U17.8 (GND), U18.4 (Gnd), U18.7 (Gnd), U19.2 (D), U19.7 (GND), U19.12 (D), U20.2 (D), U20.7 (GND), U20.12 (D), U21.7 (GND)
unnamed: C1.1, D1.2 (A), J5.1, R1.2, U5.5
unnamed: C17.1, R5.1, U16.9 (VCOin)
unnamed: C19.1, C20.1, U16.6 (C1)
unnamed: C19.2, C20.2, U16.7 (C2)
unnamed: J2.1, U4.15 (O0)
unnamed: J2.2, U4.14 (O1)
unnamed: J2.3, U4.13 (O2)
unnamed: J2.4, U4.12 (O3)
unnamed: J2.5, U4.11 (O4)
unnamed: J2.6, U4.10 (O5)
unnamed: J2.7, U4.9 (O6)
unnamed: J2.8, U4.7 (O7)
unnamed: J3.1, U3.15 (O0)
unnamed: J3.2, U3.14 (O1)
unnamed: J3.3, U3.13 (O2)
unnamed: J3.4, U3.12 (O3)
unnamed: J3.5, U3.11 (O4)
unnamed: J3.6, U3.10 (O5)
unnamed: J3.7, U3.9 (O6)
unnamed: J3.8, U3.7 (O7)
unnamed: J6.2, J6.4, J6.6, U5.9, U5.11
unnamed: Q1.2 (G), Q2.2 (G), U5.6
unnamed: R5.2, U16.13 (PC2)
unnamed: R6.1, R7.2
unnamed: R6.2, U16.11 (R1)
unnamed: R7.1, R8.2
unnamed: U5.4, U7.5 (EI)
unnamed: U9.2 (CP), U10.2 (CP), U11.2 (CP), U16.4 (FOUT)
unnamed: U5.1, U9.9 (~PE), U10.9 (~PE)
unnamed: U9.15 (TC), U10.10 (CET)
unnamed: U5.2, U10.15 (TC), U11.10 (CET)
unnamed: U13.3 (C), U15.6
unnamed: U14.3 (C), U15.3
unnamed: U14.11 (C), U15.11
unnamed: U16.14 (SigIn), U17.11 (Q3)
unnamed: U19.3 (C), U21.11
unnamed: U19.11 (C), U21.8
unnamed: U20.3 (C), U21.3
unnamed: U20.11 (C), U21.6



Board: 2 copper layers, 109.2 x 106.7 mm, 69 parts (4 on the bottom side), 154 nets.

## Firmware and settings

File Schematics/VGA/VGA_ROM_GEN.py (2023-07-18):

import struct

file = "out.bin"
output = open(file, "wb")

HSYNC = 1 #NEG
VSYNC = 2 #NEG
RESX = 4  #NEG
RESY = 8  #NEG
INCY = 16 
VIS = 32  #NEG

NEGATE = HSYNC | VSYNC | VIS | RESX | RESY

H_VIS = 640 / 16
H_FP = 16 / 16
H_SYNC = 96 / 16
H_BP = 48 / 16 

Y_VIS = 480
Y_FP = 10
Y_SYNC = 2
Y_BP = 33

for y in range(1024):
	for x in range(64):
		b = 0
		if x < H_VIS and y < Y_VIS:
			b |= VIS
			
		if x >= H_VIS + H_FP and x < H_VIS + H_FP + H_SYNC:
			b |= HSYNC
		if x == H_VIS + H_FP + H_SYNC + H_BP - 2:
			b |= INCY
		if x >= H_VIS + H_FP + H_SYNC + H_BP - 1:
			b |= RESX
			if y == Y_VIS + Y_FP + Y_SYNC + Y_BP - 1:
				b |= RESY
			else:
				b |= INCY
			
		if y >= Y_VIS + Y_FP and y < Y_VIS + Y_FP + Y_SYNC:
			b |= VSYNC
			
		b ^= NEGATE
		output.write(struct.pack('1B', b))
		output.write(struct.pack('1B', b))
		
H_VIS = (640 / 16) - 8
H_FP = (16 / 16) + 4
H_SYNC = (96 / 16)
H_BP = (48 / 16) + 4
		
Y_VIS = 480 / 2
		
for y in range(1024):
	for x in range(64):
		b = 0
		if x < H_VIS and y < Y_VIS:
			b |= VIS
			
		if x >= H_VIS + H_FP and x < H_VIS + H_FP + H_SYNC:
			b |= HSYNC
			
		if x == H_VIS + H_FP + H_SYNC + H_BP - 2 and y >= Y_VIS:
			b |= INCY
			
		if x >= H_VIS + H_FP + H_SYNC + H_BP - 1:
			b |= RESX
			if y == Y_VIS + Y_FP + Y_SYNC + Y_BP - 1:
				b |= RESY
			else:
				b |= INCY
			
		if ((y == Y_VIS + Y_FP - 1 and x >= 50-4) or (y == Y_VIS + Y_FP) or (y == Y_VIS + Y_FP + 1 and x < 4)):
			b |= VSYNC
			
		b ^= NEGATE
		output.write(struct.pack('1B', b))
		output.write(struct.pack('1B', b))
		
print("done")

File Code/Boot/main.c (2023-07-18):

#include "std.h"
#include "driver/sys.h"
#include "driver/PS2.h"
#include "malloc.h"
#include <TextBuff.h>
#include "Proc.h"
#include <string.h>
#include "driver/EventQ.h"
#include <ff.h>

	
void panic(u8* message){
	//DINT();
	Clear(VGA_PORT);
	int y = 0;
	WriteString(VGA_PORT, "       _______________________________", 0, (u32)(y++), 0b111000);
	WriteString(VGA_PORT, "     <                               >", 0, (u32)(y), 0b111000);
	WriteString(VGA_PORT, message, 8, (u32)(y++), 0b111000);
	WriteString(VGA_PORT, "       -------------------------------", 0, (u32)(y++), 0b111000);
	WriteString(VGA_PORT, "              \\   ^__^", 0, (u32)(y++), 0b111000);
	WriteString(VGA_PORT, "               \\  (xx)\\_______", 0, (u32)(y++), 0b111000);
	WriteString(VGA_PORT, "                  (__)\\       )\\/\\", 0, (u32)(y++), 0b111000);
	WriteString(VGA_PORT, "                   U  ||----w |", 0, (u32)(y++), 0b111000);
	WriteString(VGA_PORT, "                      ||     ||", 0, (u32)(y++), 0b111000);
	SYS_PORT_TOGGLE(SYS_OUT_PORT_7);
	while(1);
}

u8 _2MB;
u8 buff[256];

extern const u32 _HEEP_START;

event Sys_GetEvent(){
	return GetEvent();
}

void kern(){
	asm __volatile__("movea.l #_stack_end, %sp"); //fresh stack every time we enter kernel 
	asm __volatile__("jmp kern_ent"); 
}

FATFS driveFATFS[1];

FATFS* GetFATFS(u16 *drives){
	*drives = 1;
	return driveFATFS;
}

//void __attribute__((interrupt)) TRAP15(void){
//	
//}



u16 trapRunPid = 0xFFFF;

void launchProcTrap15(){
	u16 trp = trapRunPid;
	trapRunPid = 0xFFFF;
	LaunchProc(trp);
}

int Sys_RunProc(char* path){
	//u16 pid_return;
	u16 i = LoadProc(path, 0, &trapRunPid);
	if(i) return i;
	//trapRunPid = 
	asm("trap #15");
	return 0;
}

extern u32 const _bss_start;
extern u32 const _bss_end;
extern u32 const _rodata_end;
extern u32 const _data_start;
extern u32 const _data_end;

void main(){
	asm __volatile__("movea.l #0x00100B50, %sp"); //fresh stack every time we enter kernel 
	asm __volatile__("jmp main_ent"); //fresh stack every time we enter kernel 
}

void main_ent(){
	asm __volatile__("movea.l #_stack_end, %sp"); //we need a stack to use function calls

	memset((void*) &_bss_start, 0, (u32)(&_bss_end) - (u32)(&_bss_start));
	memcpy((void*)&_data_start, (void*) &_rodata_end, (u32)(&_data_end) -  (u32)(&_data_start));
	
	INT_E_RESET(INT_SOURCE_GLOBAL);	//no interrupts

	asm __volatile__("move.w  #0x2000, %sr");
	
	//Do we have a second MB?
	_2MB = 1;
	for(int i = 0; i < 16; i++){
		((u16*)REG2)[i] = i;
	}
	for(int i = 0; i < 16; i++){
		if(((u16*)REG2)[i] != i){
			_2MB = 0;
		}
	}
	
	MallocInit(_2MB);
	
	for(int i =0 ; i< TOTAL_PIDS; i++){
		runningProc[i] = 0;
	}
	
	currentProc = 0xFFFF;
	//Init PS2 Keyboard
	if(PS2_INIT()){
		panic("KB init error");		
	}
	INT_E_SET(INT_SOURCE_PS2 | INT_SOURCE_GLOBAL);
	
	driveFATFS[0].fs_type = 0;
	
	kern();
}

void UNDEF_SYSCALL(){
	panic("UNDEF_SYSCALL");
}

void __attribute__((interrupt)) IRQ1(void){
	//writeString("IRQ1", VGA_PORT, 0, y++, 0b111000);
}

void __attribute__((interrupt)) IRQ2(void){
	//writeString("IRQ2", VGA_PORT, 0, y++, 0b111000);
}

void __attribute__((interrupt)) IRQ3(void){
	//writeString("IRQ3", VGA_PORT, 0, y++, 0b111000);

		for(int i = 0; i < 256; i++){
			*SYSR_INTW  = (u8) i;
		}

}

void PrivilegeViolation(void){
	u32 PC = 0;
	__asm__ __volatile__(" move.l (%%sp)+, %[pc]\n"
						: [ pc ] "=d"(PC)
						: 
						:);
	
	//sprintf(buff, "PrivilegeViolation @%p", (u32) PC);
 	panic("PrivilegeViolation @%p");
}

void AddressError(void){
	panic("AddressError");
}

//const u8 *toHex = "0123456789ABCDEF";

void __attribute__((interrupt)) IRQ4(void){
	//writeString("IRQ4", VGA_PORT, 0, (u32)(y++), 0b111000);
	//u8 val = READ_PS2_PORT();
	//u8 b[] = {toHex[(val >> 4)& 0x0F], toHex[val & 0x0F], 0};
	//writeString(b, VGA_PORT, 0, (u32)(y++), 0b111000);
}   

void __attribute__((interrupt)) IRQ5(void){
	//writeString("IRQ5", VGA_PORT, 0, y++, 0b111000);
}

void __attribute__((interrupt)) IRQ6(void){
	//writeString("IRQ6", VGA_PORT, 0, y++, 0b111000);
}

void core_dump(){
	u8 log_drive[] = "0:";
	if(!driveFATFS[0].fs_type){
		FRESULT res = f_mount(&driveFATFS[0], log_drive, 1);
		if(res) panic("dump failed");
	}
	u8 log_file[] = "0:/dump.bin";
	FIL fp;
	f_open(&fp, log_file, FA_CREATE_ALWAYS | FA_WRITE);
	UINT br, bw;
	f_write(&fp, (void*) 0, (u32)0x200000, &bw);  
	f_close(&fp);
}

asm(R"(
.global returnToProc
returnToProc:
	moveq #0,%d0
	move.w currentProc,%d0
	add.l %d0,%d0
	add.l %d0,%d0
	lea runningProc,%a0
	move.l (%a0,%d0.l),%a0
	add #32, %a0
	
	#get d2-d7 / a2-a6
	move.l (%a0)+, %d2 
	move.l (%a0)+, %d3 
	move.l (%a0)+, %d4 
	move.l (%a0)+, %d5 
	move.l (%a0)+, %d6 
	move.l (%a0)+, %d7 
	move.l (%a0)+, %a2 
	move.l (%a0)+, %a3 
	move.l (%a0)+, %a4 
	move.l (%a0)+, %a5 
	move.l (%a0)+, %a6 
	
	lea (-22,%sp),%sp

	#get d0/d1/a0/a1 and put on stack
	move.l (%a0)+, (%sp)
	move.l (%a0)+, 4(%sp)
	move.l (%a0)+, 8(%sp)
	move.l (%a0)+, 12(%sp)
	
	#sr
	move.w (%a0)+, 16(%sp)
	
	#get pc
	move.l (%a0)+, 18(%sp)
		
	#get sp
	move.l (%a0)+, %a1
	move.l %a1, %usp
	
	#get d0/d1/a0/a1 from stack
	movem.l (%sp)+,#771
	rte
	)");

asm(R"(
.global TRAP15
TRAP15:
	movem.l #49344,-(%sp)

	moveq #0,%d0
	move.w currentProc,%d0
	add.l %d0,%d0
	add.l %d0,%d0
	lea runningProc,%a0
	move.l (%a0,%d0.l),%a0
	add #32, %a0
	
	#save d2-d7 / a2-a6
	move.l %d2, (%a0)+
	move.l %d3, (%a0)+
	move.l %d4, (%a0)+
	move.l %d5, (%a0)+
	move.l %d6, (%a0)+
	move.l %d7, (%a0)+
	move.l %a2, (%a0)+
	move.l %a3, (%a0)+
	move.l %a4, (%a0)+
	move.l %a5, (%a0)+
	move.l %a6, (%a0)+

	#save d0/d1/a0/a1
	move.l (%sp)+, (%a0)+
	move.l (%sp)+, (%a0)+
	move.l (%sp)+, (%a0)+
	move.l (%sp)+, (%a0)+
	
	#save sr
	move.w (%sp)+, (%a0)+
	
	#save pc
	move.l (%sp)+, (%a0)+
	
	#save sp/a7
	move.l %usp, %a1
	move.l %a1, (%a0)+
	
	jmp launchProcTrap15
	)");
	
asm(R"(
.global saveRegAndReturnToKern
saveRegAndReturnToKern:
	moveq #0,%d0
	move.w currentProc,%d0
	add.l %d0,%d0
	add.l %d0,%d0
	lea runningProc,%a0
	move.l (%a0,%d0.l),%a0
	add #32, %a0
	
	#save d2-d7 / a2-a6
	move.l %d2, (%a0)+
	move.l %d3, (%a0)+
	move.l %d4, (%a0)+
	move.l %d5, (%a0)+
	move.l %d6, (%a0)+
	move.l %d7, (%a0)+
	move.l %a2, (%a0)+
	move.l %a3, (%a0)+
	move.l %a4, (%a0)+
	move.l %a5, (%a0)+
	move.l %a6, (%a0)+

	#save d0/d1/a0/a1
	move.l (%sp)+, (%a0)+
	move.l (%sp)+, (%a0)+
	move.l (%sp)+, (%a0)+
	move.l (%sp)+, (%a0)+
	
	#save sr
	move.w (%sp)+, (%a0)+
	
	#save pc
	move.l (%sp)+, (%a0)+
	
	#save sp/a7
	move.l %usp, %a1
	move.l %a1, (%a0)+
	
	jmp kern
	)");

asm(R"(
.section .text
	.global shell_exe_start
shell_exe_start:
	.incbin "../Shell/bin/shell.bin"
)");

void __attribute__((interrupt)) DefaultInterrupt(){
	while(1){}
}

void __attribute__((interrupt)) IRQ7(void){
	int ret = PS2_INT();
	if(!ret) return;
	//if(ret == PS2_INT_RETURN_DUMP){
	//	//core_dump();
	//	asm("bra saveRegAndReturnToKern");
	//}
	if(ret == PS2_INT_RETURN_OS && currentProc != 0xFFFF){
		asm("bra saveRegAndReturnToKern");
	}
}
